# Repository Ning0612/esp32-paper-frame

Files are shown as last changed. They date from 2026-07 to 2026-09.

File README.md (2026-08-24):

# PaperFrame

[English](README.en.md) | [繁體中文](README.md)








PaperFrame 是以 ESP32-S3 驅動 7.3 吋 800×480 E6 全彩電子紙的離線優先
圖片輪播裝置。韌體使用 PlatformIO 管理的原生 ESP-IDF，不依賴 Arduino
framework；圖片處理、設定與管理 WebUI 在區域網路或裝置 AP 內即可運作。

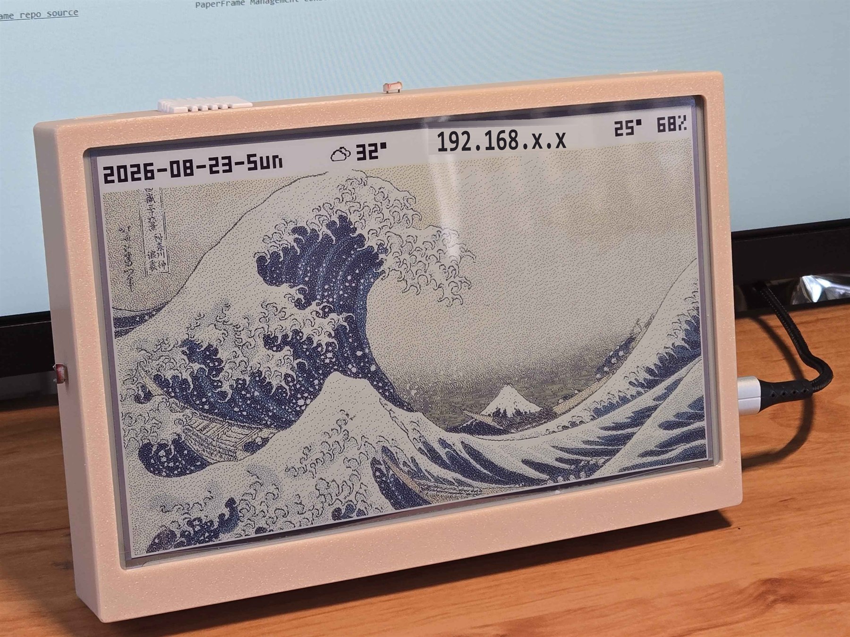
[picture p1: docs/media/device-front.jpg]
PaperFrame 實機：3D 列印相框中的 7.3 吋六色電子紙，狀態列顯示日期、天氣、IP 與室內溫溼度，下方是六色抖色後的《神奈川沖浪裏》


上圖是實機外觀，未經後製，只把狀態列上的區網位址遮成 `192.168.x.x`。狀態列
由左至右是日期與星期、目前天氣、裝置 IP 與 DHT22 的室內溫溼度；下方是輪播中
的圖片，這裡是公有領域的葛飾北齋《神奈川沖浪裏》經六色抖色後的實際顯示結果
（[出處](ASSET_CREDITS.md)）。外殼 CAD 一併收錄於
[`hardware/enclosure/`](hardware/enclosure/)，也附在每個 release 的 assets。

> **與其他 e-paper 專案的關係**
>
> PaperFrame 與 [epaper-home-display](https://github.com/Ning0612/epaper-home-display)
> （Raspberry Pi 多資訊智慧家庭面板）、[pico-paper-clock](https://github.com/Ning0612/pico-paper-clock)
> （Pico W／MicroPython 桌面時鐘）是**各自獨立維護的不同專案**，硬體平台、
> 韌體堆疊與用途都不同，彼此沒有取代關係。本專案的定位是 ESP32-S3 上的
> 離線優先全彩圖片輪播。
>
> 設計上借鑑了上述兩者與 [esp32-hydracup](https://github.com/Ning0612/esp32-hydracup)
> 的既有經驗（低記憶體串流、交易式檔案更新、FreeRTOS owner 邊界等），
> 採用的來源版本固定於 [參考來源與授權](docs/REFERENCES.md)。

## 管理介面

WebUI 全部資產（HTML／CSS／JS）都 gzip 後編進 app 韌體，不從任何 CDN 取得；
一次 OTA 會同時更新韌體與前端
（[ADR-0016](docs/adr/0016-embed-webui-assets-in-firmware.md)）。**唯一的例外是
天氣頁的地圖選點**：連得上網時會向 `tile.openstreetmap.org` 取圖磚（因此該頁
會把你選的位置附近座標揭露給該服務），連不上時同一個控制項自動改成純離線的
經緯度格線，其餘所有頁面完全不需要外部網路。以下截圖取自執行 v0.10.0 的實機。
管理介面上方導覽列現在也提供繁體中文／英文切換。

| 總覽 | 環境與在場 |
| --- | --- |
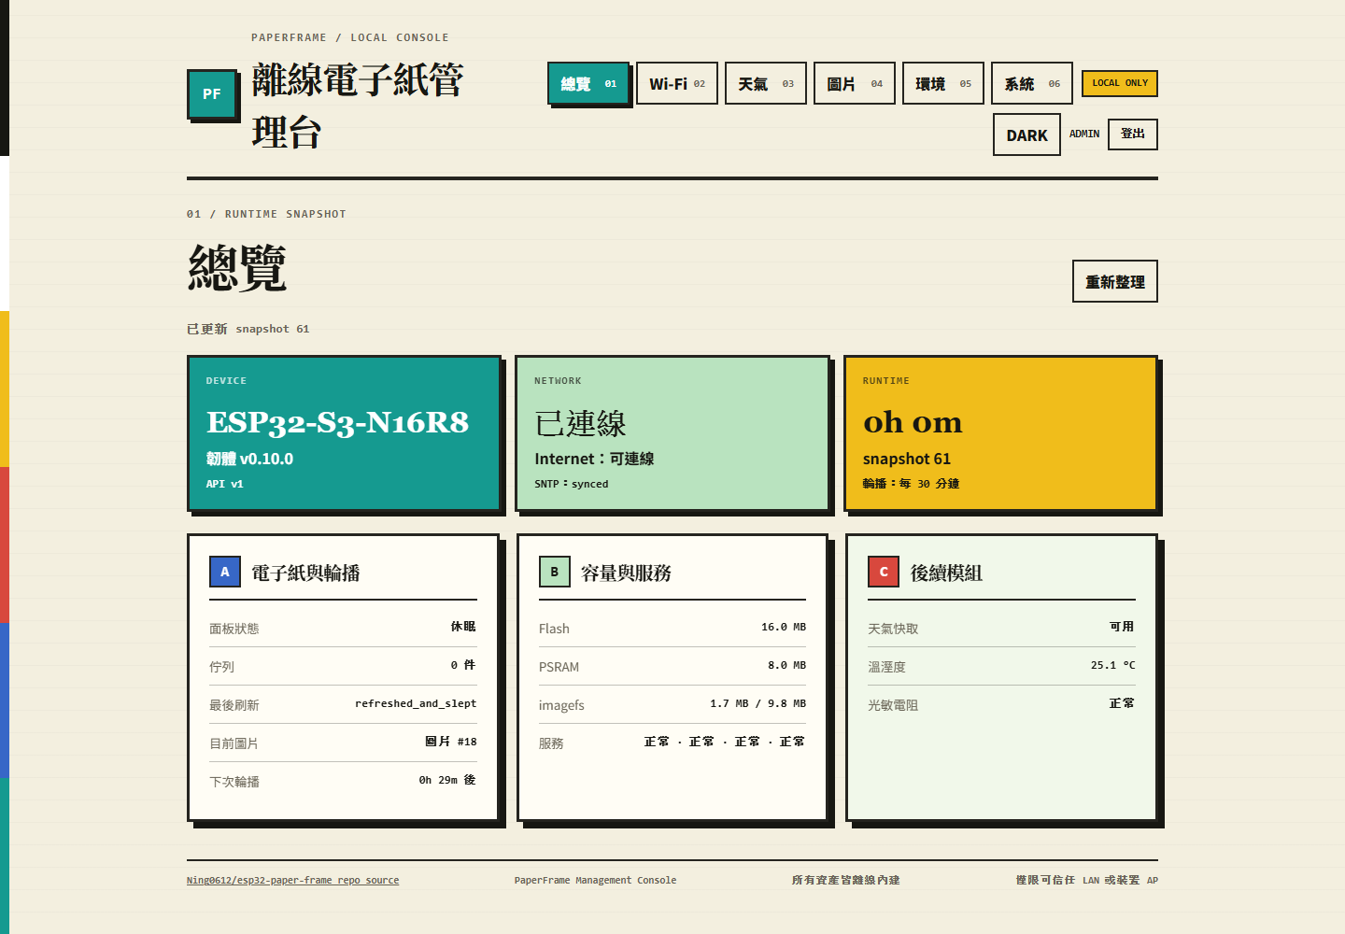
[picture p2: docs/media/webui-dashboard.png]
Dashboard
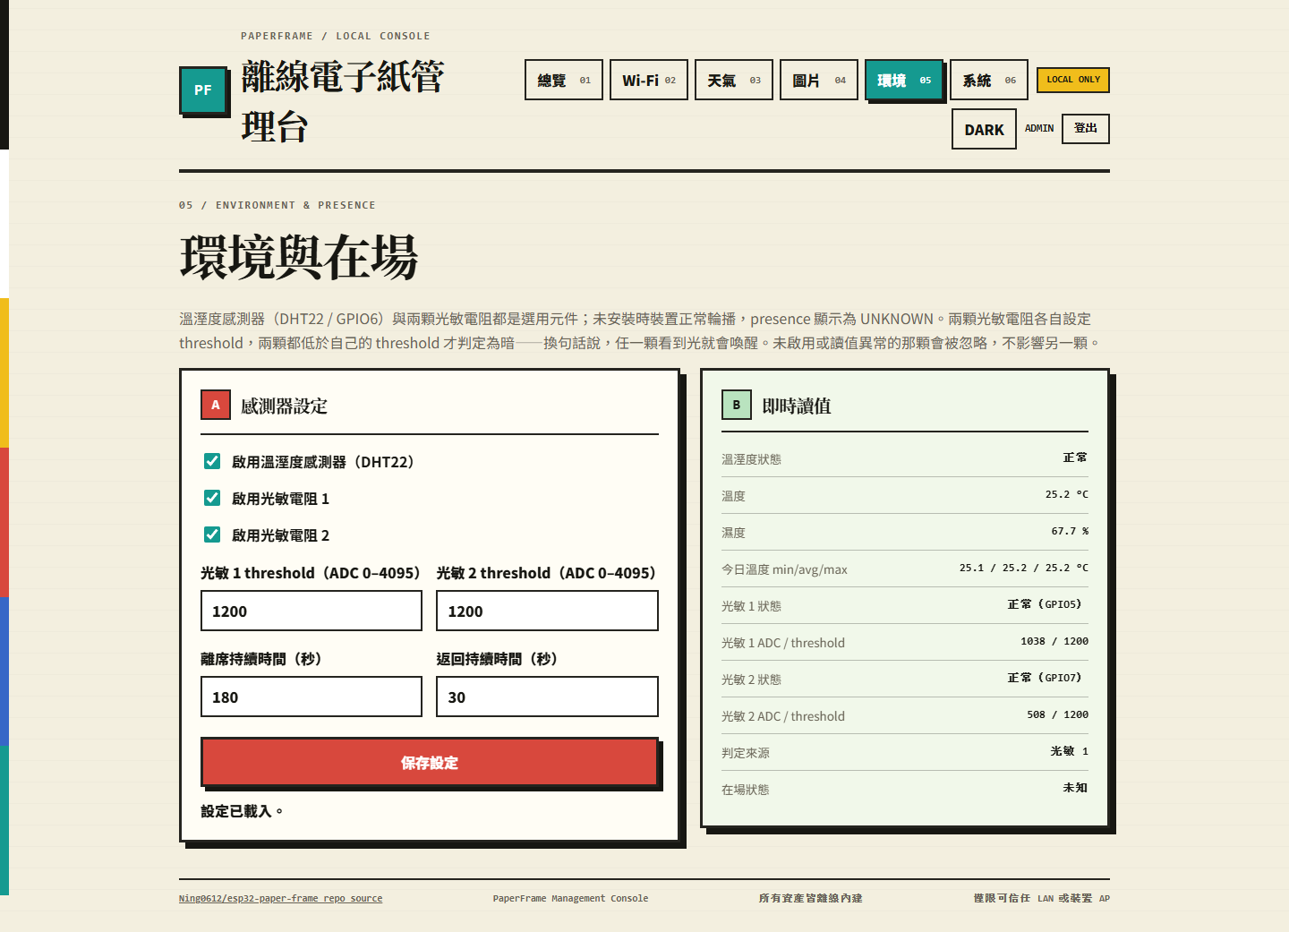
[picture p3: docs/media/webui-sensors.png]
環境與在場
|  |  |
| 面板狀態、輪播進度、容量與各服務健康度，全部來自單一 runtime snapshot。 | 兩顆光敏電阻各自設定 threshold 與即時讀值，並標示這次判定由哪一顆決定。 |

| 圖片處理 | 系統與韌體 |
| --- | --- |
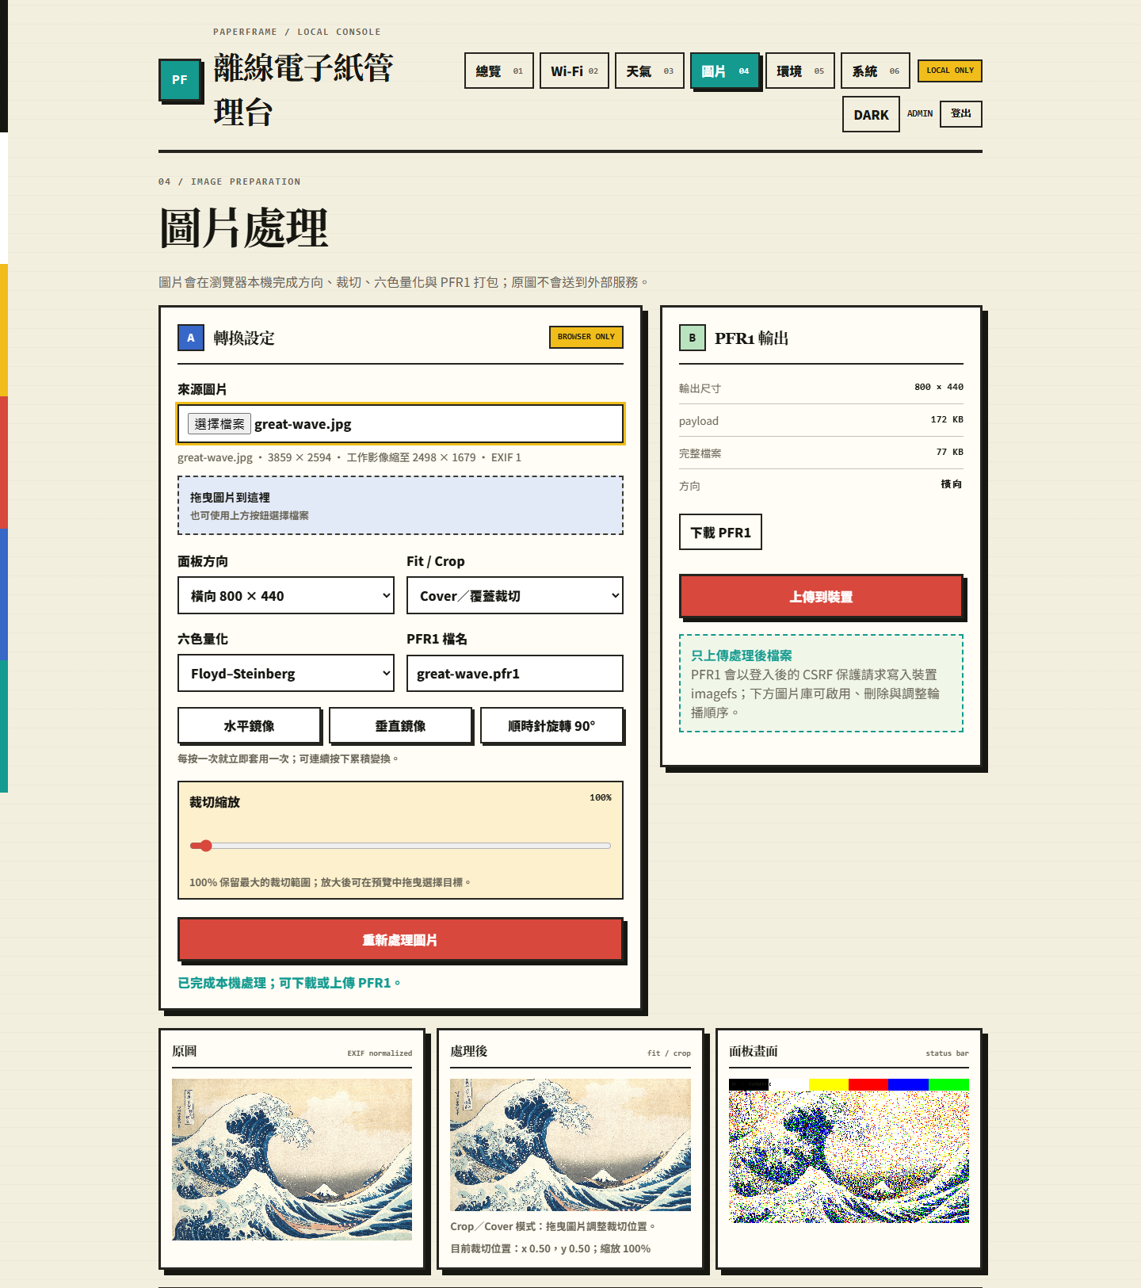
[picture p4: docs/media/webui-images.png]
圖片處理
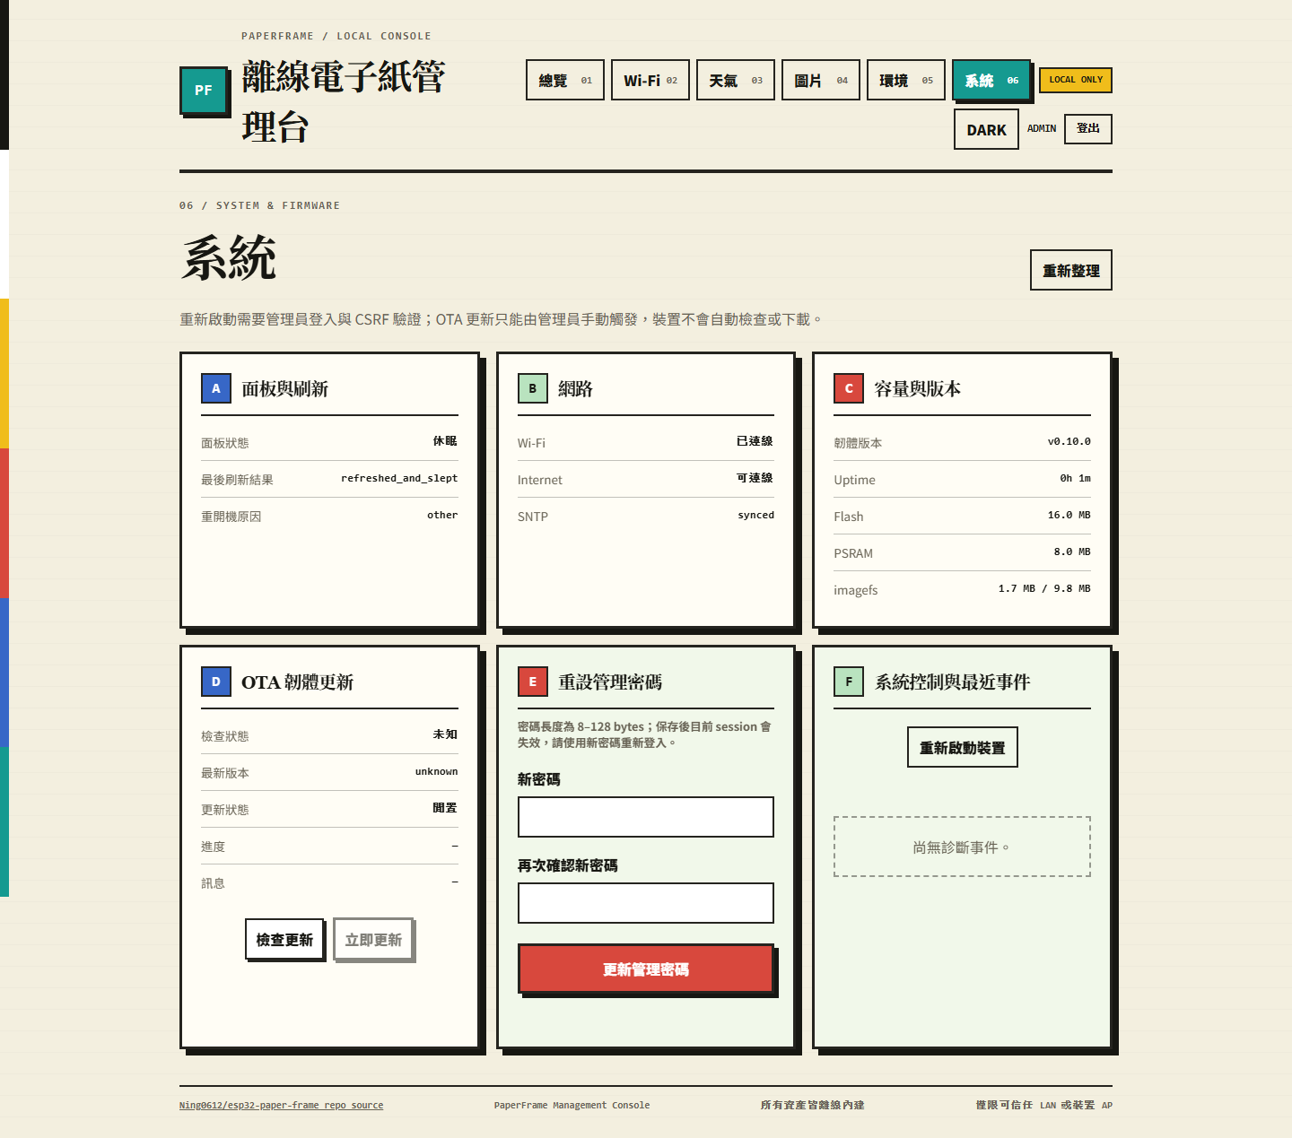
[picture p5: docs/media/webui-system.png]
系統
|  |  |
| 方向、裁切、六色量化與 PFR1 打包都在瀏覽器本機完成，原圖不會送到外部服務。範例圖為公有領域的葛飾北齋《神奈川沖浪裏》（[出處](ASSET_CREDITS.md)）。 | 面板與網路狀態、容量與版本、OTA 更新、重設管理密碼與診斷事件。 |

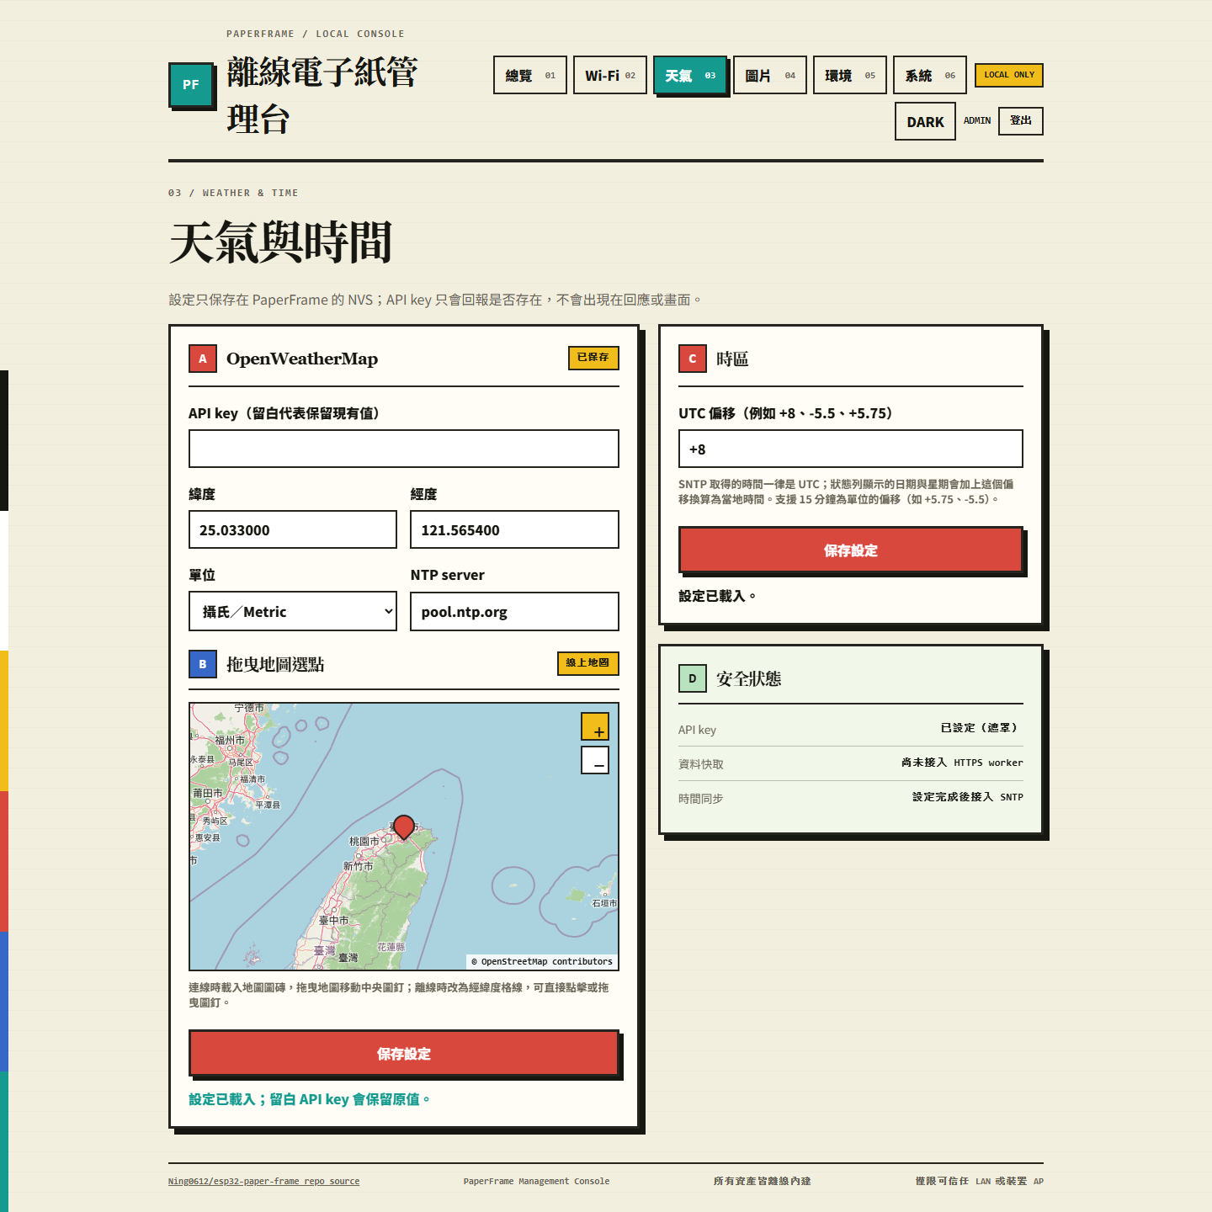
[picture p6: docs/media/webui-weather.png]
天氣與時間


天氣與時間頁：OpenWeatherMap 座標可直接在地圖上拖曳選點，離線時同一個
控制項改成經緯度格線；API key 只回報「是否已設定」，不會出現在任何回應或
畫面上。截圖中的座標是台北，不是實際部署位置。

## 目前狀態

目前狀態的唯一進度入口是 [專案狀態](docs/PROJECT_STATUS.md)，實機證據在
[硬體驗證紀錄](docs/hardware/VALIDATION.md)。摘要如下：

| 分類 | 目前結論 |
| --- | --- |
| MVP | **功能範圍已完成**並在實機使用中。**電源方案尚未設計**——目前直接接線供電，電池／低功耗運行未評估。 |
| 已完成 | Phase 1–8 的程式、host tests 與韌體 build 全部完成。 |
| 已實機驗證 | Phase 2–8 的**主要**路徑都有實機證據：面板刷新與 sleep 電流、AP／STA 配網與存取邊界、browser 出圖管線、五種斷電路徑、天氣四種失敗分類、OTA 端到端與 rollback fault injection，以及 Phase 7 的 DHT22、雙光敏通道與在場判定。這不代表每個 Phase 都沒有剩餘項目——見下一列。 |
| 待驗證 | 四個領域、八條路徑，都是低優先：`SensorSettings` v1→v2 的實機遷移與啟用但未接線通道的浮接讀值；presence 返回重畫、DHCP 續約後的位址重畫與 welcome 刷新失敗重試；AP grace 的 presence 例外與低 DMA heap guard；NVS 滿導致 `pf_config` 開啟失敗。 |
| 待決定 | production security profile（Secure Boot／Flash Encryption）與 MVP 以外的 P1 功能尚未納入開發。 |

2026-08-23 修掉兩個互相關聯的缺陷：刷新完成但面板 sleep 失敗時，結果讀起來
像「這次刷新沒成功」而導致重刷一張已經正確的畫面；以及每次開機 presence 由
`unknown` 收斂到 `present` 被當成「從離席返回」，白白多花一次 31 秒全刷。
修法見 [ADR-0019](docs/adr/0019-separate-frame-displayed-from-panel-slept.md)。
修正後的開機序列**已在實機確認只剩一次全刷**。

「實機證據已閉環」指的是那些行為已經在真實硬體上驗證過，**不等於 release
gate 已關閉**——[release checklist](docs/RELEASE_CHECKLIST.md) 的手動 on-device
檢查仍要每次依裝置狀況執行。Secure Boot 與 Flash Encryption 也尚未啟用，所以
這**不是**可直接放到不可信任網路的產品；設計前提是可信任 LAN 或裝置自身的 AP。

## 功能

括號內是**實機驗證狀態**。逐項證據以 [專案狀態](docs/PROJECT_STATUS.md) 與
[硬體驗證紀錄](docs/hardware/VALIDATION.md) 為準。

- **離線優先圖片輪播**：區網或裝置 AP 內即可完成全部操作，不依賴外部 CDN
  或後端服務（已驗證，含長時間輪播）。天氣功能本身需要 OpenWeatherMap，
  地圖選點需要 OSM 圖磚，兩者都是可停用的選配，停用後不影響輪播
- **PFR1 自有圖片格式**：瀏覽器端完成量化與打包，裝置只負責解碼與顯示，
  避免在 MCU 上做重量級影像處理（已驗證：browser 出圖、上傳與下載）
- **交易式 imagefs 儲存**：圖片分區與韌體分區分離，OTA 更新不會清除既有圖片
  （已驗證，含五種斷電路徑的故障注入）
- **管理 WebUI**：Dashboard、圖片管理、Wi-Fi、天氣、環境與 System 診斷頁，
  支援**繁體中文／英文語言切換**（已驗證：瀏覽器實機操作）
- **配網與認證**：AP portal 配網，blank-NVS 與 STA 重試耗盡時自動 fallback AP；
  PBKDF2 10,000 iterations、session 與 CSRF 保護（已驗證：存取邊界與認證邊界）
- **OTA 更新與 rollback**：以 GitHub Releases 為來源，A/B 分區與 rollback
  確認機制（已驗證：端到端更新與 rollback fault injection）
- **天氣資訊**：解析、快取與面板狀態列顯示（已驗證：真實 SNTP 與四種失敗分類）
- **可選環境感測**：DHT22 溫溼度與兩個獨立的光敏電阻通道。兩顆都低於各自
  threshold 才判定為暗、任一顆見光就喚醒；含移動平均濾波、離席／返回防抖與
  離席白屏（已驗證：讀值、拔除降級、雙通道校正、AND 語意與 180／30 秒防抖計時）

## 文件入口

請先讀 [文件入口與分類](docs/README.md)；若只想知道現在做到哪裡，讀
[專案狀態](docs/PROJECT_STATUS.md)。ADR、current contract、硬體證據與歷史
計畫的權威關係都集中在該入口說明，不需要從所有文件開始閱讀。

## 開源快速開始

開發環境需要 Windows 11、Python 3.13、PlatformIO Core 6.1.19 與原生 ESP-IDF。
在乾淨 checkout 中執行：

```powershell
uv venv --seed --python 3.13 .venv
uv pip install --python .\.venv\Scripts\python.exe -r requirements-dev.txt
.\.venv\Scripts\pio.exe test -e native
.\.venv\Scripts\pio.exe run
```

`native` 是不需要硬體的 host test；韌體 upload、面板、Wi-Fi、NVS、OTA 與
斷電復原則依 [燒錄操作](docs/hardware/FLASHING.md)、[硬體驗證紀錄](docs/hardware/VALIDATION.md)
與 [release checklist](docs/RELEASE_CHECKLIST.md) 執行。請勿把 host/build 結果
當成實機驗證。

**拿到全新板子時，`pio run -t upload` 不足以讓它開機**：日常上傳只寫 app slot，
不含 bootloader。首次燒錄與 bootloader 更新見
[新裝置首次燒錄](docs/hardware/FLASHING.md#新裝置首次燒錄含-bootloader)；
OTA 的回滾保護取決於 bootloader 版本，判斷方式見
[bootloader 是否具備回滾保護](docs/hardware/FLASHING.md#bootloader-是否具備回滾保護)。

## 硬體

完整元件清單、接線與腳位限制見 [硬體規格與接線](docs/hardware/HARDWARE.md)；
腳位分配的決策與理由固定在 [ADR-0003](docs/adr/0003-fix-phase2-display-integration.md)。
以下為常用摘要。

| 類別 | 元件 | 狀態 |
| --- | --- | --- |
| 主控 | ESP32-S3-N16R8（16 MB Flash、8 MB octal PSRAM） | 必要 |
| 顯示器 | Waveshare 7.3 吋 e-Paper HAT (E)，800×480 E6 六色 | 必要 |
| 溫溼度 | DHT22／AM2302 | 可選；已實機驗證 |
| 光感測 | 光敏電阻＋分壓 ×2，接 `ADC1_CH4` 與 `ADC1_CH6` | 可選；兩顆同時接線已實機驗證。**只接一顆時必須在 WebUI 停用另一顆**（[原因](docs/hardware/HARDWARE.md)） |
| 外殼 | 3D 列印，CAD 見 [`hardware/enclosure/`](hardware/enclosure/) | 可選 |
| 供電 | 直接接線（開發板 USB） | **尚未設計**；電池／低功耗運行未評估 |

顯示器接線（3.3 V logic、SPI2、mode 0、MSB-first、起始 clock 2 MHz）：

| HAT | DIN | CLK | CS | DC | RST | BUSY |
| --- | --- | --- | --- | --- | --- | --- |
| ESP32-S3 | GPIO11 | GPIO12 | GPIO10 | GPIO13 | GPIO14 | GPIO4 |

感測器腳位：光敏 ADC 通道 1 = GPIO5（`ADC1_CH4`）、DHT data = GPIO6、光敏 ADC
通道 2 = GPIO7（`ADC1_CH6`）；GPIO8／GPIO9 保留給未來 I²C。兩個光敏通道都必須
在 ADC1——ADC2 在 Wi-Fi 啟用時由 Wi-Fi driver 佔用。分壓接法、極性與校正流程見
[硬體與接線](docs/hardware/HARDWARE.md)，合併判定規則見
[ADR-0018](docs/adr/0018-dual-photoresistor-channels.md)。**改接線前務必先讀 ADR-0003 的腳位限制**——octal PSRAM 佔用
GPIO33–37、native USB 佔用 GPIO19–20，GPIO0／3／45／46 是 strapping pins，
GPIO4 已給 BUSY 不得再作 ADC。

### 外殼

[`hardware/enclosure/`](hardware/enclosure/) 收錄桌上型相框外殼，每個零件同時
提供 **STEP（AP214）** 與 **STL**：STEP 用來改尺寸或重新出圖，STL 直接送切片
軟體。零件清單、量到的外接方框尺寸與已知問題見
[該目錄的 README](hardware/enclosure/README.md)。同一份內容也會以
`paperframe-enclosure.zip` 附在每個 GitHub Release 的 assets。

六個零件的檔名前綴就是組裝堆疊順序，列印與組裝可以照號碼走。

## 架構概覽

韌體拆成 12 個 ESP-IDF component，`src/app_main.cpp` 只負責啟動與接線。
跨 component 的協調集中在 `pf_runtime` 的 `RuntimeCoordinator`：顯示、儲存、
網路與 OTA 各自有明確的 owner，彼此以訊息往來而不是共享可變狀態，避免網路或
儲存 I/O 阻塞面板刷新。

各 component 的設計理由與取捨固定在 [ADR](docs/adr/README.md)，本節只是導覽。

| Component | 職責 |
| --- | --- |
| `pf_runtime` | `RuntimeCoordinator`、runtime snapshot、diagnostics event、reboot reason、韌體版本 |
| `pf_display` | epd7in3e driver（SPI2）、DisplayTask、owner contract |
| `pf_carousel` | 輪播排程、image frame 與 welcome frame |
| `pf_image` | PFR1 格式解碼 |
| `pf_storage` | LittleFS backend、image store、catalog、transaction 與 recovery、storage worker |
| `pf_network` | AP／STA 狀態機、配網服務、掃描結果、SNTP 時間同步 |
| `pf_web` | HTTP server、Dashboard／health serializer、各設定表單、access policy |
| `pf_auth` | PBKDF2 密碼驗證、session 與 CSRF |
| `pf_config` | NVS 設定 schema、憑證與 secure memory |
| `pf_ota` | GitHub Releases 下載、A/B 分區與 rollback 確認 |
| `pf_weather` | 天氣解析、快取與 worker |
| `pf_sensors` | DHT22 與光敏 ADC driver、濾波與 presence 判定 |

測試分兩層：`test/` 是不需要硬體的 host test（`pio test -e native`），
`test_embedded/` 是需要實機的 on-target test。**host test 通過不等於實機驗證**，
兩者的分界與現況見 [硬體驗證紀錄](docs/hardware/VALIDATION.md)。

## 公開基線與已知限制

- 目標基線是 ESP32-S3-N16R8、16 MB Flash、8 MB octal PSRAM 與 7.3 吋
  800×480 E6 全彩電子紙；光敏與溫溼度感測器是可選周邊（見上方硬體段）。
- WebUI 與圖片管理以離線優先為原則：所有前端資產編在韌體裡，圖片處理在
  瀏覽器本機完成。唯一會連外的是天氣頁的地圖選點（OSM 圖磚）與天氣抓取
  本身，兩者都可停用，停用後整套功能仍可在無網際網路的區網內運作。
- 電子紙完整刷新預設 30 分鐘，可設 10 分鐘至 24 小時（1440 分鐘）；實測一次
  全刷約 31 秒，每次刷新後面板進入 sleep。31 秒是 E6 面板的物理特性，不是
  可調優的軟體延遲。
- 未啟用 Secure Boot 與 Flash Encryption，僅適用於可信任 LAN 或裝置自身的 AP。
- 仍有八條低優先的實機驗證路徑未閉環（見上方目前狀態）。
- 真實裝置測試資料、裝置識別資訊與執行期 imagefs 不屬於公開 repository 內容。

## 開發基線

- Windows 11 / PowerShell 7
- [uv](https://docs.astral.sh/uv/getting-started/installation/) 0.11.26
- Python 3.13 project venv
- PlatformIO Core 6.1.19
- PlatformIO Espressif 32 platform（版本由 Phase 1 build 固定）
- Native ESP-IDF

上列是實際使用並通過 build 的組合。**Linux 與 macOS 未測試**——工具鏈本身跨平台，
但本專案的指令範例、`uv` 路徑與燒錄流程都以 Windows 為準，其他平台需自行調整。
CI 在 `ubuntu-latest` 上跑 host test 與韌體 build，所以程式本身可在 Linux 編譯，
未測試的是本文件描述的 Windows 操作流程。

建立工具環境：

```powershell
uv venv --seed --python 3.13 .venv
uv pip install --python .\.venv\Scripts\python.exe -r requirements-dev.txt
.\.venv\Scripts\pio.exe --version
```

韌體的標準 build、native USB 單命令 upload 與 port 盤點命令：

```powershell
.\.venv\Scripts\pio.exe run
.\.venv\Scripts\pio.exe run -e paperframe-s3 -t upload
.\.venv\Scripts\pio.exe device list
```

標準 upload 會依 VID:PID `303A:1001` 自動選擇 ESP32-S3 native USB，以
`usb_reset` 進入 ROM，讀取 `otadata` 後更新目前啟動的 OTA app slot，完成後
自動重置。首次、RGB demo 或 app 損壞無法自動 reset 時，才需在 reset 同時拉低
GPIO0、GPIO46。完整安全步驟、app-only slot 限制與測試後恢復方式見
[ESP32-S3 燒錄操作](docs/hardware/FLASHING.md)。

這條路徑**不會更新 bootloader 或 partition table**——新板子的首次燒錄、以及
既有裝置要取得 OTA 回滾保護時的 bootloader 更新，都在同一份文件的
[新裝置首次燒錄](docs/hardware/FLASHING.md#新裝置首次燒錄含-bootloader)一節。

## 文件

- [文件入口與分類](docs/README.md)
- [專案狀態](docs/PROJECT_STATUS.md)
- [架構決策](docs/adr/README.md)
- [硬體規格與接線](docs/hardware/HARDWARE.md)
- [硬體驗證紀錄](docs/hardware/VALIDATION.md)
- [外殼 CAD](hardware/enclosure/README.md)
- [參考來源與授權](docs/REFERENCES.md)
- [歷史需求草案](docs/archive/Guild.md)

## License

本專案採用 [MIT License](LICENSE)。參考專案與未來第三方 dependency 的授權
仍需分別遵守；參考概念不代表可省略原始碼 attribution 或第三方 notice。
韌體內建的天氣圖示改繪自 erikflowers/weather-icons（SIL OFL-1.1），
attribution 見 [ASSET_CREDITS.md](ASSET_CREDITS.md) 與
[THIRD_PARTY_NOTICES.md](THIRD_PARTY_NOTICES.md)。

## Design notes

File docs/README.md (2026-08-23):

# 文件入口與分類

PaperFrame 的文件分成「目前狀態」、「現行契約」、「設計決策」、「實機證據」
與「歷史背景」。一般讀者不需要從所有文件開始閱讀。

## 主要文件

按以下順序即可掌握專案：

1. [根目錄 README](../README.md)：專案用途、開源快速開始與公開限制。
2. [PROJECT_STATUS.md](PROJECT_STATUS.md)：唯一的完成／待驗證／待決定摘要。
3. [ADR index](adr/README.md)：為什麼採用目前架構、格式與安全決策。
4. [RELEASE_CHECKLIST.md](RELEASE_CHECKLIST.md)：公開版的 release gate。
5. [CONTRIBUTING.md](../CONTRIBUTING.md) 與 [SECURITY.md](../SECURITY.md)：如何參與與回報問題。

## 只有在修改該領域時才讀

這些文件是現行 contract，不是進度清單：

- [AUTHENTICATION.md](AUTHENTICATION.md)、[PROVISIONING.md](PROVISIONING.md)
- [WEBUI.md](WEBUI.md)、[HEALTH_API.md](HEALTH_API.md)
- [STORAGE.md](STORAGE.md)、[WEATHER.md](WEATHER.md)
- [formats/PFR1.md](formats/PFR1.md)、[formats/PFC1.md](formats/PFC1.md)

## 硬體規格

- [hardware/HARDWARE.md](hardware/HARDWARE.md)：元件清單、接線與腳位限制，
  回答「要買什麼、怎麼接」。**它不是決策權威**——腳位分配的理由固定在
  [ADR-0003](adr/0003-fix-phase2-display-integration.md)、感測器行為在
  [ADR-0006](adr/0006-sensor-drivers-and-presence.md)（光敏電阻的雙通道
  部分已由 [ADR-0018](adr/0018-dual-photoresistor-channels.md) 取代），
  衝突時以 ADR 為準。
  根目錄 README 的「硬體」段是本檔摘要；**重要資訊刻意在兩處重複**，
  讓讀者不必先點進 docs 才知道要買什麼板子。

## 證據與操作

- [hardware/VALIDATION.md](hardware/VALIDATION.md)：append-only 實機證據與目前未閉環項目。
- [hardware/FLASHING.md](hardware/FLASHING.md)：燒錄與 imagefs 保護操作，
  包含**新裝置首次燒錄**（日常 upload 只寫 app slot，不含 bootloader，
  空白板無法只靠它開機）與**判斷 bootloader 是否具備 OTA 回滾保護**。

- [../hardware/enclosure/README.md](../hardware/enclosure/README.md)：3D 列印外殼的零件清單、量到的尺寸與已知問題；CAD 本體（STEP／STL）
  與韌體一起附在每個 GitHub Release 的 assets。

這兩份文件回答「實際測了什麼」與「如何操作」，不取代
[PROJECT_STATUS.md](PROJECT_STATUS.md) 的進度摘要。

## 歷史與參考

- [Guild.md](archive/Guild.md)：原始需求 provenance，不是現行規格。
- [IMPLEMENTATION_PLAN.md](archive/IMPLEMENTATION_PLAN.md)：階段、acceptance 與開發歷史，
  不取代 current contract 或本文件的狀態摘要。
- [REFERENCES.md](REFERENCES.md)、[ASSET_CREDITS.md](../ASSET_CREDITS.md) 與
  [THIRD_PARTY_NOTICES.md](../THIRD_PARTY_NOTICES.md)：來源與授權追溯。

## 目前刻意保留在主文件區

- `hardware/VALIDATION.md`：頂端有目前未閉環索引，後面的 append-only 紀錄仍是可追溯的實機證據；不把整份移入 archive。
- `hardware/FLASHING.md` 與 `RELEASE_CHECKLIST.md`：仍會直接用於燒錄、驗證與發布，屬於現行操作文件。
- ADR：目前 18 份都是已接受的公開設計決策；即使部分決策後來被新 ADR 取代，也要保留決策歷史，不搬到 archive。
- `REFERENCES.md`、`ASSET_CREDITS.md`、`THIRD_PARTY_NOTICES.md`：授權與 provenance 是開源交付的一部分，不是過時開發計畫。
- `AUTHENTICATION.md`、`PROVISIONING.md`、`WEBUI.md`、`HEALTH_API.md`、`STORAGE.md`、`WEATHER.md` 與 `formats/`：描述目前仍有效的外部行為與資料格式。

若日後仍需要縮短硬體紀錄的日常閱讀範圍，可再把較早的 append-only 歷史段落拆成
`docs/archive/`，但必須保留 `VALIDATION.md` 的目前未閉環索引與指向歷史證據的連結。

新增文件前，先確認內容不能放入上述既有分類；避免建立另一份**進度表**或重複的
**API／硬體驗證說明**。

**重複的界線**：常用且會影響「要不要動手」的資訊——例如買什麼板子、接哪幾支腳、
現在能不能宣稱 production-ready——**允許在根目錄 README 與 `docs/` 同時出現**，
讓讀者不必層層點進來才看得到。但必須符合兩個條件：

1. 明確標示哪一份是權威（決策以 ADR 為準、進度以 `PROJECT_STATUS.md` 為準、
   實機證據以 `VALIDATION.md` 為準），摘要處註明它是摘要；
2. 改動時兩處一起改——摘要與權威來源不一致，比沒有摘要更糟。

不適用於進度狀態與實機驗證結果：那兩類只在單一入口維護，其他地方一律用連結。

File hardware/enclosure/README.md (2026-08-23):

# PaperFrame 相框外殼 CAD

7.3 吋 800×480 E6 電子紙桌上型相框的外殼素材，SolidWorks 2019 建模，
每個零件同時提供 **STEP（AP214）** 與 **STL**：STEP 用來改尺寸或重新出圖，
STL 直接送切片軟體列印。組裝後的實機外觀見
[README 的實機照片](https://github.com/Ning0612/esp32-paper-frame/blob/main/docs/media/device-front.jpg)。

## 組裝順序

檔名前綴就是堆疊順序，由面板側往背面依序疊上去：

```
01 螢幕背板殼
   └─ 電子紙面板
02 相框外框
03 電子零件背板
   └─ 電子零件（ESP32-S3、感測器、配線）
04 腳架旋轉件
05 相框背板
06 腳架
```

## 零件

尺寸是從 STL 幾何量出來的外接方框（bounding box，單位 mm），不是標稱設計值。

| 檔名 | 零件 | 外接方框 (X×Y×Z) |
| --- | --- | --- |
| `01-screen-back-shell` | 螢幕背板殼 | 176 × 116 × 3 |
| `02-outer-frame` | 相框外框 | 180 × 120 × 26 |
| `03-electronics-back-panel` | 電子零件背板 | 176 × 116 × 4 |
| `04-stand-pivot` | 腳架旋轉件 | 16 × 11 × 16 |
| `05-frame-back-panel` | 相框背板 | 176 × 120 × 19 |
| `06-stand` | 腳架 | 30 × 88 × 4 |

原始檔名對照（重新命名前）：

| 目前檔名 | 原始檔名 |
| --- | --- |
| `01-screen-back-shell` | `epaper-screen-1` |
| `02-outer-frame` | `epaper-screen-2` |
| `03-electronics-back-panel` | `epaper-screen-4` |
| `04-stand-pivot` | `epaper-screen-5` |
| `05-frame-back-panel` | `epaper-screen-3` |
| `06-stand` | `epaper-screen-6` |

## 已知限制

- 列印材料、層高、填充率與支撐設定尚未記錄。
- 上表尺寸取自 STL 的三角網格，是實際會列印出來的幾何。**STEP 與 STL 是否
  完全等價未經逐面比對**——本專案沒有 CAD kernel 可以做這件事，只確認過兩者
  的外形尺寸一致。

## 授權

與本 repository 相同（MIT），見 [LICENSE](https://github.com/Ning0612/esp32-paper-frame/blob/main/LICENSE)。

本檔會與 CAD 一起打包成 GitHub Release 的 `paperframe-enclosure.zip`，
所以上面的連結刻意用絕對網址——解壓後的資料夾沒有 repository 的目錄結構。

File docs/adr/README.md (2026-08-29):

# Architecture Decision Records

會影響硬體接線、partition、持久資料格式、跨 task ownership、安全邊界或
對外 API 的決策，使用 ADR 固定。小型實作細節留在程式與測試，不為每個
函式建立 ADR。

## 與其他文件的權威關係

已接受且未被取代的 ADR 是跨模組、硬體、持久格式與安全決策的權威來源；
新 ADR 取代舊決策時，必須保留歷史檔案並明確標示 `Supersedes`。目前 API、
WebUI、儲存、天氣、認證與 binary format 的操作契約位於 `docs/` 主題文件；
`docs/archive/IMPLEMENTATION_PLAN.md` 只做追溯，`hardware/VALIDATION.md` 只做證據
紀錄，`docs/archive/Guild.md` 只保留原始需求 provenance。

## 開源公開範圍

ADR 是本專案的公開設計決策歷史，建議保留在開源 repository。公開 ADR 應
說明已接受、被取代或拒絕的決策、影響範圍與理由，讓貢獻者理解「為什麼」
而不只看到目前的實作。

ADR 不應包含密碼、API key、session token、Wi-Fi credential、真實裝置識別、
私人路徑或未脫敏的內部 log。原始討論、私人測試紀錄與尚未形成決策的草稿
應留在 repository 外；被取代的 ADR 可保留，但必須標明 superseded 與取代它的
文件。開源貢獻流程請見根目錄的 `CONTRIBUTING.md`。

## 命名

```text
NNNN-short-imperative-title.md
```

編號遞增且不重用。已接受 ADR 不原地改寫結論；若決策改變，以新 ADR
取代並在兩份文件互相連結。

## 必要段落

```markdown
# ADR-NNNN：標題

- Status: proposed | accepted | superseded
- Date: YYYY-MM-DD
- Supersedes: none | ADR-NNNN

## Context
## Decision
## Consequences
## Verification
```

## Index

- [ADR-0001：建立專案技術與授權基線](0001-project-foundations.md)
- [ADR-0002：固定 ESP32-S3-N16R8 開發 profile](0002-esp32-s3-n16r8-profile.md)
- [ADR-0003：固定 Phase 2 顯示器接線與 driver contract](0003-fix-phase2-display-integration.md)
- [ADR-0004：凍結 imagefs-preserving partition layout](0004-freeze-image-preserving-partitions.md)（layout 與其 SHA-256 仍有效；`webfs` 的用途已由 ADR-0016 改為 reserved）
- [ADR-0005：WeatherWorker HTTPS 契約與狀態列渲染基線](0005-weather-worker-and-status-bar.md)（「字型與圖示授權」的圖示部分已被 ADR-0013 取代；「Rate limit / 更新頻率」子決策與 location/language 欄位已被 ADR-0014 取代）
- [ADR-0006：感測器 driver 來源與在場/離席判定機制](0006-sensor-drivers-and-presence.md)（單一光敏電阻的判定與 `GET /api/v1/sensors` 的 `light` schema 已被 ADR-0018 取代）
- [ADR-0007：PBKDF2 迭代次數與同步登入決策（G6 收斂）](0007-auth-pbkdf2-iterations-and-sync-login.md)
- [ADR-0008：OTA 韌體來源、TLS 信任、Rollback 確認時機與 Release 慣例](0008-ota-github-releases-and-rollback.md)（Context 第 1 條「OTA 不做 webfs」已被 ADR-0016 取代）
- [ADR-0009：PFR1 Payload 壓縮與 PFC1 目錄容量上限](0009-pfr1-payload-compression-and-catalog-cap.md)（`kCatalogMaxEntries` 部分已被 ADR-0010 取代）
- [ADR-0010：撤銷 PFC1 目錄容量上限拉高，維持 48 筆](0010-revert-catalog-cap-raise-ram-constraint.md)
- [ADR-0011：PFR1 壓縮功能的 PSRAM／flash cache-disable 交錯安全性調查](0011-psram-flash-cache-disable-safety.md)
- [ADR-0012：RAM 重構後重新拉高 PFC1 目錄容量上限至 64 筆](0012-raise-catalog-cap-after-ram-reclaim.md)（取代 ADR-0010 的 `kCatalogMaxEntries` 部分）
- [ADR-0013：天氣圖示改用轉檔自第三方 OFL-1.1 素材的點陣圖](0013-weather-icon-bitmaps-from-third-party-ofl-source.md)（取代 ADR-0005「字型與圖示授權」的圖示部分）
- [ADR-0014：天氣更新改為面板刷新觸發，WebUI 改用地圖選點](0014-weather-panel-refresh-cadence-and-map-picker.md)（取代 ADR-0005「Rate limit / 更新頻率」子決策與 location/language 欄位）
- [ADR-0015：開機首張真實圖片等待 NTP／天氣就緒或逾時](0015-first-image-waits-for-ntp-and-weather.md)（Update 2026-08-23：空圖庫的 welcome frame 在取得區網 IP 後重畫一次）
- [ADR-0016：WebUI 資產 gzip 後編入 app image，webfs 分割區轉為 reserved](0016-embed-webui-assets-in-firmware.md)（取代 ADR-0008 Context 第 1 條）
- [ADR-0017：設定載入的降級邊界與中央記錄的寫入規則](0017-config-degradation-boundaries.md)
- [ADR-0018：光敏電阻擴充為兩個獨立通道，兩顆都變暗才判定為暗](0018-dual-photoresistor-channels.md)（取代 ADR-0006 的單一光敏判定與 `light` schema；增修 ADR-0003 的 G2 保留腳位表）
- [ADR-0019：把「畫面已上到面板」與「面板已進入 deep sleep」分開回報](0019-separate-frame-displayed-from-panel-slept.md)（取代 ADR-0003 Verification 的「成功 result 只能在 driver 回報 deep sleep 後發布」；driver 行為本身不變）
- [ADR-0020：光敏電阻 ADC 飽和只是診斷資訊，不再排除離席判定](0020-light-clip-is-diagnostic-not-presence-gate.md)（取代 ADR-0006／ADR-0018 的「saturated 不得觸發離席」條款，`saturated` 列舉值拆分為 `low_clipped`／`high_clipped`）

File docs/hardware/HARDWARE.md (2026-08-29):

# 硬體規格與接線

本文件回答「要買什麼、怎麼接」。**它不是設計決策的權威來源**——腳位分配、
SPI 參數與 driver 契約的決策與理由固定在
[ADR-0003](../adr/0003-fix-phase2-display-integration.md)，感測器行為固定在
[ADR-0006](../adr/0006-sensor-drivers-and-presence.md)。兩者衝突時以 ADR 為準。

實機驗證狀態見 [硬體驗證紀錄](VALIDATION.md)，燒錄步驟見
[燒錄操作](FLASHING.md)。

## 元件清單

| 類別 | 元件 | 規格 | 狀態 |
| --- | --- | --- | --- |
| 主控 | ESP32-S3 開發板 | **ESP32-S3-N16R8**：16 MB Flash、8 MB octal PSRAM | 必要。octal PSRAM 是目標基線，framebuffer 與圖片處理依賴它 |
| 顯示器 | Waveshare 7.3 吋 e-Paper HAT (E) | 800×480、E6 六色（黑／白／黃／紅／藍／綠） | 必要。產品與接線說明見 [官方 manual](https://www.waveshare.com/wiki/7.3inch_e-Paper_HAT_%28E%29_Manual) |
| 溫溼度感測器 | DHT22／AM2302 | 3.3 V 供電，單線資料 | **可選**。2026-08-23 已完成實機驗證（讀值與拔除降級） |
| 光感測器 | 光敏電阻（LDR）＋分壓電路 **×2** | 通道 1 輸出接 `ADC1_CH4`、通道 2 接 `ADC1_CH6` | **可選**，但只接一顆時必須在 WebUI 停用另一顆（見下方「只接一顆」）。兩顆同時接線已於 2026-08-23 完成實機驗證 |
| 外殼 | 3D 列印外殼 | — | 可選。STEP／STL 見 [`hardware/enclosure/`](../../hardware/enclosure/README.md)，並附在每個 GitHub Release 的 assets |
| 供電 | — | — | **尚未設計**。目前直接接線供電（開發板 USB），電池／UPS 與低功耗運行模式都未評估 |

> 標為「可選」的周邊未安裝時，韌體回傳 JSON `null` 而非 `0`，Dashboard 顯示
> 「未安裝／未啟用」——這是 [ADR-0006](../adr/0006-sensor-drivers-and-presence.md)
> 的明確決策，不要用 `0` 代替缺席。

## 接線

HAT 與 ESP32-S3 全部使用 **3.3 V logic**。

### 顯示器（SPI2）

| HAT 訊號 | ESP32-S3 | 用途 |
| --- | --- | --- |
| VCC | 3V3 | 電源 |
| GND | GND | 共地 |
| DIN | GPIO11 | SPI2 MOSI |
| CLK | GPIO12 | SPI2 SCK |
| CS | GPIO10 | chip select，低有效（由 SPI master hardware 控制） |
| DC | GPIO13 | data／command |
| RST | GPIO14 | panel reset，低有效 |
| BUSY | GPIO4 | panel status input，低電位為 busy |

SPI 參數：SPI2、mode 0、MSB-first、起始 clock 2 MHz。2 MHz 是 upstream 各平台
設定不一致時採取的保守值；**只有實機波形與刷新驗證通過後才能提高**（ADR-0003）。

### 感測器腳位

| 用途 | ESP32-S3 |
| --- | --- |
| 光敏電阻 ADC 通道 1 | GPIO5（`ADC1_CH4`） |
| DHT data | GPIO6 |
| 光敏電阻 ADC 通道 2 | GPIO7（`ADC1_CH6`）（ADR-0018） |
| I²C SDA | GPIO8（保留給未來 I²C 感測器） |
| I²C SCL | GPIO9（保留給未來 I²C 感測器） |

兩個光敏通道**都必須在 ADC1**：ESP32-S3 的 ADC2 在 Wi-Fi 啟用時由 Wi-Fi
driver 佔用，`adc_oneshot_read()` 會回 `ESP_ERR_TIMEOUT`。本裝置 Wi-Fi 常駐，
ADC2 等於不可用。ADC1 只涵蓋 GPIO1–GPIO10。若 GPIO7 因排針佈局不便，備援是
GPIO1（`ADC1_CH0`）或 GPIO2（`ADC1_CH1`）。改腳位要**同時**改兩處：
`sensor_task_esp_idf.cpp` 的 `kLightAdcChannels`（實際讀哪個 ADC 通道）與
`light_sensor.hpp` 的 `kLightChannelGpios`（API 與 WebUI 回報哪支腳）。
兩者是同一支腳的兩種說法，只改一邊會讓顯示與實際接線不符。

#### 只接一顆光敏電阻時

**必須在 WebUI 的環境頁把沒有接線的那個通道取消勾選。** 這不是最佳化，
是必要步驟：

- 停用是 `SensorTask` 取樣迴圈的第一個分支，該通道的 ADC **完全不會被讀**，
  浮接與否都無所謂；合併判定也會忽略它（`combine_light_channels()` 在還有
  其他 decision-capable 通道時跳過已停用／未偵測到／讀取錯誤的通道）。
- 啟用但沒接線時**沒有防線**：`raw ≤ 10` 或 `raw ≥ 4085` 只回報
  `low_clipped`／`high_clipped`，仍然照常餵入判定
  （[ADR-0020](../adr/0020-light-clip-is-diagnostic-not-presence-gate.md)——
  clip 只是診斷資訊，不再讓通道退出判定）。**未接線的 ADC 腳也不保證落在
  這個區間**——ESP32-S3 的 ADC 輸入沒有內部上下拉，分壓電路不在時該腳是
  高阻抗，實際讀到的是飄動的中間值，韌體無法與真實讀值區分，一樣會被當成
  `online` 參與判定。
- 失效模式是不對稱的。合併規則是 AND（兩顆都低於各自 threshold 才算暗），
  所以浮接值（不論落在中間值還是剛好貼到某一端）若解讀成高於 threshold，
  那顆會永遠看起來「有光」，**裝置將永遠不會進入離席白屏，而且不會有任何
  錯誤訊息**。解讀成低於 threshold 反而無害，因為真正接著的那顆說了算。

每通道各自的 enable 就是為了這個情境而存在（[ADR-0018](../adr/0018-dual-photoresistor-channels.md)）。

#### 光敏電阻分壓接法

兩顆各自一組分壓，**不共用固定電阻**——共用會讓兩路互相拉動，讀值失去獨立性：

```
   通道 1                        通道 2
     3V3                           3V3
      │                             │
    LDR-1                         LDR-2
      │                             │
      ├──────► GPIO5                ├──────► GPIO7
      │                             │
    R_fix-1                       R_fix-2
      │                             │
     GND                           GND
```

兩路完全分離：各自一顆 LDR、各自一顆 `R_fix`，只共用 3V3 與 GND。
**同一個分壓節點不可同時接到 GPIO5 與 GPIO7**——那樣兩個 ADC 讀到的是同一個
訊號，兩組 threshold 與 AND 判定就沒有意義了。

可選的抑制雜訊電容也是各自一顆：由各自的 ADC 節點對 GND 接 100nF，
貼近 ESP32 的腳位。

**上下順序不可反接**：韌體判定的極性是「亮→讀值高、暗→讀值低」——`online`
狀態下具體比較式是 `filtered_raw < threshold → 暗`，貼著兩端極限時
（`low_clipped`／`high_clipped`）改由狀態直接決定方向而不比較 threshold
（見「光敏電阻分壓接法」一節下方與 [ADR-0020](../adr/0020-light-clip-is-diagnostic-not-presence-gate.md)），
但極性本身仍然一致。LDR 在上、固定電阻在下正好符合這個極性；反接會使
判定語意顛倒。

`R_fix` 目前採用 **100 kΩ**（兩通道皆同值；2026-08-27 由 47 kΩ 換上——
兩通道各自獨立接線，不是共用電阻，只是剛好又選到同一個值）。

2026-08-23 曾以 10 kΩ 驗證，足以分辨開燈與關燈，但全暗環境會貼到 ADC
底部（實測 raw ≤23，其中一通道直接 `saturated`），presence 因此在深暗
環境有塌成 `unknown`、離席白屏被取消的風險。2026-08-24 換成 47 kΩ，
當時實測全暗 777–781、兩端都有餘裕。**但這組 47 kΩ 的餘裕在同一批 LDR
上並不穩定**：2026-08-27 實機診斷「presence 偶爾卡在持續刷新、不轉白畫面」
時發現，同一台裝置在 47 kΩ 下全暗實測 channel 1（GPIO5）已經長時間貼在
`saturated`（raw ≤10）、channel 2（GPIO7）也只剩 15–27，離低端飽和門檻幾乎
沒有餘裕——跟 2026-08-24 量到的 777–781 差了兩個數量級。兩次量測的差異
最可能來自 LDR 批次差異或環境「全暗」程度不同（例如百葉窗、遮光程度），
不代表 47 kΩ 這個數字本身寫錯；重點是**同一個 R_fix 在不同 LDR／環境下
不保證有相同餘裕，必須用實機當下量到的數字校正，不能照搬文件裡的歷史值**。

換成 100 kΩ 並重新校正 threshold（兩通道皆設 2000）後，2026-08-27 實測
（詳見 [VALIDATION.md](VALIDATION.md) 對應段落）：

| 條件 | GPIO5 raw | GPIO7 raw |
| --- | --- | --- |
| 室內光 | 4040 | 3827 |
| 手遮 | 3540 | 2736 |
| 全暗（關燈後靜置約 2 分鐘） | 91 | 105 |
| 直射光 | `saturated`（≥4085） | `saturated`（≥4085） |

全暗讀值離低端飽和門檻（≤10）有 80+ counts 餘裕，比 47 kΩ 那次量到的
狀態好得多，但代價是室內光已經逼近高端飽和門檻（4085）只剩不到 50
counts，且直射光下**兩顆都會飽和**（47 kΩ 時只有一顆會）。這是同一個
分壓電路無法迴避的取捨：`R_fix` 越大，全暗餘裕越多、但亮處餘裕越少，
反之亦然。目前刻意偏向保留全暗端的餘裕，理由見下方「為什麼優先保暗端」。

韌體把 raw ≤ 10 或 ≥ 4085 判為 `low_clipped`／`high_clipped`；
[ADR-0020](../adr/0020-light-clip-is-diagnostic-not-presence-gate.md) 之後
這兩個狀態仍會正常參與離席判定（clip 只是回報「貼到 ADC 極限」的診斷資訊），
但貼著極限時已經失去解析度——ADC 再往那個方向的光照變化都讀不出差異，讀值
本身也更容易受雜訊影響在極限附近抖動。所以你在意的整個光照範圍最好還是落在
raw 11–4084 之間；實際校正時若讀值頂到界線就換值：

- 正常室內光就頂到 4085 → `R_fix` 太大，換小一點
- 全暗時掉到 10 以下 → `R_fix` 太小，換大一點

另外，LDR 關燈後暗電阻是緩慢爬升的（「dark recovery」），關燈當下量到的
raw 不是穩態值，會在之後 1–2 分鐘內持續下降；校正「全暗」這一列時，
等讀值不再明顯變動再記錄，不要用剛關燈那幾秒的數字。

校正流程：WebUI「環境與在場」頁同時顯示兩顆的即時 raw 與各自的 threshold，
在正常室內／手遮／全暗／直射四種條件下讀值後再決定兩組 threshold。兩顆位置
不同就會看到不同的光，**不要共用同一個閾值**。

#### `R_fix` 選擇計算方法

分壓電路的輸出電壓（進而 ADC raw）由 `R_fix` 與 LDR 電阻 `R_LDR` 的比例
決定：

```
raw ≈ 4095 × R_fix / (R_fix + R_LDR)
```

LDR 在上、`R_fix` 在下（本文件「光敏電阻分壓接法」一節的接法），所以
`R_LDR` 越小（越亮）raw 越高，越大（越暗）raw 越低。選 `R_fix` 的目的
是讓你在意的整個光照範圍（部署環境實際會出現的「最暗」到「最亮」）都落在
raw 11–4084 之間，不要卡進兩端的飽和保護。

步驟：

1. **量測兩個邊界條件下的 `R_LDR`**：用三用電表直接量 LDR 兩端電阻，
   分別在部署環境最暗（例如關燈、拉上窗簾）與最亮（例如直射光）時量一次。
   沒有電表也可以先接一個已知的 `R_fix`（例如 10 kΩ）量出 raw，
   反推 `R_LDR = R_fix × (4095 − raw) / raw`。
2. **用幾何平均估算起始值**：`R_fix ≈ √(R_暗 × R_亮)`。幾何平均而非算術
   平均，是因為 raw 對 `R_LDR`是非線性（雙曲線）反應，幾何平均能讓兩端
   離各自的飽和門檻在對數尺度上大致對稱，而不是算術尺度上對稱。
3. **兩端餘裕原則上同等重要，暗端只是歷史上曾經代價更高**：在
   [ADR-0020](../adr/0020-light-clip-is-diagnostic-not-presence-gate.md)
   之前，全暗端貼著飽和門檻曾經會讓 presence 塌回 `unknown`、清空累積中的
   離席倒數（`update_presence()` 舊行為）；ADR-0020 之後 `low_clipped`／
   `high_clipped` 都正常參與判定，這個風險不對稱已經在判定層修掉。留在
   這裡的理由改為單純的解析度取捨：兩端都貼著極限時該方向的光照變化都讀
   不出差異，沒有哪一端天生更該犧牲，起始值算出來後照公式取幾何平均即可，
   不必再刻意往暗端偏。
4. **實機迭代校正，公式只是起點**：LDR 就算同型號也有批次差異，加上
   實際擺放位置（外殼遮光、感測器角度）會讓同一顆 LDR 表現得完全不同，
   公式算出來的值幾乎不會一次就對。流程是換上候選電阻 → 在 WebUI
   「環境與在場」頁的即時 raw 顯示下走過室內光／手遮／全暗／直射光
   四種條件 → 依上面「頂到 4085 就減小、掉到 10 以下就加大」調整 →
   重複，直到兩端都有餘裕（本文件的 47 kΩ → 100 kΩ 就是一次這樣的
   迭代，且 2026-08-27 那次還發現同一個 `R_fix` 在不同時間點的餘裕
   並不穩定，所以校正後仍要照下方「已知限制」持續觀察）。

##### 為什麼歷史上優先保暗端

兩端沒辦法同時留最大餘裕時，本專案曾經選擇犧牲亮端、保住暗端，原因（截至
2026-08-27，ADR-0020 之前）：

- **AND 語意本身就是為了讓誤判離席變難**（ADR-0018：「誤判離席（使用者
  在場卻白屏）比漏判離席（該睡沒睡）代價高得多」）。當時暗端貼著飽和
  門檻會讓 presence 塌回 `unknown`，等於用電路設計把 ADR 已經做的取捨又
  賠回去。
- 亮端飽和的實際影響很小：室內光與手遮這兩個「裝置多數時間會遇到」的
  條件都還在飽和門檻以內（見上表），只有「直射光」這種罕見邊界情境才會
  兩顆一起飽和，而且那種情境本來就已經確定是「亮」。

[ADR-0020](../adr/0020-light-clip-is-diagnostic-not-presence-gate.md)
（2026-08-29）之後這個偏好**不再是必要條件**：`low_clipped` 不會再讓
presence 塌回 `unknown`，兩顆同時貼著暗端一樣正確判斷為「暗」。現行
100 kΩ 保留下來是因為它同時也提供不錯的亮端餘裕（見上表），不是因為暗端
還有特殊風險——之後若要重新調整 `R_fix`，兩端可以用相同權重考慮，不必再
刻意偏暗。

判定規則：**每一顆已啟用且 decision-capable（`online`／`low_clipped`／
`high_clipped`）的通道都判為暗才算暗**——等價於「任一顆看到光就喚醒」
（ADR-0018）。`online` 通道用 raw 與自己的 threshold 比較；`low_clipped`
一律判為暗、`high_clipped` 一律判為亮，不經過 threshold 比較（threshold
是 0–4095 的可調欄位，直接拿去跟貼著極限的 raw 比較不保證方向正確，見
ADR-0020）。只有未啟用、未偵測到或讀取錯誤的通道會被忽略，不影響另一顆
（ADR-0020）。

### 為什麼是這些腳位

ESP32-S3-N16R8 上有一批 GPIO 不可自由使用，腳位是在扣除它們之後選定的：

| GPIO | 佔用原因 |
| --- | --- |
| GPIO33–37 | octal PSRAM |
| GPIO19–20 | native USB |
| GPIO0、GPIO3、GPIO45、GPIO46 | strapping pins |
| GPIO4 | 已分配給面板 BUSY，**不得再作為 light-sensor ADC** |
| GPIO10–14 | 面板 SPI2（CS／DIN／CLK／DC／RST） |
| ADC2 全部通道 | Wi-Fi 啟用時由 Wi-Fi driver 佔用，讀取回 `ESP_ERR_TIMEOUT` |

GPIO0、3、19、20、26–37、43–46 不分配給上述周邊。改接線前先讀 ADR-0003 的
限制，否則可能與 PSRAM 或開機模式衝突。

## 與程式碼的對應

腳位常數定義在
[`components/pf_display/include/pf_display/epd7in3e.hpp`](../../components/pf_display/include/pf_display/epd7in3e.hpp)
（`kPanelMosiGpio` 等），感測器腳位在
[`components/pf_sensors/sensor_task_esp_idf.cpp`](../../components/pf_sensors/sensor_task_esp_idf.cpp)
（`kDhtPin`、`kLightAdcChannels`）。兩個光敏通道的合併規則在
[`components/pf_sensors/include/pf_sensors/light_sensor.hpp`](../../components/pf_sensors/include/pf_sensors/light_sensor.hpp)
的 `combine_light_channels()`，有 host test 覆蓋。

面板腳位另有 host test 斷言（`test/test_epd7in3e_driver/`），改動腳位常數會
讓 `pio test -e native` 失敗——這是刻意的，避免腳位在無人察覺下被改掉。

## 已知限制

- **感測器已於 2026-08-23 完成實機驗證**：DHT22 bit-bang 時序與雙通道光敏
  ADC 校正無法用 host test 覆蓋，已改以實機證據閉環（ADR-0006、ADR-0018）。
  目前狀態仍以 [VALIDATION.md](VALIDATION.md) 為準。
- 光敏分壓的 `R_fix` 已於 2026-08-27 由 47 kΩ 換成 **100 kΩ**：47 kΩ 在
  2026-08-24 校正當時全暗實測 777–781、餘裕充足，但同一台裝置在
  2026-08-27 診斷「presence 偶爾卡在持續刷新、不轉白畫面」時，同樣 47 kΩ
  下全暗實測已經跌到 channel 1 常態 `saturated`、channel 2 只剩 15–27——
  兩顆同時偶爾飽和會讓 `update_presence()` 塌回 `unknown`，180 秒離席
  倒數整個歸零，這正是持續刷新不轉白畫面的成因。100 kΩ 實測全暗回升到
  91–105、兩端仍在飽和門檻內，見上方「光敏電阻分壓接法」一節的實測表與
  「`R_fix` 選擇計算方法」小節。**同一個 `R_fix` 數值在不同時間點測到的
  餘裕並不保證穩定**（原因未確認，推測與 LDR 批次或環境全暗程度有關），
  之後若又出現離席轉換異常，先用 WebUI 即時 raw 確認是否又貼上飽和門檻，
  而不是直接假設是判定邏輯的問題。**這次事件的根因已於 2026-08-29 在判定層
  修掉**（[ADR-0020](../adr/0020-light-clip-is-diagnostic-not-presence-gate.md)）：
  `low_clipped`／`high_clipped` 不再讓 presence 塌回 `unknown`，兩顆同時貼著
  暗端會正確判斷為「暗」而非清空離席倒數。上面這段歷史記錄與 `R_fix` 數值
  本身仍然有效——貼著極限依舊代表解析度變差，仍值得校正避免——但「貼著暗端
  會讓裝置卡在持續刷新」這個特定症狀不會再重演。
- **供電方案尚未設計**：目前直接接線。面板每次刷新後會 sleep，但主控
  未做 deep sleep，因此目前的功耗特性不適合電池運行。外殼已有可列印的
  CAD，但尚未定義列印材料與參數。

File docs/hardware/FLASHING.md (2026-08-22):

# ESP32-S3 燒錄操作

本文件記錄 YD-ESP32-S3／ESP32-S3-N16R8 雙 USB-C 開發板在 Windows 11
上的已驗證燒錄方式。COM 編號會在重新插拔或切換 ROM／app 後改變；實際 port
必須每次重新辨識，不得永久寫入設定。

## 日常開發：單一命令

目前 PaperFrame app 正常執行且 native USB 沒有被 monitor 佔用時，只需：

```powershell
.\.venv\Scripts\pio.exe run -e paperframe-s3 -t upload
```

不需指定 COM、不需按 BOOT/RST，也不需將 GPIO0/GPIO46 接地。專案設定會：

1. 依 board manifest 的 Espressif native USB hardware ID 自動選擇 ESP32-S3 native USB，
   不會選到板載 CH343 或其他 USB serial device；
2. 以 esptool `usb_reset` 讓正在執行的 app 進入 ROM download mode；
3. 讀取 `otadata`，依 ESP-IDF bootloader 的 `ota_seq` 規則選出目前啟動的
   `ota_N`，只擦寫該 app image；不再假設固定 offset `0x10000`；
4. 保留 bootloader、partition table、OTA metadata、NVS、reserved 的
   `webfs` 與 `imagefs`，完成 hash 驗證後 hard reset。

成功輸出應包含 `Auto-detected: COM...`、`USB mode: USB-Serial/JTAG`、
`Hash of data verified.` 與 `Hard resetting via RTS pin...`。若目前是空白板、
RGB demo、native USB 被停用，或 app 已損壞到無法接受 `usb_reset`，才改用
下方「首次或復原時進入 ROM」流程。

這個 app-only 開發流程會更新目前啟動中的 slot，讓重置後直接執行剛編譯的
韌體；正式 OTA 更新仍須由 OTA contract 寫入非執行中的 slot，不能把這個
開發 uploader 當成正式 OTA 實作。

`data/web/*`（前端）在 build 時 gzip 後編入 app image
（[ADR-0016](../adr/0016-embed-webui-assets-in-firmware.md)），所以上面這一個
命令就是完整部署：改前端不需要任何額外的燒錄步驟，每次 build 前都會自動
重新產生嵌入資產。

**絕對不要用 `pio run -t uploadfs`（任何 env）**：這個 partition table
有兩個 `spiffs` subtype 分割區（`webfs`、`imagefs`），PlatformIO 內建
`uploadfs` 的分割區選取邏輯（`fetch_fs_size()`，逐筆覆寫、取 CSV 裡最後
一個符合的分割區）會選到排序在後面的 `imagefs`（`0x630000`），但內容
來源固定是 `data/web/*`——等於把 WebUI 檔案寫進使用者的圖片儲存區。
2026-08-01 已實測確認並清空受污染的 `imagefs`，詳見
`docs/hardware/VALIDATION.md` 對應日期記錄。WebUI 改為編入韌體之後，
這個指令**更沒有任何正當用途**：跑它只會毀掉 `imagefs`。

## 新裝置首次燒錄（含 bootloader）

**日常命令不會寫 bootloader。** `tools/platformio_native_usb_upload.py` 刻意
把 PlatformIO 原本附加在 flash-size 之後的 bootloader、partition table 與初始
OTA metadata 全部移除，只留下 app image 的 esptool flags——這正是 active-slot
上傳的前提。因此：

- 全新或已抹除的板子**只跑 `pio run -t upload` 會燒不起來**：flash 裡沒有
  bootloader，晶片無從啟動。
- 既有裝置**無論更新幾次韌體、做過幾次 OTA，bootloader 都不會改變**。它只來自
  這一節的首次燒錄。

新板子（或 bootloader 需要更新時）用下列流程。先建置，再一次寫入三個區段：

```powershell
.\.venv\Scripts\pio.exe run -e paperframe-s3
if ($LASTEXITCODE -ne 0) {
  throw 'Firmware build failed; do not continue to write-flash.'
}

.\.venv\Scripts\python.exe -m esptool --chip esp32s3 --port <COM> `
  --before usb-reset --after hard-reset write-flash `
  0x0 .pio\build\paperframe-s3\bootloader.bin `
  0x8000 .pio\build\paperframe-s3\partitions.bin `
  0x10000 .pio\build\paperframe-s3\firmware.bin
```

三個區段都應回報 `Hash of data verified.`。這個範圍**刻意不含**
`nvs`（`0x9000`）與 `imagefs`（`0x630000`）：既有裝置照這個流程更新 bootloader
不會遺失 Wi-Fi 憑證、管理密碼、天氣設定或使用者圖片。

全新板子還需要兩件事：

1. **重設 OTA metadata**，讓 bootloader 從 `ota_0` 啟動（既有裝置若 otadata
   指向一個已被覆寫的 slot 也需要）：
   ```powershell
   .\.venv\Scripts\python.exe -m esptool --chip esp32s3 --port <COM> `
     --before usb-reset --after hard-reset erase-region 0xd000 0x2000
   ```
2. **factory imagefs image**（只有新機或明確要清空圖片時才做，見本文件的
   imagefs 章節）。

之後的日常更新就回到開頭那一個 PlatformIO 命令。

## bootloader 是否具備回滾保護

`CONFIG_BOOTLOADER_APP_ROLLBACK_ENABLE` 在 2026-08-01 才加入
`sdkconfig.defaults`。**回滾邏輯位於 bootloader，而 OTA 與日常 upload 都不會更新
bootloader**，所以在那之前燒錄過 bootloader 的裝置沒有回滾保護：OTA 裝上一個會在
`esp_ota_mark_app_valid_cancel_rollback()` 之前崩潰的韌體時，它會無限 crash-loop
而不是退回舊版，只能靠 esptool 救援。2026-08-20 已在實機上重現這個情形，並確認
更新 bootloader 後回滾恢復正常（見
[VALIDATION.md](VALIDATION.md) 同日的 rollback fault injection 段落）。

要判斷手上的裝置是否受保護，把 flash 開頭讀回來與本機建置的 bootloader 比對：

```powershell
.\.venv\Scripts\pio.exe run -e paperframe-s3
.\.venv\Scripts\python.exe -m esptool --chip esp32s3 --port <COM> `
  --before usb-reset --after no-reset read-flash 0x0 0x8000 device_bootloader.bin

.\.venv\Scripts\python.exe -c @'
import hashlib, pathlib
local = pathlib.Path(r'.pio/build/paperframe-s3/bootloader.bin').read_bytes()
device = pathlib.Path('device_bootloader.bin').read_bytes()[:len(local)]
print('match:', device == local)
print('local :', hashlib.sha256(local).hexdigest()[:32])
print('device:', hashlib.sha256(device).hexdigest()[:32])
'@
```

讀回的是整個 `0x8000` 區塊，因此只比對前 `len(bootloader.bin)` bytes。
`match: False` 代表 bootloader 與目前程式碼不同步——若該裝置需要回滾保護，就依
上一節重寫 `0x0`。注意這個比對只回答「是否與目前建置相同」，不單獨回答「是否
啟用回滾」；兩者不同步時最省事的處理就是直接更新。

## USB 介面

| 介面 | Windows hardware ID | 用途 |
| --- | --- | --- |
| ESP32-S3 native USB Serial/JTAG | Espressif native USB hardware ID | 已驗證可進 ROM、執行 `esptool` 與監看 app console |
| 板載 USB-to-UART adapter | adapter hardware ID（已省略） | 本次在 ROM download mode 沒有收到資料，不作為標準燒錄路徑 |

每次操作前先重新辨識：

```powershell
.\.venv\Scripts\pio.exe device list
$nativePort = '<NATIVE_USB_PORT>' # 以當次 hardware ID 的實際 COM 取代
$flashRunId = Get-Date -Format 'yyyyMMdd-HHmmss'
```

以下命令應在同一個 PowerShell session 依序執行。任何命令丟出錯誤時立即
停止，不得跳過 guard 繼續燒錄。

## 首次或復原時進入 ROM

若目前 app 無法由 USB 自動重置進 ROM：

1. 使用可傳資料的 USB 線連接 ESP32-S3 native USB port。
2. 將 `GPIO0` 固定接到 `GND`。
3. 將 `GPIO46` 固定接到 `GND`。
4. 短按 `RST`；燒錄完成前保留兩條接地線。
5. 使用 native USB COM 驗證 ROM，而不是 CH343 COM。

正確 ROM log 包含：

```text
boot:0x0 (DOWNLOAD(USB/UART0))
waiting for download
```

進入 ROM 後，以唯讀命令確認連線：

```powershell
$otaData = Join-Path $env:TEMP "paperframe-otadata-$flashRunId.bin"
if (Test-Path -LiteralPath $otaData) {
  throw "Refusing existing OTA metadata file: $otaData"
}

.\.venv\Scripts\python.exe -m esptool `
  --chip esp32s3 `
  --port $nativePort `
  --before no-reset `
  --after no-reset `
  read-flash 0xd000 0x2000 $otaData

if ($LASTEXITCODE -ne 0) {
  throw 'Reading OTA metadata failed; do not continue to write-flash.'
}
if ((Get-Item -LiteralPath $otaData -ErrorAction Stop).Length -ne 0x2000) {
  throw 'OTA metadata length is not 0x2000; do not continue.'
}
```

若 native USB 回報 `Write timeout`，先確認沒有 monitor 占用同一 COM，並從
ROM log 確認晶片確實是 download mode。不要改用 `erase-flash`、eFuse 或
反覆嘗試 CH343。

## 已啟用 native USB 的 app

PaperFrame test firmware 保留 USB Serial/JTAG；app 正常執行時，以下命令已
驗證可免接 GPIO，自動重置進 ROM：

```powershell
$autoOtaData = Join-Path $env:TEMP "paperframe-otadata-auto-$flashRunId.bin"
if (Test-Path -LiteralPath $autoOtaData) {
  throw "Refusing existing OTA metadata file: $autoOtaData"
}

.\.venv\Scripts\python.exe -m esptool `
  --chip esp32s3 `
  --port $nativePort `
  --before usb-reset `
  --after no-reset `
  read-flash 0xd000 0x2000 $autoOtaData

if ($LASTEXITCODE -ne 0) {
  throw 'USB auto-reset or OTA metadata read failed.'
}
if ((Get-Item -LiteralPath $autoOtaData -ErrorAction Stop).Length -ne 0x2000) {
  throw 'OTA metadata length is not 0x2000; do not continue.'
}
```

若失敗，回到前一節同時拉低 `GPIO0`、`GPIO46` 的流程。

## App-only 開發燒錄

日常操作使用本文件開頭的 PlatformIO 單一命令。下列低階流程保留給首次
bring-up、備份／還原與 uploader 診斷。

先建立正式韌體：

```powershell
.\.venv\Scripts\pio.exe run -e paperframe-s3
if ($LASTEXITCODE -ne 0) {
  throw 'Firmware build failed; do not continue to write-flash.'
}
```

目前開發 partition table 的 `ota_0` 位於 `0x10000`、大小 `0x280000`，
`ota_1` 位於 `0x290000`。日常命令會自動讀取 OTA metadata；以下低階範例
仍以 `ota_0` 為例，只有在讀取結果確認 `ota_0` 是 active app 時才可照做。
若 active slot 是 `ota_1`，必須把範例中的 `ota_0`／`0x10000` 換成
`ota_1`／`0x290000`：

```powershell
$backup = Join-Path $env:TEMP "paperframe-ota0-backup-$flashRunId.bin"
if (Test-Path -LiteralPath $backup) {
  throw "Refusing existing backup file: $backup"
}

.\.venv\Scripts\python.exe -m esptool `
  --chip esp32s3 `
  --port $nativePort `
  --before no-reset `
  --after no-reset `
  read-flash 0x10000 0x280000 $backup

if ($LASTEXITCODE -ne 0) {
  throw 'Backing up ota_0 failed; do not continue to write-flash.'
}
$backupFile = Get-Item -LiteralPath $backup -ErrorAction Stop
if ($backupFile.Length -ne 0x280000) {
  throw 'ota_0 backup length is not 0x280000; do not continue.'
}
$backupSha256 = (Get-FileHash -Algorithm SHA256 -LiteralPath $backup).Hash
Write-Host "Backup: $backup"
Write-Host "SHA-256: $backupSha256"

$firmware = Get-Item -LiteralPath `
  '.pio\build\paperframe-s3\firmware.bin' -ErrorAction Stop

.\.venv\Scripts\python.exe -m esptool `
  --chip esp32s3 `
  --port $nativePort `
  --baud 460800 `
  --before no-reset `
  --after no-reset `
  write-flash `
  --flash-mode dio `
  --flash-freq 80m `
  --flash-size 16MB `
  0x10000 $firmware.FullName

if ($LASTEXITCODE -ne 0) {
  throw 'Writing the app failed; keep the backup and stop.'
}
```

`esptool` 必須回報 `Hash of data verified.`。以 manual straps 進 ROM
時，app-only 操作完成後要拔除 GPIO0/GPIO46 接地線並短按 `RST`；若使用
`--before usb-reset`，則依命令的 `--after` 行為 reset。

若 OTA metadata 無法判定 active slot，停止並重新讀取／診斷；不得把
`0x10000` 當作永久固定的 OTA 更新位置。正式 OTA 更新應走 OTA contract，
不得直接覆寫 running slot。

一般 app-only 燒錄不得改寫：

- `0xd000` 的 OTA metadata；
- `0x510000` 的 `webfs`（reserved，見 ADR-0016）；
- `0x630000` 的 `imagefs`；
- NVS、partition table 或 eFuse。

## WebUI 更新

WebUI 沒有獨立的燒錄流程：`data/web/` 的內容在 build 時 gzip 後編入 app
image，因此一般 app upload 或一次 OTA 就會同時更新韌體與前端，見
[ADR-0016](../adr/0016-embed-webui-assets-in-firmware.md)。

`0x510000` 的 `webfs` 分割區仍保留在 partition table 中（ADR-0004 凍結的
layout 未變），但已不掛載、不寫入。既有裝置上的殘留內容**刻意不清除**：
bootloader 回滾到舊版韌體時，舊版仍需要那份 WebUI 才能運作。

## Embedded e-Paper pattern test

建立六色直條測試韌體：

```powershell
.\.venv\Scripts\pio.exe test `
  --project-conf platformio-embedded.ini `
  -e paperframe-s3-embedded-test `
  -f test_epd7in3e_driver `
  --without-uploading `
  --without-testing

if ($LASTEXITCODE -ne 0) {
  throw 'Embedded pattern-test build failed; do not continue.'
}
```

依前節備份 `ota_0`，再把以下檔案寫到 `0x10000`：

```powershell
$currentBackupFile = Get-Item -LiteralPath $backup -ErrorAction Stop
if ($currentBackupFile.Length -ne 0x280000) {
  throw 'ota_0 backup length changed; do not write the test app.'
}
if ((Get-FileHash -Algorithm SHA256 -LiteralPath $backup).Hash -ne
    $backupSha256) {
  throw 'ota_0 backup hash changed; do not write the test app.'
}
$testFirmware = Get-Item -LiteralPath `
  '.pio\build\paperframe-s3-embedded-test\firmware.bin' -ErrorAction Stop

.\.venv\Scripts\python.exe -m esptool `
  --chip esp32s3 `
  --port $nativePort `
  --baud 460800 `
  --before no-reset `
  --after no-reset `
  write-flash `
  --flash-mode dio `
  --flash-freq 80m `
  --flash-size 16MB `
  0x10000 $testFirmware.FullName

if ($LASTEXITCODE -ne 0) {
  throw 'Writing the pattern-test app failed; keep the backup and stop.'
}
```

寫入完成後：

1. 拔除 `GPIO0`、`GPIO46` 的接地線。
2. 短按 `RST`。
3. 確認面板依序顯示垂直黑、黃、紅、藍、綠、白色帶。
4. 測試後重新進 ROM；若用 straps 進入，確認 ROM sync 後先拔除兩條接地
   線，晶片會留在 ROM，restore 完成時的 hard reset 才能啟動 app。
5. 把備份寫回 `0x10000`：

```powershell
$restoreBackupFile = Get-Item -LiteralPath $backup -ErrorAction Stop
if ($restoreBackupFile.Length -ne 0x280000) {
  throw 'ota_0 backup length changed; refusing restore.'
}
if ((Get-FileHash -Algorithm SHA256 -LiteralPath $backup).Hash -ne
    $backupSha256) {
  throw 'ota_0 backup hash changed; refusing restore.'
}

.\.venv\Scripts\python.exe -m esptool `
  --chip esp32s3 `
  --port $nativePort `
  --baud 460800 `
  --before no-reset `
  --after hard-reset `
  write-flash `
  --flash-mode dio `
  --flash-freq 80m `
  --flash-size 16MB `
  0x10000 $backup

if ($LASTEXITCODE -ne 0) {
  throw 'Restoring ota_0 failed; keep the backup and stop.'
}
```

恢復命令也必須回報 `Hash of data verified.`。確認一般 app 已重新枚舉後，
才可刪除 backup；電子紙會保留最後畫面，
恢復一般 app 不會立即清除已顯示的六色色帶。

## 實測補充（2026-08-23，第一次走完整新板流程）

- **新板不一定聽 esptool 的自動重置**。出廠韌體若用 USB-OTG（TinyUSB CDC，
  hardware ID `303A:4001`）而非內建 USB Serial/JTAG（`303A:1001`），
  `--before usb-reset`、`default-reset`、`no-reset` 三種都會失敗並回報
  `No serial data received`。這不是線材或 port 選錯，直接改用下方「首次或
  復原時進入 ROM」的 BOOT+RST 手動流程即可。進 ROM 後 port 會重新枚舉成
  `303A:1001`，**COM 編號會變**，要重新辨識。
- **燒完記得把 GPIO0 的接地線拔掉**。留著的話後續 hard reset 仍會落回
  `boot:0x21 (DOWNLOAD(USB/UART0))`，開機 log 只有 `waiting for download`，
  看起來像燒錄失敗——實際上四個區段可能早就 `Hash of data verified.` 了。
  正常啟動應為 `boot:0x29 (SPI_FAST_FLASH_BOOT)`。
- 已在 ROM 裡時，後續 esptool 命令用 `--before no-reset` 即可，不需要再
  觸發一次 usb-reset。
- 新板**必須**燒 factory imagefs image：`filesystem_manager.cpp` 的
  littlefs 設定是 `format_if_mount_failed = false`，空白 flash 不會被自動
  格式化，不燒的話 `imagefs` 會掛載失敗。

完整的一次實測紀錄（含晶片驗證、開機 log 與各區段 hash 結果）見
[VALIDATION.md](VALIDATION.md) 的 2026-08-23 段落。

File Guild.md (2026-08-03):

# ESP32-S3 電子紙圖片輪播專案需求草案 v0.1

## 一、專案名稱建議

| 顯示名稱 | Repository 名稱 | 定位 |
| --- | --- | --- |
| **PaperFrame** | `esp32-paper-frame` | 最直觀，適合延續 `esp32-hydracup` 命名方式 |
| SpectraFrame | `esp32-spectra-frame`  | 呼應 E Ink Spectra 6 面板 |
| PaperCarousel | `esp32-paper-carousel` | 強調圖片輪播 |
| InkFrame S3 | `esp32-inkframe-s3` | 強調 ESP32-S3 與電子紙 |
| PaperGallery | `esp32-paper-gallery`  | 強調圖片庫管理 |
| Home Paper Frame | `epaper-home-frame` | 與 `epaper-home-display` 系列感較強  |
**建議採用：**
* 產品名稱：**PaperFrame**
* Repository：**`esp32-paper-frame`**
* 裝置識別字串：`paperframe-s3`
* 預設 mDNS：`paperframe.local`
* AP SSID：`PaperFrame-Setup-XXXX`

名稱簡單、用途明確，也不會把專案綁死在特定尺寸或特定面板世代。

---

# 二、三個參考專案的定位與可移植內容

## 2.1 `epaper-home-display`

這是功能最完整的顯示端參考，包含：

* OpenWeatherMap 即時天氣與預報。
* 電子紙 Dashboard renderer。
* AP Mode 引導畫面。
* 圖片上傳、旋轉、翻轉、裁切、Contain、Stretch、抖動預覽。
* 圖片庫與順序／隨機輪播。
* WebUI 登入、session、CSRF、深淺色主題。
* 系統狀態、事件日誌與環境資料分析。
* 將硬體、業務邏輯、服務、狀態與 WebUI 分層。

圖片處理已定義一致的轉換順序：

1. 水平鏡像。
2. 垂直鏡像。
3. 順時針旋轉。
4. 裁切或 Fit。
5. 縮放。
6. 電子紙色盤量化與 Floyd–Steinberg dithering。
**移植方式：**

不直接移植 FastAPI、Pillow、SQLite 等 Raspberry Pi 元件，而是移植：

* 頁面資訊架構。
* WebUI 視覺設計。
* 圖片操作語意。
* 顯示排程與狀態模型。
* 圖片輪播規則。
* 感測器防抖邏輯。

---

## 2.2 `pico-paper-clock`

這個專案主要提供資源受限裝置的實作參考：

* 圖片串流上傳，不把整張圖片載入 RAM。
* PPC1 圖片格式與固定大小 row buffer。
* 圖片 `.part`、`.bak` 交易式寫入及開機復原。
* 圖片庫、事件圖片與一次性面板預覽。
* 多 Wi-Fi profile。
* 設定檔 schema version 與遷移。
* 光敏電阻的離席／返回防抖。
* 離席後清屏並讓面板進入睡眠。
* 溫溼度感測器讀取失敗時保留最後有效資料，而不是寫入假資料。

圖片 API 採用先寫入暫存檔、驗證大小與解碼結果，再原子替換正式檔案；中途斷電可於下次開機復原。

光敏電阻則使用可調整的離席與返回時間，只有條件持續成立才改變穩定狀態。

**移植方式：**
* 圖片串流與交易式寫入。
* 圖片檔案 header、CRC、版本管理。
* 感測器缺席與錯誤處理。
* 狀態驅動的清屏與睡眠。
* 儲存空間受限時的圖片管理策略。

---

## 2.3 `esp32-hydracup`

這是新專案最適合採用的韌體架構基底：

* PlatformIO＋native ESP-IDF。
* FreeRTOS task 分工。
* NVS 儲存設定。
* LittleFS 儲存 WebUI 與使用者資料。
* AP Mode Config Portal。
* Wi-Fi 掃描 API。
* Normal Mode DashboardServer。
* 單一 server-side session、CSRF 與密碼雜湊。
* HTTP handler 不直接操作即時硬體，而是透過 snapshot 與 command queue 溝通。
* 硬體或周邊初始化失敗時採降級運作，不中止整個裝置。

HydraCup 的 AP Mode 已具備掃描附近 Wi-Fi、手動輸入隱藏 SSID、填寫密碼、儲存並重新啟動的完整流程。

**結論：**

新專案應以 **HydraCup 的 ESP-IDF 架構為主體**，加入：

* `epaper-home-display` 的 renderer、圖片輪播與 WebUI 功能。
* `pico-paper-clock` 的圖片交易、感測器缺席處理與低記憶體設計。

---

# 三、硬體限制與核心設計決策

指定的 7.3 吋 e-Paper HAT (E) 為 800×480、SPI、E6 Full Color 面板，官方標示完整刷新約需 25 秒。官方也建議刷新間隔至少 180 秒，刷新後應讓面板進入 sleep 或切斷電源。

因此本專案採取以下原則：

1. **不設計分鐘級時鐘更新。**
2. 每次圖片輪播都是完整刷新。
3. 預設輪播間隔 30 分鐘。
4. 最短允許間隔設定為 10 分鐘，最長為 24 小時。
5. 天氣資料可以每 10 分鐘更新快取，但面板只在下一次圖片刷新時呈現。
6. 每次刷新後立即呼叫面板 sleep。
7. 顯示工作開始時間應提前約 25～30 秒，使完成時間接近排定的整點邊界。

官方 `epd7in3e` driver 以 4-bit 表示一個像素，兩個像素打包成一個 byte；完整 800×480 framebuffer 為 192,000 bytes。現行 driver 的有效色槽為黑、白、黃、紅、藍、綠，Orange slot 目前被註解並映射為黑色。

因此圖片格式必須包含 `palette_version`，MVP 先採官方 driver 實際支援的六個有效色彩，避免 WebUI 預覽與實機顯示不一致。

ESP32-S3 的圖片 framebuffer、縮圖解碼工作區與 WebUI 暫存資料應放入 PSRAM；DMA descriptor、task stack 與 flash 寫入期間必要的工作資料仍放在內部 RAM。ESP-IDF 文件指出 flash cache 關閉時 PSRAM 也不可存取，因此 imagefs 寫入、OTA 與顯示 framebuffer 操作必須透過 storage/display mutex 錯開執行。

開發板版本可能影響可用 GPIO。官方資料指出使用 Octal flash／PSRAM 的模組會占用 GPIO35、GPIO36、GPIO37，不應將這三個腳位配置給電子紙或感測器。

---

# 四、完整功能需求

## 4.1 開機與運作模式

裝置狀態至少包含：

```text
BOOT
 ├─ SELF_TEST
 ├─ CONNECTING_WIFI
 │    ├─ NORMAL
 │    └─ PROVISIONING_AP
 ├─ OFFLINE_RETRY
 ├─ DISPLAY_UPDATING
 ├─ SENSOR_SLEEP
 └─ OTA_UPDATING
```

開機流程：

1. 初始化 NVS。
2. 掛載 `webfs` 與 `imagefs`。
3. 復原未完成的圖片或設定交易。
4. 檢查 Flash、PSRAM 與電子紙 driver。
5. 初始化可選感測器。
6. 載入圖片 catalog。
7. 嘗試連接最後成功的 Wi-Fi。
8. 成功則同步 SNTP、啟動 Normal Mode WebUI。
9. 失敗或未設定 Wi-Fi 則進入 AP Mode。
10. 個別感測器或面板初始化失敗不得造成 boot loop。

Wi-Fi 與 Internet 狀態必須分開：

* Wi-Fi 未連線：進入 AP Mode。
* Wi-Fi 已連線但 OpenWeatherMap 無法存取：保持 Normal Mode並使用最後有效天氣快取。
* DNS、API Key 或 OpenWeatherMap 錯誤不能觸發 AP Mode。

---

## 4.2 AP Mode 與 Wi-Fi 設定

### AP 顯示畫面

電子紙停止圖片輪播，顯示：

* 專案名稱與 AP Mode 標題。
* AP SSID。
* AP Password。
* 固定 IP：`192.168.4.1`。
* 操作步驟。
* Wi-Fi 連線 QR Code。
* WebUI URL 或入口 QR Code。
* 裝置識別碼後四碼。

AP 畫面只在內容改變時更新，不可每 30 秒刷新。

### AP WebUI

AP Mode 頁面包含：

* 掃描 Wi-Fi 按鈕。
* 掃描中狀態。
* SSID 下拉選單。
* RSSI／訊號強度。
* 安全性類型。
* 手動輸入 SSID，支援隱藏網路。
* Wi-Fi Password。
* 顯示／隱藏密碼。
* 儲存並重新啟動。
* 連線失敗原因與再次設定入口。

掃描結果應：

* 依 RSSI 排序。
* 合併重複 SSID。
* 保留目前已選取 SSID。
* 對空 SSID 與無法識別的項目做過濾。
* 不把密碼寫入 URL、log 或 HTTP response。

設定成功後：

1. 交易式寫入 Wi-Fi 憑證。
2. 回傳成功訊息。
3. 延遲約 1 秒重新啟動。
4. 重新嘗試 STA。
5. 失敗則再次進入 AP Mode。

首次尚未建立管理密碼時可直接設定 Wi-Fi；已完成初始設定後的 Recovery AP 必須先登入管理帳號。

---

## 4.3 Normal Mode 圖片顯示

### 橫向模式

* 邏輯解析度：800×480。
* 狀態列：800×40。
* 圖片區：800×440。
* 圖片區 packed payload：176,000 bytes。

### 直向模式

* 邏輯解析度：480×800。
* 狀態列：480×40。
* 圖片區：480×760。
* 圖片區 packed payload：182,400 bytes。
* 完成邏輯畫面後再旋轉成面板原生 800×480 資料。

### 狀態列

預設顯示：

* 日期及星期。
* OpenWeatherMap 天氣圖示。
* 室外即時溫度。
* 天氣資料過期或離線標記。
* 選用：室內溫度與溼度。
* 選用：上次更新時間。

「即時天氣」定義為最近成功取得並快取的資料，不代表面板每分鐘刷新。

### 輪播規則

* 預設間隔：30 分鐘。
* 最短間隔：10 分鐘；最長間隔：24 小時。
* 模式：順序、隨機。
* 新圖片加入後不得在尚未顯示一次前被自動跳過。
* 手動切換圖片後，該圖片至少顯示一個完整週期。
* 圖片遺失或損毀時自動從有效 playlist 排除。
* 圖片庫為空時顯示內建歡迎／裝置狀態頁。

顯示操作必須由單一 `DisplayTask` 管理；WebUI handler 只能提交 command，不可直接操作 SPI 或面板。

---

## 4.4 OpenWeatherMap 與時間

設定欄位：

* API Key。
* 緯度。
* 經度。
* 顯示地點名稱。
* 單位：攝氏／華氏。
* 語言。
* 天氣更新間隔。
* 時區，預設 `Asia/Taipei`。
* NTP server。

WebUI 必須提供：

* API Key 已設定狀態，不回傳原始值。
* 測試 API 按鈕。
* 測試結果、錯誤原因與取得時間。
* 目前天氣預覽。
* 最後成功更新時間。
* 快取是否過期。

錯誤處理：

* 指數退避重試。
* API Key 無效與一般網路失敗分開顯示。
* 失敗時保留最後有效資料。
* 沒有任何快取時顯示 `--°C` 與離線圖示。
* SNTP 未同步前不得產生錯誤日期；可暫時顯示「時間同步中」。

---

## 4.5 瀏覽器端圖片編輯器

圖片處理應優先完全放在使用者瀏覽器執行，ESP32 不負責處理大型原始照片。

技術方式：

* HTML Canvas。
* Web Worker 執行 dithering，避免主 UI 凍結。
* 所有 JavaScript、CSS、字型及圖示存於 `webfs`。
* 不依賴 CDN，AP Mode 離線時也能使用。

支援功能：

* 拖曳或選擇圖片。
* JPEG、PNG、WebP。
* 自動套用 EXIF orientation。
* 透明區域合成白色背景。
* 順時針旋轉 90°。
* 逆時針旋轉 90°。
* 水平鏡像。
* 垂直鏡像。
* 縮放。
* 拖曳位置。
* 復原。
* 重設。

Fit 模式：

| 模式 | 行為 |
| --- | --- |
| 填滿 Cover | 保持比例，裁掉超出區域  |
| 完整顯示 Contain | 保持比例，以白色補足空間 |
| 拉伸 Stretch | 忽略比例，直接填滿 |
| 手動裁切 Crop | 使用固定目標比例裁切框  |

Dithering 模式：

* Floyd–Steinberg，預設。
* Atkinson。

Crop 與 Cover 的處理後預覽可用滑鼠／觸控拖曳圖片調整裁切位置，並以裁切縮放
滑桿放大選擇目標；預設位置為置中、縮放為 100%。來源圖片最多 6,400 萬像素，
檔案大小仍限制為 32 MB。

預覽必須同時顯示：

* 原圖。
* 處理後圖片。
* 實際狀態列。
* 目前方向與輸出解析度。
* 預估儲存大小。

產生結果後由瀏覽器打包為面板資料，再上傳至裝置。不得上傳未限制大小的原始 RGB framebuffer。

---

## 4.6 圖片資料格式

建議建立專案專用格式，例如 `PFR1`：

```text
magic             4 bytes   "PFR1"
format_version    1 byte
palette_version   1 byte
orientation       1 byte
flags             1 byte
width             2 bytes
height            2 bytes
payload_length    4 bytes
crc32             4 bytes
payload           N bytes
```

必要驗證：

* Magic。
* 版本。
* Width／Height。
* Orientation。
* Palette version。
* Payload length。
* CRC32。
* 剩餘儲存空間。
* 檔名合法性。

圖片寫入流程：

```text
upload.part
  → 驗證 header
  → 串流計算 CRC
  → 驗證 payload
  → 原檔改名為 .bak
  → .part 改名為正式檔
  → 更新 catalog
  → 刪除 .bak
```

開機時必須復原殘留的 `.part` 與 `.bak`。

---

## 4.7 圖片庫

圖片庫頁面包含：

* 縮圖。
* 圖片名稱。
* 建立日期。
* Orientation。
* 圖片大小。
* 儲存空間占用。
* 是否在輪播清單。
* 是否為目前圖片。
* 圖片損毀狀態。

可執行操作：

* 設為目前圖片。
* 立即於下次 display command 顯示。
* 啟用／停用輪播。
* 重新命名。
* 刪除。
* 拖曳調整順序。
* 全選／批次刪除。
* 下載已處理檔案。
* 顯示 storage 使用量。

刪除目前圖片時：

1. 先從 catalog 移除。
2. 選擇下一張有效圖片。
3. 更新 runtime snapshot。
4. 最後刪除實體檔案。

如此即使刪檔失敗，也不會留下指向不存在圖片的 runtime state。

---

## 4.8 溫溼度感測器

溫溼度感測器先完成軟體介面，但預設為未啟用或未安裝。

建議介面：

```cpp
class EnvironmentSensor {
public:
    virtual SensorStatus probe() = 0;
    virtual bool read(EnvironmentReading& output) = 0;
};
```

初期 driver：

* `NullEnvironmentSensor`
* `DHT22EnvironmentSensor`

後續可以增加：

* SHT30／SHT31。
* BME280。
* 其他 I²C 感測器。

狀態模型：

| 狀態 | 說明 |
| --- | --- |
| `disabled` | WebUI 尚未啟用 |
| `probing` | 正在尋找或等待有效讀值 |
| `online` | 已取得有效資料 |
| `stale` | 有舊資料，但近期讀取失敗 |
| `not_detected` | 已啟用但尚未偵測到 |
| `error` | driver 或 GPIO 錯誤 |

未找到感測器時：

* 裝置正常開機。
* 圖片正常輪播。
* WebUI 顯示「未安裝／未偵測到」。
* API 回傳 `null`，不得回傳 `0`。
* 狀態列隱藏室內資料或顯示 `--`。
* 不建立假的環境歷史紀錄。
* 每隔一段時間低頻重新 probe。
* 保留最後一次有效值，但標記為 stale。

參考專案的 DHT22 實作會限制讀取頻率、驗證數值範圍，失敗時保留最後成功資料並延長重試間隔。

---

## 4.9 光敏電阻與在場機制

光敏電阻同樣採可選 driver：

```cpp
class LightSensor {
public:
    virtual SensorStatus probe() = 0;
    virtual bool readRaw(uint16_t& output) = 0;
};
```

狀態：

* `disabled`
* `online`
* `not_detected`
* `saturated`
* `error`

光敏電阻未安裝或未啟用時：

* `presence = UNKNOWN`。
* 不清除面板。
* 不暫停圖片輪播。
* 不把 ADC 浮動值視為離席。

啟用且正常時：

1. 定期讀取 ADC。
2. 套用 moving average 或 median filter。
3. 與可調整 threshold 比較。
4. 狀態持續達指定時間後才切換。

預設值建議：

* 離席持續時間：180 秒。
* 返回持續時間：30 秒。
* WebUI 可調整 threshold、離席時間與返回時間。

離席後：

* 只執行一次全白刷新。
* 面板進入 sleep。
* 暫停圖片輪播與天氣畫面刷新。
* 感測器、Wi-Fi 與 WebUI 繼續運作。

返回後：

* 立即喚醒並重新初始化面板。
* 使用目前應顯示的圖片與最新狀態資料完整重繪。
* 輪播計時重新開始。
* 不使用離席前殘留的刷新 deadline。

這與兩個電子紙參考專案的狀態驅動模式一致：必須根據目前穩定狀態收斂到清屏／睡眠，而不能只處理狀態切換瞬間。

WebUI 應提供即時 ADC 數值、threshold 標記及目前判定狀態，方便安裝後校正。

---

# 五、WebUI 資訊架構

## 5.1 頁面

### Dashboard

顯示：

* 裝置運作狀態。
* 目前圖片。
* 下次輪播時間。
* Wi-Fi、Internet、SNTP。
* 天氣快取狀態。
* 電子紙狀態。
* 溫溼度感測器狀態。
* 光敏電阻與在場狀態。
* Flash、PSRAM、imagefs 使用量。
* 韌體版本與 uptime。

### 圖片

分成兩個分頁：

* 圖片編輯與上傳。
* 圖片庫與輪播管理。

### 環境

即使尚未裝感測器也保留此頁面：

* 感測器安裝狀態。
* GPIO 與 driver 類型。
* 目前溫溼度。
* 今日 min／max／avg。
* 光線 ADC 與 threshold。
* 在場狀態。
* 後續可加入日／週／月趨勢圖。

### 設定

分類：

* 顯示器。
* 圖片輪播。
* 天氣。
* 時間與時區。
* Wi-Fi。
* 溫溼度感測器。
* 光敏電阻。
* 帳號與密碼。
* 系統與更新。

### 系統

* 系統事件。
* 最近刷新結果。
* BUSY timeout 次數。
* Wi-Fi 重連次數。
* Weather API 錯誤。
* 感測器錯誤。
* 下載診斷資料。
* 重新啟動。
* 進入 Recovery AP。
* OTA 更新。

---

## 5.2 統一視覺設計

延續三個專案既有風格：

* 米白網格背景。
* Teal、Coral、Mint 主色。
* 方角元件。
* 卡片硬陰影。
* Georgia／`Noto Serif TC` 標題。
* Consolas／monospace 數字與控制項。
* LIGHT／DARK 切換。
* 共用 localStorage key：`iot-ui-theme`。
* 1040px 主內容寬度。
* 行動裝置 responsive layout。

新專案應將這套樣式抽成：

```text
data/
├── style.css
├── ui.js
├── favicon.svg
├── login.html
├── index.html
├── images.html
├── environment.html
└── settings.html
```

不得在每個 HTML 內複製完整 CSS。

---

# 六、認證與安全需求

沿用 HydraCup 與兩個電子紙專案的模式：

* 固定帳號 `admin`。
* 首次使用建立至少 8 字元密碼。
* PBKDF2-HMAC-SHA256 或同等強度密碼雜湊。
* 單一 server-side session。
* 新登入取代舊 session。
* 閒置 30 分鐘失效。
* 最長 24 小時失效。
* `HttpOnly`。
* `SameSite=Strict`。
* 所有 POST、PUT、DELETE 需要 CSRF token。
* Secret 欄位只回傳 `*_set: true/false`。
* 不提供 CORS。
* `/api/v1/device` 與 health endpoint 可不登入。
* Recovery AP 已設定密碼時必須先登入。

WebUI 預設為區域網路 HTTP，因此頁面需註明只能在可信任 LAN 或裝置 AP 使用。

---

# 七、建議 REST API

| Method | Path | 用途 |
| --- | --- | --- |
| GET | `/api/v1/device` | 裝置識別、API version、容量 |
| GET | `/api/v1/status` | 完整 runtime snapshot |
| GET | `/api/v1/auth/status` | 登入狀態與 CSRF |
| POST | `/api/v1/auth/login` | 建立密碼或登入 |
| POST | `/api/v1/auth/logout` | 登出 |
| GET | `/api/v1/wifi/scan` | 掃描 Wi-Fi |
| POST | `/api/v1/wifi/config` | 儲存 Wi-Fi 並重啟 |
| GET | `/api/v1/config` | 讀取遮蔽後的設定 |
| POST | `/api/v1/config` | 更新設定 |
| POST | `/api/v1/weather/test` | 測試 OpenWeatherMap |
| GET | `/api/v1/images` | 圖片 catalog |
| PUT | `/api/v1/images/{name}` | 串流上傳已處理圖片 |
| DELETE | `/api/v1/images/{name}` | 刪除圖片 |
| POST | `/api/v1/images/{name}/activate` | 設為目前圖片 |
| POST | `/api/v1/images/advance` | 手動下一張 |
| POST | `/api/v1/images/order` | 更新輪播順序 |
| GET | `/api/v1/sensors` | 感測器與讀值 |
| GET | `/api/v1/events` | 系統事件 |
| POST | `/api/v1/system/reboot` | 重新啟動 |
| POST | `/api/v1/system/recovery-ap` | 進入 Recovery AP |
| POST | `/api/v1/system/ota` | 本機 OTA |

統一回應格式：

```json
{
  "ok": true,
  "data": {}
}
```

錯誤格式：

```json
{
  "ok": false,
  "error": "storage_full",
  "message": "圖片儲存空間不足"
}
```

---

# 八、儲存與 Partition 規劃

16 MB Flash 建議至少分為：

* NVS。
* OTA metadata。
* App Slot A。
* App Slot B。
* `webfs`。
* `imagefs`。
* 選用 coredump。

`webfs` 與 `imagefs` 必須分離：

* 更新 WebUI 不得刪除使用者圖片。
* OTA 不得覆寫圖片。
* 圖片格式更新需由 migration 處理。
* `uploadfs` 只更新 `webfs`。

實際 partition 大小應在第一次完整編譯後，依韌體大小決定；但必須從第一版就保留雙 OTA slot，避免日後修改 partition table 導致使用者圖片被清除。

設定使用 NVS，並包含：

* `schema_version`
* Wi-Fi
* WebUI auth
* display
* carousel
* weather
* timezone
* environment sensor
* light sensor
* last successful image
* boot／OTA state

圖片 catalog 存於 `imagefs`，採交易式 JSON 或小型 binary index。

---

# 九、FreeRTOS 架構

```text
app_main
 ├─ ConfigManager
 ├─ FileSystemManager
 ├─ RuntimeCoordinator
 ├─ DisplayTask
 ├─ SensorTask
 ├─ NetworkServiceTask
 ├─ WeatherWorker
 ├─ StorageWorker
 └─ esp_http_server
```

### DisplayTask

* 電子紙唯一 owner。
* 負責 SPI、BUSY、reset、sleep。
* 負責組合狀態列與圖片資料。
* BUSY 必須有 timeout。
* 刷新過程不得阻塞 HTTP server。

### SensorTask

* 溫溼度 probe／read。
* 光線 ADC 取樣與濾波。
* 在場防抖。
* 發送 `presence_return`／`presence_away` command。

### NetworkServiceTask

* Wi-Fi STA／AP。
* SNTP。
* mDNS。
* 重連與連線健康狀態。

### WeatherWorker

* OpenWeatherMap HTTPS。
* 快取與退避。
* 不直接操作面板。

### StorageWorker

* 圖片串流寫入。
* CRC。
* Catalog 更新。
* OTA／NVS／LittleFS 操作序列化。

### RuntimeCoordinator

* 唯一 runtime snapshot。
* Command queue。
* Result queue。
* HTTP server 只讀 snapshot 或送 command。

---

# 十、建議加入但可排在第二階段的功能

## P1

* 多 Wi-Fi profile。
* WebUI OTA。
* 設定與圖片 catalog 匯出／匯入。
* 每張圖片自訂顯示時間。
* 每週顯示排程與安靜時段。
* 圖片批次上傳。
* 圖片標籤與篩選。
* 溫溼度歷史圖表。
* 光線與在場歷史。
* Discord 裝置上線／錯誤通知。
* 自動清理最舊圖片。
* GPIO pin map WebUI 顯示。
* 面板測試色塊與接線診斷頁。

## 暫不納入

下列功能雖存在於參考專案，但與本專案核心用途關聯較低：

* Claude／Codex 使用量。
* HydraCup MQTT。
* Bambu Lab MQTT。
* 蜂鳴器與整點提示。
* 音效播放。
* 完整書桌前年度熱力圖。
* AI 語音提醒。

---

# 十一、MVP 驗收條件

| 情境 | 驗收結果 |
| --- | --- |
| NVS 無 Wi-Fi | 自動進入 AP，面板顯示 SSID、密碼及 IP |
| AP 掃描 Wi-Fi | 清單正確顯示並可帶入 SSID |
| 儲存 Wi-Fi | 回應成功後重啟並連上 STA |
| Wi-Fi 密碼錯誤 | 連線逾時後重新進入 AP |
| OpenWeatherMap 離線 | 圖片仍輪播，顯示最後快取與 stale 狀態 |
| 溫溼度感測器未安裝 | WebUI 顯示未偵測，API 為 `null`，裝置正常運作 |
| 光敏電阻未安裝 | `presence=UNKNOWN`，不得清屏或暫停輪播 |
| 光線持續低於／高於條件 | 達防抖時間後才切換在場狀態 |
| 判定離席 | 全白刷新一次並 sleep |
| 判定返回 | 立即重繪目前圖片 |
| 橫向圖片 | 精確輸出 800×440 圖片區 |
| 直向圖片 | 精確輸出 480×760 圖片區並正確旋轉 |
| 圖片上傳中斷電 | 下次開機不出現半張圖片，能復原 catalog |
| CRC 錯誤 | 拒絕圖片且不覆寫既有檔案 |
| imagefs 空間不足 | 明確回傳 507 類型錯誤 |
| 面板 BUSY timeout | WebUI 保持可用並記錄錯誤 |
| 新圖片手動啟用 | 至少完整顯示一個輪播週期 |
| 未登入修改設定 | 回傳 401 |
| 缺少 CSRF 修改設定 | 拒絕請求 |
| 刷新完成 | 面板進入 sleep |
| 裝置重新啟動 | 圖片、順序、設定與目前圖片完整保留 |

---

# 十二、建議的第一版開發範圍

第一版應完成：

1. ESP-IDF／PlatformIO 專案骨架。
2. NVS、`webfs`、`imagefs` 與雙 OTA partition。
3. `epd7in3e` ESP-IDF driver。
4. AP／STA 狀態機。
5. 登入、session 與 CSRF。
6. 統一 WebUI theme。
7. 圖片瀏覽器端編輯、六色 dithering 與 PFR1 打包。
8. 圖片交易式上傳與 catalog。
9. 橫向／直向 renderer。
10. 30 分鐘輪播排程。
11. OpenWeatherMap 與 SNTP。
12. 溫溼度及光敏電阻的 Null driver、狀態與 WebUI。
13. 光敏電阻防抖、離席清屏、返回重繪。
14. 系統狀態與基本診斷 API。

這個範圍完成後，即使兩個感測器都尚未安裝，裝置仍是一個完整可用的電子紙圖片輪播系統；感測器接上後只需啟用對應 driver 與 GPIO 設定，不需重構 WebUI、API 或主流程。

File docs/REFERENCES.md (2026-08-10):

# 參考來源與授權

本文件固定 `docs/archive/Guild.md` 所述三個參考專案的來源版本。Phase 0 只採用設計概念
與已驗證的工作模式；尚未複製任何參考專案原始碼。未來若移植程式或資產，
該 commit 必須保留來源、license notice，並再次檢查來源版本。

## 採用基線

| 專案 | 固定版本 | License | 本專案採用內容 |
| --- | --- | --- | --- |
| [epaper-home-display](https://github.com/Ning0612/epaper-home-display) | `db561872b2389c0ed11d1ae55e4a01b7ec3a6753` | MIT | WebUI 資訊架構、圖片操作語意、renderer／輪播／狀態模型 |
| [pico-paper-clock](https://github.com/Ning0612/pico-paper-clock) | `6b042bbe5bdf0cd7e396f2e70797c201e36a45b3` | MIT | 低記憶體串流、交易式檔案更新、設定遷移、感測器缺席與防抖 |
| [esp32-hydracup](https://github.com/Ning0612/esp32-hydracup) | `2103b4376218e30e9bfae9320b2b48ba1e55ccf8` | MIT | PlatformIO＋原生 ESP-IDF、FreeRTOS owner 邊界、NVS/LittleFS、AP 與 Web server |

固定版本取自 2026-07-29 本機 checkout 的 `HEAD`，remote 均為表中 GitHub
repository。這些 commit 是需求來源的追溯基線，不是 Git submodule 或自動
同步來源。

## 專案授權決策

PaperFrame 採 MIT License，與三個同作者參考專案一致。MIT 相容不代表可以
刪除第三方 copyright 或 notice：

- 複製或大幅改作來源程式時，在檔案或 `NOTICE` 中保留來源與 license。
- 字型、圖示、圖片、JavaScript library、電子紙 driver 分別核對其授權。
- Waveshare／Espressif 官方範例若在 Phase 2 引入，先固定來源版本與授權。
- 只有設計概念而未複製表達形式時，仍在 ADR 或 commit 中記錄 provenance。

## 工具與 SDK 文件

- [PlatformIO Core](https://docs.platformio.org/en/latest/core/index.html)
- [PlatformIO Espressif 32](https://github.com/platformio/platform-espressif32)
- [ESP-IDF Programming Guide](https://docs.espressif.com/projects/esp-idf/en/latest/)

Phase 1 會在 `platformio.ini` 固定實際通過 build 與實機 smoke 的 platform
版本；文件中的 `latest` 連結只供查閱，不作為可重現版本規格。

## Phase 2 Waveshare driver baseline

- 產品／接線：
  [7.3inch e-Paper HAT (E) manual](https://www.waveshare.com/wiki/7.3inch_e-Paper_HAT_%28E%29_Manual)
- Upstream：[waveshare/e-Paper](https://github.com/waveshare/e-Paper)
- 固定 commit：`06e834491bf62023a1b86a481b4530978883d2c4`
- 固定來源與 SHA-256：
  - `RaspberryPi_JetsonNano/c/lib/e-Paper/EPD_7in3e.c`：
    `010E08A7053219076E707EBE2210BEF7C38ABB11EB8F975418F451EA8D9D895C`
  - `RaspberryPi_JetsonNano/c/lib/e-Paper/EPD_7in3e.h`：
    `D454685677EAC06CEEA24F9E64BE05782491E41491050C7A7B78186AEF73BD66`
  - `RaspberryPi_JetsonNano/python/lib/waveshare_epd/epd7in3e.py`：
    `7E12ECECFF0A75C84EEB32B2A324B3CECA49D08E1A108175A467C8417BD64572`

三個來源檔均帶有 Waveshare MIT permission notice。實際 pin map、六色 native
code、BUSY timeout 與 lifecycle 決策固定於
[ADR-0003](adr/0003-fix-phase2-display-integration.md)。

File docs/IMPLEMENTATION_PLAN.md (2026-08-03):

# PaperFrame MVP 實作計畫

狀態：Phase 5、Phase 6、Phase 7 程式實作完成；Phase 3／4 的部分實機收尾、
Phase 5 實機圖片輪播驗證、Phase 6 全部實機驗證（SNTP、HTTPS、狀態列視覺
結果）與 Phase 7 全部實機驗證（DHT22 讀值、光敏 threshold 校正、
AWAY/PRESENT 轉換）仍待完成，暫不部署大功能版本

需求基線：`Guild.md` v0.1

目標平台：ESP32-S3、16 MB Flash、PSRAM、7.3 吋 800×480 E6 e-Paper

## 1. 目標、範圍與交付策略

本計畫把草案「十二、建議的第一版開發範圍」整理成可依序 build、test、
review 與 commit 的垂直階段。MVP 完成時，即使溫溼度與光敏感測器都未安裝，
裝置仍可完成 AP 配網、受保護的本機管理、圖片處理與交易式上傳、六色輪播、
天氣快取、面板 sleep，以及基本診斷。

MVP 不包含草案第十節的 P1 功能，例如多 Wi-Fi profile、批次上傳、週排程、
歷史圖表、Discord 通知與自動清圖；也不包含 MQTT、蜂鳴器、音效或 AI 功能。

交付原則：

- 先建立能持續編譯與測試的最小骨架，再加入硬體功能。
- 優先把資料格式、狀態機、排程、防抖與交易復原寫成可在 host 測試的純邏輯。
- 每段以一個可回退、可驗證的 Conventional Commit 完成；功能與直接相關測試
  放在同一 commit。
- 硬體相依功能必須同時保留 fake/null implementation，讓無周邊環境可測。
- 每一階段通過其 exit criteria 後才進入下一階段；不得用後續階段補齊前段
  遺漏的安全、錯誤處理或測試。

## 2. 開工前決策 Gate

以下項目在對應階段開始前必須以實機資料、官方文件或 ADR 固定，不能直接以
草案中的「建議」當作已驗證事實：

| Gate | 最晚完成 | 需要固定的決策 |
| --- | --- | --- |
| G1 開發板 | Phase 1 | 精確模組／board ID、Flash/PSRAM 模式與容量、USB/UART 上傳方式 |
| G2 Pin map | Phase 2 | e-Paper SPI/BUSY/RST/DC/CS、ADC、DHT/I²C GPIO；避開 GPIO35–37 |
| G3 Driver | Phase 2 | `epd7in3e` 來源、版本、授權、六色 mapping、BUSY polarity 與 timeout |
| G4 PFR1 | Phase 4 | byte order、header 固定長度、enum/flags、CRC 涵蓋範圍與版本遷移規則 |
| G5 Partition | Phase 1 開發版；第一個可保存圖片的 Phase 5 build 前凍結發行 layout | 雙 OTA、NVS、webfs、imagefs、coredump 的 offset/size；後續變更的資料保護與 migration |
| G6 Security | Phase 3（PBKDF2 參數已由 `docs/adr/0007-auth-pbkdf2-iterations-and-sync-login.md` 固定，2026-08-01） | PBKDF2 參數、session token entropy/storage、首次設定與 Recovery AP 流程；密碼至少 8 字元、idle 30 分鐘、absolute 24 小時是需求固定值 |
| G7 Weather | Phase 6（已由 `docs/adr/0005-weather-worker-and-status-bar.md` 固定，2026-07-31） | OpenWeatherMap endpoint/version、TLS trust、cache schema 與 rate limit |

若缺少實體硬體，可先完成 host-tested interface 與 fake driver，但該階段不得
標成 hardware complete。

## 3. 共通技術基線

### 3.1 Runtime 邊界

```text
HTTP handlers ─┐
WeatherWorker ─┼─> command queue -> RuntimeCoordinator -> owner task
SensorTask ────┘                        │
                                       └─> immutable/read-only snapshot

DisplayTask: panel/SPI 唯一 owner
StorageWorker: imagefs/catalog/OTA 寫入序列化
NetworkServiceTask: STA/AP/SNTP/mDNS 狀態 owner
```

HTTP request 不得等待 25 秒面板刷新。長操作回傳 accepted/result ID，狀態由
snapshot 或 result endpoint 取得。Display、storage 與 OTA 共享的臨界區需明確
定義 lock order，避免 flash cache 關閉期間存取 PSRAM。

### 3.2 測試層次

- Host unit：PFR1、CRC、檔名驗證、catalog recovery、輪播、防抖、時間計算、
  設定遷移、session/CSRF 純邏輯。
- Component/integration：NVS、LittleFS、HTTP route、queue、weather parser。
- On-device smoke：boot、PSRAM、partition、AP/STA、mDNS、panel、ADC、OTA。
- Fault injection：CRC 錯誤、空間不足、`.part`／`.bak` 殘留、BUSY timeout、
  Wi-Fi 密碼錯誤、DNS/API/TLS 失敗、sensor absent。
- Browser：圖片轉換順序、四種 fit、兩種 dithering、PFR1 golden vectors、
  responsive layout、離線資產與登入/CSRF 流程。

### 3.3 每段標準檢查

1. 需求與差異可追溯。
2. 最小相關測試先通過。
3. `pio run` 通過；若該階段尚無可 build 的 PlatformIO 骨架，需明列原因。
4. staged diff 只含本段內容，沒有 secrets 或 generated output。
5. 獨立 review 無 Critical／High finding。
6. 硬體未驗證項目記入該階段紀錄，不以模擬結果冒充實機結果。

## 4. 分階段計畫

### Phase 0 — Repository baseline

需求來源：草案第一、二、十二節。

交付物：

- 保留原始需求草案並建立專案級 `AGENTS.md`。
- 建立本實作計畫、README、license 決策與 PlatformIO/ESP-IDF 專用
  `.gitignore`。
- 記錄參考專案的精確 URL、採用版本與 license；只移植經授權的概念或程式。
- 建立 ADR 目錄與硬體驗證紀錄格式。

驗收：

- Git branch 為 `main`，每份初始化文件各有清楚 commit。
- 工作樹乾淨，未設定未經授權的 remote。
- 文件清楚區分需求、已決策項目與待驗證假設。

建議 commits：

1. `docs: add initial PaperFrame requirements draft`
2. `docs: define repository working agreements`
3. `docs: add phased MVP implementation plan`
4. `docs: add project overview and reference provenance`
5. `chore: add PlatformIO repository ignores`

### Phase 1 — Buildable ESP-IDF skeleton and persistence foundations

需求來源：草案 4.1、八、九、十二之 1–2。

交付物：

- `platformio.ini`、原生 ESP-IDF `app_main`、component 目錄與 logging 基線。
- G1 board 設定、PSRAM 檢查與可降級 self-test snapshot。
- 初版雙 OTA partition table，分離 `webfs`／`imagefs`。
- NVS schema version、ConfigManager、FileSystemManager 與啟動復原入口。
- RuntimeCoordinator 的 command/result queue 與 snapshot 最小 contract。
- 最小 `esp_http_server` 與公開 health handler/route contract，供後續長操作
  responsiveness 測試；Phase 1 只初始化 httpd 所需的 TCP/IP／esp-netif
  runtime，不建立 `esp_netif_t` interface、不啟動 AP/STA，也不得暴露設定
  或管理操作。

驗收：

- clean checkout 可完成 `pio run`。
- 裝置可 boot，不因缺少面板或感測器而 boot loop。
- partition offset/size 不重疊，實機可掛載兩個 filesystem。
- NVS 空白、schema 相同、可遷移版本與不支援版本都有測試。
- health serializer/handler 在 runtime queue 閒置或忙碌時都不等待 queue、
  filesystem 或硬體，且只輸出非敏感資料。實際經網路存取延至 Phase 3。

建議 commits：

1. `build: scaffold native ESP-IDF firmware`
2. `feat(storage): add versioned NVS configuration`
3. `feat(storage): mount isolated web and image filesystems`
4. `feat(runtime): add command queues and status snapshots`
5. `feat(web): expose a minimal device health endpoint`

### Phase 2 — Display driver, renderer and refresh ownership

需求來源：草案三、4.3、9 DisplayTask、十一的 renderer/BUSY/sleep 驗收、
十二之 3、9–10。

交付物：

- 經 G2/G3 固定的 `epd7in3e` component 與 pin configuration。
- 六色 palette v1、packed 4-bit pixel primitive 與 golden vector tests。
- 橫向 800×440、直向 480×760 renderer，以及邏輯畫面到面板資料的旋轉。
- DisplayTask command/result contract、BUSY timeout、refresh 後 sleep。
- 30 分鐘預設／10 分鐘至 24 小時範圍的輪播核心；空圖庫 welcome/status frame。

驗收：

- packed framebuffer 大小與草案一致：全畫面 192,000 bytes、橫向圖片區
  176,000 bytes、直向圖片區 182,400 bytes。
- pattern/golden test 驗證六色、邊界 pixel、直向旋轉與狀態列位置。
- fake panel 驗證只有 DisplayTask 觸發 SPI lifecycle。
- fake/concurrency test 驗證 BUSY timeout 不阻塞 Phase 1 health handler；
  實機經網路存取在 Phase 3 驗證。刷新完成後 panel sleep。

建議 commits：

1. `feat(display): add six-color packed framebuffer primitives`
2. `feat(display): integrate the epd7in3e panel driver`
3. `feat(display): render landscape and portrait frames`
4. `feat(display): serialize refresh commands in DisplayTask`
5. `feat(carousel): schedule full-refresh image rotation`

### Phase 3 — Provisioning, authentication and WebUI shell

需求來源：草案 4.1–4.2、五、六、七的 auth/wifi endpoints、十一的
AP/STA/401/CSRF 驗收、十二之 4–6。

交付物：

- NetworkServiceTask：STA/AP、timeout、重試、SNTP 與 mDNS 狀態。
- AP 顯示 command 與離線 provisioning WebUI；scan 結果去重、排序及過濾。
- AP 畫面 payload 包含 SSID、password、`192.168.4.1`、操作步驟、
  Wi-Fi/WebUI QR code 與裝置尾碼；內容未變時不得重複刷新。
- provisioning AP ready 後，若圖片庫沒有可顯示圖片則持續保留 AP 畫面；
  有圖片時保留 5 分鐘 grace window，再恢復 carousel。AP presenter、
  carousel 與 presence blank submission 必須序列化，避免 welcome/image
  frame 覆蓋 AP 畫面或與 Wi-Fi 啟動競態。
- 至少 8 字元密碼、強雜湊、單一 server-side session、30 分鐘 idle、
  24 小時 absolute expiry 與 CSRF。
- 共用 `style.css`／`ui.js`／favicon、login 與 responsive navigation shell。
- `/api/v1/device`、health、auth、wifi config 與 masked config endpoints；
  route policy 明確區分永久公開、首次 bootstrap 與登入後管理面。
- Dashboard 初版以 runtime snapshot 顯示裝置、網路、SNTP、容量、版本、
  uptime 與可取得的 carousel/display 狀態；後續 phase 增量加入圖片、
  weather 與 sensor 欄位。

驗收：

- 空白 NVS 進入 AP；有效憑證進 STA；錯誤密碼 timeout 後回 AP。
- AP 畫面有 golden payload test；相同內容不刷新。credential 以交易方式
  保存，成功 response 後約 1 秒 reboot，連線失敗可再次進 AP。
- AP 畫面在空圖片庫時維持顯示；有可顯示圖片時，自 AP ready 起 5 分鐘後
  才切換圖片，且不可被 welcome frame、presence blank 或 concurrent
  display submit 提前覆蓋。
- DNS、weather 或 Internet 錯誤只改變 Internet 狀態，不進 AP。
- credential 不出現在 URL、log、response、snapshot 或診斷包。
- `<8` 字元密碼被拒絕；fake-clock 測試涵蓋 30 分鐘 idle 與 24 小時
  absolute expiry；新登入撤銷舊 session。
- 永久公開面只含安全的 device/health、auth status 與 login／首次建密碼。
  尚無管理密碼且位於首次 provisioning AP 時，wifi scan/config 可作為
  bootstrap 例外；完成建密碼後（含 Recovery AP）相同 route 需 session，
  wifi config 亦需 CSRF。
- 其餘未登入的 GET 與 mutation 都回 401；需保護的 POST、PUT、DELETE
  缺少／錯誤 CSRF 時被拒絕。公開 endpoint 只回安全資料。
- AP 無 Internet 時所有 WebUI asset 仍可載入。
- 經 AP 與 STA 實機驗證 health endpoint 在 display command 忙碌或 timeout
  時仍可回應。

建議 commits：

1. `feat(network): add AP and STA connection state machine`
2. `feat(web): add offline provisioning portal`
3. `feat(auth): protect management sessions and mutations`
4. `feat(web): add shared responsive management shell`

### Phase 4 — Browser image pipeline and PFR1 contract

需求來源：草案 4.5–4.6、五的圖片頁、十二之 7。

交付物：

- G4 的 `docs/formats/PFR1.md` 與跨 C++/JavaScript golden vectors。
- 瀏覽器載圖、EXIF orientation、透明白底、鏡像、旋轉、fit/crop、縮放。
- Floyd–Steinberg、Atkinson 六色量化 Web Worker；Crop/Cover 預覽支援拖曳定位與 100%–300% 裁切縮放。
- 原圖／處理後／面板畫面預覽與輸出尺寸、方向、大小提示；六色量化仍在背景完成並用於 PFR1 打包。
- 圖片頁可保存 Random／隨機輪播設定；來源圖片上限為 6,400 萬像素（檔案仍限 32 MB）。
- JavaScript PFR1 packer 與韌體端 streaming parser/validator。

固定轉換順序：

1. 水平鏡像。
2. 垂直鏡像。
3. 順時針旋轉。
4. 裁切或 fit。
5. 縮放。
6. 六色量化與 dithering。

驗收：

- 同一 golden input 在 browser 與 firmware 得到相同 header、payload、CRC。
- landscape/portrait、透明圖、EXIF、四種 fit、兩種 dithering、裁切 anchor/縮放與 Random 設定有測試。
- 拒絕錯誤 magic/version/orientation/palette/dimensions/length/CRC/filename。
- 瀏覽器只上傳受限制的 packed PFR1，不上傳任意大小 RGB framebuffer。

建議 commits：

1. `docs(format): define the PFR1 binary contract`
2. `feat(image): validate streamed PFR1 payloads`
3. `feat(web): transform and crop source images`
4. `feat(web): quantize previews with a dithering worker`
5. `feat(web): pack PFR1 images from the browser`

### Phase 5 — Transactional image storage, catalog and library

需求來源：草案 4.6–4.7、七的 image endpoints、八的 imagefs/catalog、
十一的斷電/CRC/507/目前圖片驗收、十二之 8。

交付物：

- 在第一個可保存使用者圖片的 build 前凍結 G5 發行 partition layout，
  記錄 checksum 與後續 migration 規則。
- StorageWorker streaming upload 與容量預檢。
- `.part`／`.bak` transaction、開機 recovery 與 catalog atomic update。
- Catalog schema：名稱、時間、方向、大小、enabled/current/corrupt 狀態與順序。
- 圖片 list/upload/delete/activate/advance/order API。
- 受保護的 `GET /api/v1/images/{name}/download`，以固定 PFR1 MIME、
  安全的 `Content-Disposition` 與檔名回傳已處理圖片。
- 圖片庫 UI、storage usage、排序、批次刪除與 processed file download；目前完成
  catalog 顯示、processed file download、PFR1 upload、delete／activate／排序 UI、
  async API 與 carousel runtime 讀圖／橫直向 framebuffer 組合已完成。

驗收：

- fault injection 涵蓋每個 rename/catalog 邊界；重開後只保留舊或新完整版本。
- 發行 partition table 與 G5 記錄一致，升級測試證明不會重格式化或位移
  `imagefs`。
- CRC 錯誤不覆寫既有圖片；空間不足回一致的 HTTP 507 error contract。
- 所有 image route（含 download）都需登入；download 不得由未受保護的
  imagefs 靜態路徑繞過 session。
- 刪除 current image 時先更新 catalog/runtime，再刪檔並選下一張有效圖片。
- 損毀／遺失圖自 playlist 排除，新圖及手動啟用圖至少完整顯示一個週期。

建議 commits：

1. `build: freeze the image-preserving partition layout`
2. `feat(storage): persist images transactionally`
3. `feat(storage): recover interrupted image transactions`
4. `feat(images): maintain a durable image catalog`
5. `feat(api): manage images and carousel order`
6. `feat(web): add the image library workflow`

### Phase 6 — Weather, time and status rendering

需求來源：草案 4.3–4.4、七的 weather endpoint、九 WeatherWorker、
十一的 weather offline 驗收、十二之 11。

交付物：

- WeatherWorker HTTPS client、G7 response parser、cache schema 與退避。
- API key masked config、test endpoint、最後成功時間與 stale 狀態。
- SNTP 未同步、同步中、有效時間與時區處理。
- 日期、星期、weather icon/temperature/stale 標記的狀態列 renderer。
- 顯示 deadline 提前約實測 refresh duration，完成時間貼近排程邊界。
- Dashboard 增量顯示 weather cache、Internet 與 SNTP 狀態。

驗收：

- API key invalid、DNS/TLS/timeout、HTTP error、parse error 有不同診斷狀態。
- 失敗保留最後有效 cache；完全無 cache 顯示 `--°` 與離線狀態。
- weather cache 更新不直接刷新面板，只在下一個 display command 使用。
- 未同步時間不產生 1970 或其他假日期。

建議 commits：

1. `feat(weather): cache OpenWeatherMap observations`
2. `feat(time): track SNTP and timezone state`
3. `feat(display): render weather and time status`
4. `feat(web): configure and test weather access`

### Phase 7 — Optional sensors and presence behavior

需求來源：草案 4.8–4.9、五的環境頁、七 sensors endpoint、九 SensorTask、
十一的 sensor/presence 驗收、十二之 12–13。

交付物：

- EnvironmentSensor interface 與 null driver（`LightSensor` 抽象介面／
  `NullLightSensor` 已於 2026-08 移除：production 從未透過它讀值，
  `SensorTask::sample_light()` 直接呼叫 `adc_oneshot_read()`，是零實作的
  死抽象層；`LightSensorStatus`／`MovingAverageFilter` 不受影響，仍在用）。
- DHT22 driver 的讀取頻率、range validation、stale cache 與 backoff。
- ADC sampling/filter、threshold、saturated/error 判斷與可調防抖。
- `UNKNOWN`／`PRESENT`／`AWAY` state machine。
- 離席只白屏一次並 sleep；返回立即重繪且重設輪播 deadline。
- 環境 API/UI：driver、GPIO、reading、stale、ADC、threshold、presence。
- Dashboard 增量顯示環境、light sensor 與 presence 狀態。

驗收：

- 未安裝／未啟用時裝置正常輪播；API 缺值為 `null`，presence 為 `UNKNOWN`。
- 浮動、saturated 或 error ADC 不得觸發離席。
- 只有條件連續滿足 180 秒／30 秒才切換 AWAY／PRESENT。
- task 重啟或漏失 transition 後，輸出仍依穩定狀態收斂到正確 panel 狀態。

建議 commits：

1. `feat(sensors): add optional environment sensor contracts`
2. `feat(sensors): sample and classify ambient light`
3. `feat(presence): debounce away and return states`
4. `feat(display): clear and restore frames for presence`
5. `feat(web): expose sensor and presence status`

### Phase 8 — Diagnostics, OTA hardening and MVP acceptance

需求來源：草案五的系統頁、七 system endpoints、八、十、十一、
十二之 14。

交付物：

- 結構化 ring-buffer events 與 masked diagnostics export。
- `/api/v1/status`、events、reboot、Recovery AP；OTA 僅能使用 Phase 5
  前已凍結的 G5 partition layout，不在本階段重新分割既有裝置。
- 系統頁：BUSY timeout、Wi-Fi reconnect、weather/sensor error、容量、版本、
  uptime、最近 refresh result。
- 完成 Dashboard 的目前圖片、下次輪播、network/SNTP、weather、display、
  sensors、Flash/PSRAM/imagefs、版本與 uptime 欄位。
- watchdog、queue saturation、lock timeout 與 reboot reason 可觀測性。
- 完整 MVP test matrix、實機 soak/power-loss 測試與 release checklist。

**範圍調整（2026-08-01，實機測試後）**：原規劃的「Recovery AP」管理員
手動觸發端點（`POST /api/v1/system/recovery-ap`，讓已連線 STA 的裝置
手動切回 provisioning AP）已**完整移除**，不在 Phase 8 交付範圍內。
原因：實機測試時，在 STA 已連線狀態下觸發這個路徑會讓 ESP-IDF 的
AP+STA combo 模式啟動流程崩潰（DMA-capable heap 實測僅剩數 KB，遠低於
安全水位，詳見 `docs/hardware/VALIDATION.md` 2026-08-01 段落）；即使
加上 heap 安全檢查把崩潰改成優雅失敗，這個功能在目前硬體的實際記憶體
餘裕下仍然無法真正成功執行。與使用者確認後，這個手動端點並不對應
真正的使用情境——WiFi 連不上時，Phase 3 既有的自動 fallback AP
已經涵蓋「重新配置 Wi-Fi」這個需求，不需要額外的手動路徑。`/api/v1/
status`、events、reboot 三項交付物維持不變。

驗收：

- 診斷資料不含 secrets、session token、Wi-Fi password 或完整 API key。
- OTA A/B 可回滾，且不改寫 `imagefs`；WebUI 更新只改寫 `webfs`。
- 面板 timeout、weather failure、sensor failure 不影響 HTTP 管理介面。
- Dashboard 每個欄位來自同一 runtime snapshot，缺少可選資料時顯示明確
  unknown/stale 狀態，不偽造數值。
- 草案第十一節每個情境都有自動測試或可重現實機測試證據。
- 重新啟動保留設定、圖片、順序與目前圖片。

建議 commits：

1. `feat(diagnostics): expose bounded runtime events`
2. `feat(system): add protected recovery controls`
3. `feat(ota): update firmware without touching images`
4. `test: cover the PaperFrame MVP acceptance matrix`
5. `docs: add hardware validation and release checklist`

## 5. MVP 驗收追蹤

| 草案第十一節情境 | 主要 Phase | 最低證據 |
| --- | --- | --- |
| NVS 無 Wi-Fi／AP 掃描／儲存／密碼錯誤 | 3 | on-device integration |
| OpenWeatherMap 離線 | 6 | host fake + on-device network fault |
| 溫溼度未安裝 | 7 | host null driver + on-device boot |
| 光敏未安裝 | 7 | host state machine + floating ADC check |
| 離席／返回防抖 | 7 | deterministic fake-clock tests |
| 離席白屏 sleep／返回重繪 | 7 | fake panel + on-device display |
| 橫向／直向圖片 | 2、4 | golden vectors + panel patterns |
| 上傳斷電復原／CRC／空間不足 | 5 | filesystem fault injection |
| BUSY timeout | 2、8 | fake timeout + on-device forced BUSY |
| 新圖片手動啟用 | 5 | carousel fake-clock test |
| 未登入／缺少 CSRF | 3 | HTTP integration tests |
| 刷新後 sleep | 2 | driver trace + power/current observation |
| reboot persistence | 1、5、8 | repeated on-device reboot test |
| 診斷資料不含 secrets／session token／Wi-Fi 密碼／完整 API key | 8 | 程式檢視（所有 `record_diagnostic_event` 呼叫端皆固定字面值，無插值）+ host test |
| OTA A/B 可回滾且不改寫 `imagefs` | 8 | host test（`compare_semver`／`extract_tag_name`）+ on-device 真實下載、刻意燒毀版本驗證 bootloader rollback |
| 面板 timeout／weather／sensor 失敗不阻塞 HTTP 管理介面 | 1、2、6、7、8 | 結構性保證（async worker task + non-blocking `lock_flash_display`）+ on-device |
| Dashboard 每個欄位來自同一 runtime snapshot | 8 | host test（`serialize_status` 欄位含 null-safety 回歸） |

## 6. 里程碑與停止條件

- M0：Phase 0；需求、工作規則與交付路徑可追溯。
- M1：Phase 1–2；韌體可 build、boot 並安全控制面板。
- M2：Phase 3；可離線配網與安全管理。
- M3：Phase 4–5；圖片可在 browser 轉換並可靠保存、輪播。
- M4：Phase 6–7；weather 與可選感測器完成降級路徑。
- MVP：Phase 8；完整驗收矩陣有證據且無阻擋 finding。

遇到以下情況停止擴張 scope，回到需求／ADR：

- 精確 board、pin map、driver license 或 PFR1 contract 未定。
- partition 變更可能清除既有 imagefs。
- 需要 HTTP handler 直接操作硬體才能完成設計。
- 測試要求依賴真實秘密、外部 CDN 或不可重現的手動狀態。
- 同一失敗在相近條件重現兩次而沒有新證據。

## 7. 目前 checkpoint

- [x] 原始 `Guild.md` 納入版本控制。
- [x] 初始化 `main` branch。
- [x] 建立專案級 `AGENTS.md`。
- [x] 建立分階段 MVP 計畫與 commit 邊界。
- [x] 保留 `Guild.md` 作為原始匯入快照；其跳脫 Markdown 不在初始化時
  原地改寫，若需可讀版將另建衍生需求文件。
- [x] 補齊 Phase 0 的 README、reference provenance、license 決策與 `.gitignore`。
- [x] 完成 G1 board 決策與 Phase 1 build、host／embedded tests、實機
  boot／mount 驗證。
- [x] 完成 G2 pin map 與 G3 display driver 決策後開始 Phase 2。
- [x] `epd7in3e` driver 通過 host/build 與實機六色 pattern 驗證；refresh
  時間、panel sleep 電流與 forced-BUSY 隔離治具仍列為硬體待驗證項。
- [x] 完成 Phase 2 renderer、DisplayTask owner contract、30 分鐘／10 分鐘至 24 小時
  輪播核心與空圖庫 welcome frame；catalog-backed 圖片載入、離線輪播與
  橫直向 PFR1 framebuffer 組合已在 Phase 5 接入。
- [ ] Phase 3：AP／STA 純狀態機、provisioning portal、credential transaction、
  auth/CSRF 與 WebUI shell 已完成程式、host test、build、STA 啟動 smoke，
  以及正常 STA 登入後 Dashboard、Wi-Fi scan 與桌面版寬度驗證；最新
  artifact 的 blank-NVS／Recovery AP 瀏覽器流程、SNTP/mDNS 仍待實機收尾，
  故尚未標記 M2 完成。
- [ ] Phase 4：PFR1 contract、韌體 validator、browser image pipeline、
  quantizer、packer 與 host tests 已完成；可正常選檔的 browser 實機圖片
  產出／下載仍待補驗，未把 `image_02_05.png` 納入版本控制。
- [x] Phase 5：partition layout、catalog、transaction upload、boot recovery
  與 `StorageWorker::start()` 的 imagefs 啟動接線已完成並通過 host／firmware
  build；受保護的 image list/upload API、serializer、PFR1 download route、圖片庫
  catalog/download/upload/delete/activate/order UI、async API 與 carousel runtime
  讀圖／面板提交已完成。離線輪播不依賴 Wi-Fi；硬體長時間輪播與斷電後實機驗證
  仍保留在後續 acceptance。
  `image_02_05.png` 僅作本地測試，不得 commit。
- [ ] Phase 6：G7 已由 `docs/adr/0005-weather-worker-and-status-bar.md` 固定。
  程式已完成：`pf_weather` parser/cache 與設定持久化／masked config API
  （`af4a2c5`、`56d5644`、`14d787f`）；NetworkServiceTask 最小 SNTP 啟動與
  `RuntimeSnapshot.time_sync`；`pf_weather_worker`（2026-08 已併入
  `pf_weather`，見下方 Phase 7 之後的過度設計整併記錄）（`esp_http_client` +
  `esp_crt_bundle_attach` 實際 HTTPS 抓取、interval-aware 排程、
  `report_internet_state` 回報）；`RuntimeSnapshot`／`RuntimeCoordinator`
  天氣欄位；Dashboard `weather` JSON 三態（available/stale/unavailable）；
  `pf_display` 自製 bitmap font／9 種天氣圖示／狀態列 renderer；已接線進
  carousel 圖片幀與 welcome frame。`pio run` 與 `pio test -e native`
  （192/192）全綠，`test_runtime_coordinator`／`test_display_task`
  embedded test 通過 build-only 驗證。**尚未做任何實機驗證**：SNTP 實機
  同步、WeatherWorker 四種 HTTPS 診斷狀態（含 TLS 憑證驗證）、
  Internet 可達性訊號、狀態列在真實面板上的視覺結果，全部列在
  `docs/hardware/VALIDATION.md` 2026-07-31 待驗證清單。
- [ ] Phase 7：DHT22 driver 來源、讀取頻率/範圍/backoff、光敏濾波方式、
  presence debounce 機制、`CarouselScheduler` 缺口方案與 sensors API
  schema 已由 `docs/adr/0006-sensor-drivers-and-presence.md` 固定。
  程式已完成：`pf_sensors` 純邏輯 component（`EnvironmentCache`／
  `DailyStats`／`MovingAverageFilter`／`PresenceTracker`）；
  `pf_config::SensorSettings` 持久化；`RuntimeSnapshot`／
  `RuntimeCoordinator` 感測器欄位；移植自 `UncleRus/esp-idf-lib`
  （commit `162af418d4702791fd3bf3e5d1577aea9ec5539c`，BSD-3-Clause）的
  `pf_dht22` driver；`pf_sensor_task`（DHT22 週期讀取＋ADC 光敏取樣＋
  presence debounce，接線進 `app_main.cpp`）——`pf_dht22`／`pf_sensor_task`
  皆已於 2026-08 併入 `pf_sensors`，見下方過度設計整併記錄；`CarouselScheduler::
  force_immediate` 與 `render_blank_frame`，離席時暫停輪播、返回時立即
  重繪；Dashboard `sensors` JSON 三態；`GET /api/v1/sensors`、
  `/api/v1/sensors/config` API 與 WebUI 環境頁。`pio run` 與
  `pio test -e native`（225/225）全綠，`node --check data/web/ui.js`
  通過。**尚未做任何實機驗證**：DHT22 實際讀值、光敏 ADC 實測與
  threshold 校正、AWAY/PRESENT 實機轉換、離席全白刷新＋sleep 電流、
  返回重繪與 deadline 重設、WebUI 環境頁瀏覽器行為，全部列在
  `docs/hardware/VALIDATION.md` 2026-07-31 Phase 7 待驗證清單。
- [x] 2026-08 過度設計整併（下一輪，網路/安全性之後）：`pf_dht22`＋
  `pf_sensor_task` 併入 `pf_sensors`，`pf_weather_worker` 併入 `pf_weather`，
  namespace 統一；刪除死抽象層 `pf_sensors::LightSensor`／
  `NullLightSensor`（production 從未透過它讀值，直接呼叫
  `adc_oneshot_read()`）。純重構，不改變執行期行為。元件數 14→11。
  `pf_carousel`／`pf_image` 折疊評估後判定會製造循環依賴，本輪維持現狀
  （見 `docs/hardware/VALIDATION.md` 對應記錄）。`pio run` 與
  `pio test -e native`（226/226）全綠，codex-cowork 審查通過。
- [ ] Phase 8：OTA 韌體來源（裝置直連 GitHub Releases）、TLS 信任重用、
  版本比對唯一來源、rollback 確認時機（開機自動）與 release 檔名慣例已由
  `docs/adr/0008-ota-github-releases-and-rollback.md` 固定。
  程式已完成：`pf_runtime` 新增 `diagnostics_event.hpp`（32 筆 ring
  buffer）、`reboot_reason.hpp`（`esp_reset_reason_t` 分類）、
  `firmware_version.hpp`（SemVer 風格版本比對，含 overflow 防呆與
  pre-release precedence，非完整 SemVer 2.0.0 parser——已於程式註解記錄
  簡化範圍）；`RuntimeCoordinator` 新增 queue/lock 計數器（與對應診斷事件
  在同一 critical section 內原子關聯）、OTA check/update 狀態欄位、
  carousel 目前圖片／下次刷新欄位、`schedule_reboot()`（timer 於
  `initialize()` 單執行緒建立，杜絕跨 task 首次建立競態；
  `ESP_ERR_INVALID_STATE`＝已被排程視為成功而非失敗）；新 component
  `pf_ota`（GitHub tag_name 解析、`esp_https_ota` stepwise 下載、
  admin-triggered、`busy_` atomic 防重疊請求，`task_handle_ == nullptr`
  防呆避免 worker 未啟動時請求永久卡死）；`pf_web` 新增
  `GET /api/v1/events`、`POST /api/v1/system/reboot`、
  `GET/POST /api/v1/system/ota/*` 路由與對應 access policy；Dashboard
  `current_image`/`next_refresh_ms` 由 hardcode null 改為真實值；WebUI
  新增「系統」頁（面板/網路/容量/版本/OTA/重開機/最近事件，兩個 CSRF
  保護的操作按鈕：重新啟動、立即更新）。經 7 輪 codex-cowork 審查
  （Milestone 1-3 診斷/OTA 變更 3 輪、Milestone 4 Dashboard/System 頁
  1 輪、實機崩潰修正 3 輪）修正阻斷性問題後收斂。`pio run -e
  paperframe-s3` 成功（RAM 71.1%／232,944 bytes——`pf_ota` 的
  24576-byte task stack 是主要增量，尚未經實機 high-water-mark 量測）、
  `pio test -e native`（265/265）全綠、`node --check data/web/ui.js`
  與 `test/web/test_system_ui_contract.mjs` 通過、
  `test_embedded/test_runtime_coordinator` 以 `--without-uploading
  --without-testing` 完成 build-only 驗證。

  **實機測試發現並修復真實崩潰**（2026-08-01，詳見
  `docs/hardware/VALIDATION.md` 對應段落）：原本規劃的「Recovery AP」
  手動端點在 STA 已連線時觸發 AP+STA combo 模式，讓 Espressif 閉源
  WiFi blob 在 beacon buffer 配置失敗時崩潰重開機。已加上
  `heap_caps_get_largest_free_block(MALLOC_CAP_DMA)` 安全檢查（保護
  `start_access_point()` 的全部呼叫端，不只這個手動端點），並在複測時
  確認不再崩潰、優雅進入 failed 狀態；但同時測出實際 largest free DMA
  block 只有 1728 bytes（遠低於安全水位），確認這個手動端點在目前硬體
  記憶體餘裕下無法真正成功執行，且與使用者確認後，它並不對應真正的
  使用情境（WiFi 不通時 Phase 3 既有的自動 fallback AP 已經涵蓋這個
  需求）——**已完整移除** `POST /api/v1/system/recovery-ap`
  route/handler、`pf_web::recovery_ap_allowed`、
  `pf_network::request_recovery_ap()`、WebUI 對應按鈕與測試斷言；heap
  安全檢查本身保留（仍保護 blank-NVS 首次開機與 STA 重試耗盡 fallback
  這兩個既有路徑）。過程中順帶修正一個獨立真實 bug：`OtaWorker::
  request_check_for_update()`／`request_update_now()` 若在 worker
  未成功啟動時被呼叫，會誤報成功並讓 `busy_` 永久卡死。

  **尚未做任何實機驗證**：真實 GitHub 下載與 rollback、真實 panic 後
  reboot_reason、OTA worker 實機 stack high-water-mark、weather+OTA
  併發 heap 量測、System 頁瀏覽器實際行為、`start_access_point()`
  heap guard 對 blank-NVS／STA-retry-fallback 這兩個既有路徑的實際影響
  （尚未觸發過這兩條路徑做複測），全部列在 `docs/hardware/
  VALIDATION.md` 2026-08-01 Phase 8 待驗證清單。附帶發現一個與本階段
  無關的既有回歸：`test/web/test_image_download_contract.mjs` 曾在本分支
  所依據的 `fix/auth-simplify-network-merge` 基底 commit（`b79c29b`）
  斷言失敗；該分支的 upload keep-alive 重構把
  `close_session = !result.ok() || ...` 改寫成
  `close_session = !drain_image_upload_body(...)`，測試字面比對沒有同步
  更新。此 contract 已在 GitHub CI/release automation 變更中同步修正。

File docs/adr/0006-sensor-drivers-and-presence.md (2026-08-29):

# ADR-0006：感測器 driver 來源與在場/離席判定機制

- Status: accepted（部分被取代）
- Date: 2026-07-31
- Supersedes: none
- Superseded in part by: [ADR-0018](0018-dual-photoresistor-channels.md)
  ——光敏電阻擴充為兩個獨立通道後，本 ADR 的
  「溫濕度與光敏電阻在本階段维持各自獨立判定，不合併」條款與
  `GET /api/v1/sensors` 的 `light` schema 已失效；以及
  [ADR-0020](0020-light-clip-is-diagnostic-not-presence-gate.md)——
  `saturated`（ADC 頂到量測極限）不再視為「不得觸發離席」的一員，改為
  診斷資訊並正常參與判定，`LightSensorStatus::saturated` 拆分為
  `low_clipped`／`high_clipped`。濾波方式（moving average）、
  duration-based debounce、未偵測到／讀取錯誤／通道停用不得觸發離席、
  presence 經 snapshot setter 傳遞等其餘決策**均維持有效**。

## Context

Phase 7（`docs/archive/IMPLEMENTATION_PLAN.md`）要加入 DHT22 溫溼度感測器與光敏
電阻在場/離席偵測。`docs/archive/Guild.md` 4.8/4.9 節只給出定性描述與少數「建議值」
（離席 180 秒／返回 30 秒，WebUI 可調），沒有精確的讀取頻率、範圍驗證
數字、濾波演算法選擇、debounce 實作機制或 `GET /api/v1/sensors` 的
JSON schema；這些都必須在實作前固定，不能直接當作已驗證事實。

掃描確認：全 repo 目前沒有任何 sensor/presence 相關程式碼；GPIO pin map
已由 [ADR-0003](0003-fix-phase2-display-integration.md) 固定（光敏 ADC＝
GPIO5／`ADC1_CH4`，DHT data＝GPIO6，I²C SDA/SCL＝GPIO8/9 留給未來
I²C 感測器，GPIO4 已被 BUSY 佔用）；`CarouselScheduler` 目前沒有任何
「立即到期」或「重設 deadline」的方法，而原始需求草案明確要求返回時
「輪播計時重新開始…不使用離席前殘留的刷新 deadline」，這是必須新增的
API 缺口。

## Decision

### DHT22 driver 來源與授權

移植 `UncleRus/esp-idf-lib`（<https://github.com/UncleRus/esp-idf-lib>）
的 `components/dht` 與 `components/esp_idf_lib_helpers`，commit
`162af418d4702791fd3bf3e5d1577aea9ec5539c`（2026-02-18，查證於
2026-07-31）。授權為 BSD-3-Clause（Copyright (c) 2016 Jonathan
Hartsuiker、Copyright (c) 2018 Ruslan V. Uss），原生支援
`DHT_TYPE_AM2301`（即 DHT22/AM2302），公開 API 為同步阻塞式
`esp_err_t dht_read_float_data(dht_sensor_type_t sensor_type,
gpio_num_t pin, float* humidity, float* temperature)`。

移植進 `components/pf_dht22/third_party/`，保留原始授權標頭，並附上
`LICENSE-dht.txt`／`LICENSE-esp_idf_lib_helpers.txt`（比照 `epd7in3e`
面板 driver 移植 Waveshare 上游程式碼＋ADR 記錄來源的既有做法）。單線
bit-bang 時序邏輯本身**不修改**——這段程式碼已被社群專案長期驗證過，
本專案沒有硬體可重新驗證微秒級時序正確性，重寫風險遠高於移植風險。

實際移植時發現並修正一處建置可攜性問題（非時序邏輯）：`dht.c` 上游寫
`#include <ets_sys.h>`，但本專案使用的 ESP-IDF 6.0.0 沒有這個裸檔名的
相容 shim，`ets_delay_us()` 只在 target-scoped 的 `<rom/ets_sys.h>`
（`esp_rom` component）宣告；已改為 `#include <rom/ets_sys.h>` 並在
移植檔案內加註記，不影響任何時序數值或協定邏輯。CMakeLists 依實測
REQUIRES `esp_driver_gpio esp_rom freertos pf_sensors`（`PRIV_REQUIRES
log`）：上游的 esp8266 分支已移除，`driver` 改用本專案既有慣例的
`esp_driver_gpio`；`ets_sys.h` 需要額外 REQUIRES `esp_rom`，這點是移植
時透過實際編譯錯誤查證得到，不是原始上游文件記載的依賴。

### DHT22 讀取頻率、範圍驗證與 backoff

- 有效範圍：溫度 -40°C ~ 80°C、濕度 0% ~ 100%（DHT22/AM2302 datasheet
  規格，非原始需求草案指定，本 ADR 自行決定）。
- 正常輪詢間隔與失敗後的指數退避／上限，沿用 `pf_weather::Cache` 的
  `record_success/record_failure/retry_due/stale` 設計形狀——這套模式
  已在 Phase 6 實作並通過 codex-cowork 審查，直接複用降低設計風險，不
  重新發明。`pf_sensors::EnvironmentCache` 的 interval/backoff 常數可與
  `pf_weather` 的數值不同（DHT22 datasheet 下限為每 2 秒一次，遠比天氣
  API 頻繁，正常輪詢間隔取遠高於此下限的值，避免感測器過熱誤差與匯流排
  雜訊累積）。

### 光敏電阻濾波方式

採用 moving average（原始需求草案 4.9 允許 moving average 或 median 擇一）。
選擇理由：固定大小 ring buffer 記憶體與計算成本都低於 median（不需
排序），且本產品的環境光是「緩慢漸變」場景（自然採光隨時間漸變，非
瞬間尖峰雜訊為主），moving average 已足夠平滑；median filter 對脈衝雜訊
的優勢在此場景效益有限。

### Presence debounce 機制

時間追蹤式（duration-based），不是離散事件驅動狀態機（不比照
`NetworkStateMachine`）：`PresenceTracker` 記錄目前穩定 `state` 與目前
候選 `candidate`／候選起始時間 `candidate_since_ms`；每次取樣得到的
瞬時判定若與 `candidate` 不同就重設候選與起始時間；候選持續維持超過
對應 duration（離席用 `away_duration_s`，返回用 `return_duration_s`，
預設 180／30 秒，`SensorSettings` 可調）才把 `state` 切為候選值。

`LightSensorStatus` 為 `disabled`／`not_detected`／`error`／`saturated`
時**一律不推進候選判定**，直接視為 `PresenceState::unknown`——對應
原始需求草案 4.9「不把 ADC 浮動值視為離席」與十一節「浮動、saturated 或
error ADC 不得觸發離席」。只有 `LightSensorStatus::online` 時才進行
threshold 比較與 debounce。（2026-08-29 更新：`saturated` 這一項已被
[ADR-0020](0020-light-clip-is-diagnostic-not-presence-gate.md) 取代——
拆分為 `low_clipped`／`high_clipped`，兩者現在都正常參與 debounce，只有
`disabled`／`not_detected`／`error` 才維持本段原意「一律不推進候選判定」。
但兩者**不透過 threshold 比較**決定方向——方向由 status 直接決定
（`low_clipped` 一律 away、`high_clipped` 一律 present），只有 `online`
才用 raw 與 threshold 比較；threshold 是 0–4095 的可調欄位，沒有保證落在
飽和門檻內，直接比較會有方向反轉風險，詳見 ADR-0020。）

不額外加入 threshold 之外的 hysteresis band：原始需求草案唯一指定的抗頻閃
機制就是 duration debounce 本身，額外加窄化/加寬 threshold 屬於超出
需求的臆測設計，不列入本階段範圍。

### CarouselScheduler API 缺口

新增一個公開方法（精確簽名於實作時依測試驅動定案），語意為「讓下一次
`poll()` 立即判定到期」，用於 presence 從 away／unknown 轉為 present 時
呼叫，滿足原始需求草案「返回後…輪播計時重新開始…不使用離席前殘留的刷新
deadline」。新增時必須保留 `in_flight_`／`manual_pending_` 既有不變量
（不可讓一次強制到期繞過 in-flight 保護，否則會與既有的 request/complete/
abandon 生命週期衝突），並補上對應 host test。

### Presence 狀態傳遞路徑

不擴充 `RuntimeCoordinator` 的 `CommandKind`——Phase 6 已確認這個 queue
是 display-refresh-only 的形狀（`try_submit_command` 內部有
`command.kind == CommandKind::refresh_display` 的特例分支），硬塞第二種
command 需要對應特例處理，徒增複雜度。改用 Phase 6 為 weather／internet
reachability 建立的相同模式：`SensorTask` 直接呼叫
`RuntimeCoordinator::update_environment(...)`／
`update_light_and_presence(...)` 等 setter 寫入 snapshot，`app_main.cpp`
的 carousel poll loop 每輪比較前一輪觀察到的 presence 與目前 snapshot
的 presence，偵測轉換並反應——這與現有 carousel/display 決策迴圈的輪詢
架構一致，不需要新的跨 task 訊息通道。

### `GET /api/v1/sensors` JSON schema

原始需求草案只有「感測器與讀值」一行說明，schema 需自訂：

```json
{"ok":true,"data":{
  "environment":{"status":"online","gpio":6,"driver":"dht22",
    "temperature_c":24.4,"humidity_percent":62.5,"stale":false,
    "today":{"temperature_min_c":18.2,"temperature_max_c":26.1,
      "temperature_avg_c":22.4,"humidity_min_percent":40.0,
      "humidity_max_percent":70.0,"humidity_avg_percent":55.0}},
  "light":{"status":"online","gpio":5,"raw":1234,"threshold":2000,
    "saturated":false},
  "presence":"present"}}
```

未安裝／未啟用時對應欄位為 JSON `null`，不得回傳 `0`（呼應原始需求草案
「API 回傳 `null`，不得回傳 `0`」的明確要求）。

## Consequences

- `pf_dht22` 是本專案第一個包含第三方原始碼移植（而非重寫）的
  component；其 `LICENSE` 檔與程式碼內授權標頭必須隨版控保留，未來
  升級上游版本需重新記錄 commit hash。
- `pf_sensors` 純邏輯與 `pf_dht22`／未來的 `pf_sensor_task` 分離，維持
  「host-testable 純邏輯 vs ESP-IDF 相依 side effect」的既有分層慣例
  （與 `pf_weather` / `pf_weather_worker` 的分離方式一致）。
- `CarouselScheduler` 新增的強制到期方法是本階段對既有已測試模組的
  介面擴充，需要額外注意不破壞 Phase 2 既有的 in-flight／manual
  pending 行為，屬於本階段風險最高的既有程式碼改動點。
- 溫濕度與光敏電阻在本階段维持各自獨立判定，不合併；未來若要加入
  多感測器合併的 presence 判斷邏輯，需要新的 superseding ADR。

## Verification

- `pio run` 與 `pio test -e native` 全綠是本 ADR 所涵蓋所有變更的最低
  驗證門檻；DHT22 bit-bang 時序與光敏 ADC 實際校正無法 host test，須在
  `docs/hardware/VALIDATION.md` 記錄實機驗證結果。
- `components/pf_sensors/third_party/LICENSE-dht.txt`（2026-08 前路徑為
  `components/pf_dht22/third_party/LICENSE-dht.txt`；本行原始撰寫時誤寫
  為 `pf_dht22/LICENSE`，一併修正）內容須與
  `https://github.com/UncleRus/esp-idf-lib/blob/162af418d4702791fd3bf3e5d1577aea9ec5539c/components/dht/LICENSE`
  逐字一致，作為移植合規性的可重現查核點。

## Update (2026-08)

反過度設計整併：`pf_dht22` 與 `pf_sensor_task` 兩個 component 已併入
`pf_sensors`，namespace 統一為 `pf_sensors`（`Dht22EnvironmentSensor`／
`SensorTask` 類別本體與本 ADR 記錄的所有決策不變，純粹是元件邊界調整）。
移植授權檔隨目錄搬遷到 `components/pf_sensors/third_party/`，內容與逐字
查核要求不變。同一輪也刪除了未被 production 使用的死抽象層
`pf_sensors::LightSensor`／`NullLightSensor`（`SensorTask::sample_light()`
一直是直接呼叫 `adc_oneshot_read()`，從未透過這個介面）；
`LightSensorStatus`／`MovingAverageFilter` 不受影響。本文其餘內容提到的
`pf_dht22`／`pf_sensor_task` 是撰寫當下的元件名稱，保留作歷史紀錄。

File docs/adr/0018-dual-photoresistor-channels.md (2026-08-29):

# ADR-0018：光敏電阻擴充為兩個獨立通道，兩顆都暗才判定為暗

- Status: accepted
- Date: 2026-08-23
- Supersedes: [ADR-0006](0006-sensor-drivers-and-presence.md) 的
  「溫濕度與光敏電阻在本階段维持各自獨立判定，不合併」條款與
  `GET /api/v1/sensors` 的 `light` schema
- Amends: [ADR-0003](0003-fix-phase2-display-integration.md) 的 G2
  感測器保留腳位表（新增 GPIO7）
- Superseded in part by:
  [ADR-0020](0020-light-clip-is-diagnostic-not-presence-gate.md)——
  `saturated`（下方多處提及的 ADC 飽和不觸發離席）已改為診斷資訊並正常
  參與判定，`LightSensorStatus::saturated` 拆分為
  `low_clipped`／`high_clipped`。本文件其餘的雙通道接線、AND 合併規則、
  `SensorSettings` v2 與 API schema 的其他欄位**均維持有效**。

## Context

原設計只有一顆光敏電阻（GPIO5／`ADC1_CH4`）。單顆感測器的偵測結果完全取決於
它的擺放位置：被外殼陰影、支架或灰塵遮住時無法區分「環境真的變暗」與「這顆
被擋住了」，而裝置會據此白屏休眠。

使用者要求改為兩顆光敏電阻，各自設定閾值與顯示目前讀值。

**合併規則最初定為 OR**（任一顆低於自己的閾值就休眠），目的是提高「偵測到
遮蔽」的靈敏度。實機接線後當天即改為 **AND**（兩顆都暗才休眠），理由與實測
數據見本文件末的「修訂 2026-08-23：OR → AND」。以下 Decision 描述的是現行的
AND 規則。

ADR-0006 的 Consequences 明文要求「未來若要加入多感測器合併的 presence 判斷
邏輯，需要新的 superseding ADR」——本 ADR 即為該文件。

## Decision

### 第二通道腳位：GPIO7（`ADC1_CH6`）

**必須是 ADC1**：ESP32-S3 的 ADC2 在 Wi-Fi 啟用時由 Wi-Fi driver 佔用，
`adc_oneshot_read()` 會回 `ESP_ERR_TIMEOUT`。本裝置 Wi-Fi 常駐，ADC2 等於
不可用。ADC1 只涵蓋 GPIO1–GPIO10（CH0–CH9），扣掉已佔用與保留者：

| GPIO | ADC1 通道 | 狀態 |
| --- | --- | --- |
| 1 | CH0 | 空（備援） |
| 2 | CH1 | 空（備援） |
| 3 | CH2 | strapping，不可用 |
| 4 | CH3 | 面板 BUSY（ADR-0003 明文禁止改作光感） |
| 5 | CH4 | 光敏電阻通道 1（既有） |
| 6 | CH5 | DHT22 data |
| 7 | CH6 | **光敏電阻通道 2（本 ADR）** |
| 8 | CH7 | 保留 I²C SDA |
| 9 | CH8 | 保留 I²C SCL |
| 10 | CH9 | 面板 CS |

選 GPIO7 是為了讓感測器區塊維持在 GPIO5／6／7 連號，且不動任何既有保留腳位。
GPIO1／GPIO2 保留為備援：若板子排針佈局不便可改用它們，但必須**同時**更換
`sensor_task_esp_idf.cpp` 的 `kLightAdcChannels`（實際讀取的 ADC 通道）與
`light_sensor.hpp` 的 `kLightChannelGpios`（API 與 WebUI 回報的腳位）。兩者是
同一支腳的兩種說法，只改一邊會讓顯示與實際接線不符。除此之外不影響其餘設計。

### 分壓接法與極性

每顆光敏電阻各自一組分壓，**不共用固定電阻**（共用會讓兩路互相拉動，讀值
失去獨立性）：

```
   通道 1                        通道 2
     3V3                           3V3
      │                             │
    LDR-1                         LDR-2
      │                             │
      ├──────► GPIO5                ├──────► GPIO7
      │                             │
    R_fix-1                       R_fix-2
      │                             │
     GND                           GND
```

兩路完全分離：各自一顆 LDR、各自一顆 `R_fix`，只共用 3V3 與 GND。
**同一個分壓節點不可同時接到 GPIO5 與 GPIO7**——那樣兩個 ADC 讀到的是同一個
訊號，雙通道各自的 threshold 與合併判定就失去意義。

可選的抑制雜訊電容也是各自一顆：由各自的 ADC 節點對 GND 接 100nF，
貼近 ESP32 的腳位。

LDR 在上、固定電阻在下的順序是**強制**的：韌體的判定是
`filtered_raw < threshold → away`，因此必須「亮→讀值高、暗→讀值低」。
反接會使閾值語意顛倒。

`R_fix` 沒有在本 ADR 固定數值。韌體以 raw ≤ 10 或 ≥ 4085 判為
`low_clipped`／`high_clipped`（`SensorTask::kSaturationLowRaw`／
`kSaturationHighRaw`；2026-08-29 前為單一 `saturated` 值，且會**不觸發
離席**——已被 [ADR-0020](0020-light-clip-is-diagnostic-not-presence-gate.md)
取代，clip 現在正常參與判定），但貼著極限仍然代表解析度變差，所以整個
關心的光照範圍最好還是落在 raw 11–4084 之間；正確值取決於實際 LDR 型號
與擺放位置，只能實機校正。10 kΩ 為起始建議值，見
[HARDWARE.md](../hardware/HARDWARE.md)。

### 合併規則

`pf_sensors::combine_light_channels()` 把兩個通道 reduce 成 presence
debounce 消費的單一 `(status, raw, threshold)` triple：

- **沒有可用讀值的通道被忽略**，只要還有其他通道有讀值。未安裝或故障的
  第二顆不得讓正常運作的第一顆失效（AGENTS.md：感測器是可選的，必須降級而非
  讓功能整個失敗）。（2026-08-29 更新：原文寫「非 `online` 的通道被忽略」，
  已被 [ADR-0020](0020-light-clip-is-diagnostic-not-presence-gate.md)
  取代——判準是 `light_status_is_decision_capable()`，`low_clipped`／
  `high_clipped` 不算「被忽略」的那一類，只有 `disabled`／`not_detected`／
  `error` 才會被忽略。）
- **先分 present／away 兩側，任何通道落在 present 側就必定從 present 側
  選；margin（`raw - threshold`）只在同一側內部當 tie-break，挑「最有
  代表性」的那顆**（`low_clipped` 一律 away 側、`high_clipped` 一律
  present 側、`online` 用 `raw >= threshold` 分側）。因為 presence 是
  單一門檻比較，這個選擇同時決定了兩個方向：**每個通道都判為暗才算暗，
  任何一顆判為亮就算亮**。換句話說——兩顆都同意暗，面板才休眠；任一顆見光
  就喚醒。回報的是**主導判定的那顆**，也就是目前讓裝置保持清醒（或確認
  全暗）的感測器，那正是「為什麼還沒睡」最有用的答案。
  （2026-08-29 更新：原文寫「`online` 通道中取 signed margin 最大者」，
  單純比 margin 對 clipped 通道並不可靠——`high_clipped` 的 margin 可以是
  很大的負值（例如 threshold 設在 4095），若旁邊有個 margin 沒那麼負但
  實際是暗的 `online` 通道，單純比 margin 會選到暗的那顆，讓合併結果誤判
  成 away，即使有一顆通道明明是亮的。2026-08-29 codex-cowork 第 2 輪抓到
  這個問題，改為上面「先分側」的版本；第 3 輪確認分側規則本身正確、沒有
  遺漏。詳見 ADR-0020「presence 與合併判定」與
  `light_sensor.hpp` 的 `light_channel_reads_present()`。）
- **完全沒有 decision-capable（`online`／`low_clipped`／`high_clipped`）
  通道時**回報最需要處理的狀態，排序為
  `error` > `not_detected` > `disabled`，且不附帶任何讀值
  （`channel_index == kLightChannelCount`，`raw`／`threshold` 皆為 `null`）。
  presence 在這種情況下一律塌回 `unknown`——沿用 ADR-0006 的既有規則，
  浮動或錯誤的 ADC 不得觸發離席。（2026-08-29 更新：`saturated` 原本也在
  這個排序與塌回規則裡，已被
  [ADR-0020](0020-light-clip-is-diagnostic-not-presence-gate.md) 取代——
  拆分後的 `low_clipped`／`high_clipped` 改為 decision-capable，不再落入
  這個分支。）

`update_presence()` 的簽名與 debounce 行為**不變**：合併發生在它之前，
duration debounce（`away_duration_s`／`return_duration_s`）仍是唯一的抗頻閃
機制，兩個通道共用同一組時間參數與同一個 `PresenceTracker`。

### 設定持久化：`SensorSettings` v2

NVS blob 版本由 1 升為 2，欄位改為每通道獨立：

| v1 | v2 |
| --- | --- |
| `light_enabled` | `light1_enabled`、`light2_enabled` |
| `light_threshold` | `light1_threshold`、`light2_threshold` |

`away_duration_s`／`return_duration_s`／`environment_enabled` 不變。

**v1 記錄會被遷移而非丟棄**：`load_sensor_settings()` 以
`nvs_get_blob` 回報的長度區分版本（v1 = 24 bytes、v2 = 28 bytes，兩個 layout
都刻意無 padding 並有 `static_assert` 把關），v1 的單通道設定併入通道 1，
通道 2 以停用＋預設閾值開始——那是「第二顆還沒接」的誠實狀態。載入路徑維持
唯讀，v2 改寫發生在下次儲存時，避免一次失敗的 flash 寫入把原本可讀的設定
變成載入錯誤。`sensor_settings_v1_crc32()` 必須維持 v1 的欄位雜湊順序，
改動它會使所有既有 v1 記錄 CRC 失敗，正好毀掉遷移要保住的東西。

### API 與 WebUI

`GET /api/v1/sensors` 的 `light` 物件改為：

```json
"light":{"status":"online","raw":1234,"threshold":2000,"saturated":false,
  "deciding_channel":1,
  "channels":[
    {"channel":1,"gpio":5,"status":"online","raw":1234,"threshold":2000},
    {"channel":2,"gpio":7,"status":"not_detected","raw":null,"threshold":2500}]}
```

- 頂層 `status`／`raw`／`threshold` 是合併結果，`deciding_channel` 指出來源
  （1-based）。沒有任何 decision-capable（`online`／`low_clipped`／
  `high_clipped`，2026-08-29 由 ADR-0020 從單純的 `online` 放寬）通道時
  三者皆為 `null`——0 會看起來像真的設定值。原本頂層的 `"gpio":5` 移除，
  GPIO 改由每個 channel 自報。
- 每通道的 `threshold` **即使該通道停用或故障也照常回報**：那是使用者設定的
  值，也是校正過程中唯一的參照。只有 snapshot 整個讀不到時才是 `null`。

`GET /api/v1/sensors/config` 與 `POST` 表單欄位同步改名為 `light1_*`／
`light2_*`。**沒有保留舊名相容**：這是編在同一份韌體裡的 WebUI，前後端一起
升級；舊名現在會被 `parse_sensor_config_form()` 當成 `unknown_field` 退回，
比靜默接受一個沒有通道歸屬的欄位安全。表單欄位名是 ui.js 與 C++ parser 之間
的字串契約，兩邊都不會編譯期檢查對方，因此由
`test/web/test_sensor_form_contract.mjs` 雙向比對把關。

## Consequences

- **AND 語意會降低偵測遮蔽的靈敏度**：單顆被外殼陰影或灰塵擋住時不會休眠。
  這是刻意的取捨——誤判離席（使用者在場卻白屏）比漏判離席（該睡沒睡）代價高
  得多。若某一顆長期被燈直射或故障卡在亮值，會導致永遠不休眠；症狀明顯
  （一直不睡），且 WebUI 的 `deciding_channel` 會直接指出是哪一顆。
- **兩顆感測器各自需要校正**：擺放位置不同就看到不同的光，共用一組閾值沒有
  意義。WebUI 同時顯示兩顆的即時 raw 與各自 threshold 就是為了支援這個流程。
- `RuntimeSnapshot` 改存 `light_channels[2]` 與 `light_decision`，取代原本的
  三個平坦欄位。snapshot 仍是 trivially-copyable POD
  （`runtime_coordinator.hpp` 的 `static_assert` 未變）。
- `SensorSettings` v2 的 blob 長度成為版本判別依據，因此兩個 layout 的大小
  **不得相同**，也不得引入 padding。這由 header 的 `static_assert` 與
  `test_sensor_settings` 的尺寸測試同時把關。
- `kSensorConfigBodyCapacity` 由 160 提高到 224：新表單在所有數值欄位都填滿
  7 位數時為 162 bytes，原上限會回 413。
- 實機驗證已於 2026-08-23 完成主要項目（ADC 校正、AWAY／PRESENT 轉換、
  合併判定、離席白屏與返回重繪）；剩餘項目與已接受的風險以
  [VALIDATION.md](../hardware/VALIDATION.md) 為準。

## Verification

- Host tests（`pio test -e native`）：
  - `test_light_sensor_filter` — `combine_light_channels()` 的通道選擇
    （較亮者勝、單一亮通道即維持亮、全部暗才算暗、各自比對自己的閾值）、
    單通道故障時另一通道存活、無 online 通道時的狀態排序與空讀值。
  - `test_sensor_settings` — v2 round-trip 與 CRC、每通道 boolean 驗證、
    v1 遷移、v1／v2 不得互相解碼、兩個 blob 尺寸不得相同。
  - `test_sensor_config_form` — 兩組獨立 enable、第二個 threshold 為必填、
    舊欄位名視為 `unknown_field`、逾長數值拒收。
  - `test_dashboard_serializer` — 兩通道 JSON、`deciding_channel`、單一亮
    通道主導判定、缺席通道被忽略、snapshot 未 publish 時 threshold 為 `null`。
- Web contract（`node test/web/test_sensor_form_contract.mjs`）：ui.js 送出的
  欄位名與 C++ parser 接受的欄位名雙向一致；兩組 threshold input 的
  `min`／`max`／`required` 與韌體的 ADC 範圍一致；每通道讀值元素存在且由
  ui.js 更新。已用 mutation 驗證此測試會變紅。
- Embedded build（`test_runtime_coordinator`）：兩通道寫入 snapshot 後
  `light_decision` 指向合併規則選出的通道。
- **實機驗證（2026-08-23）**：兩通道與 DHT22 接線後完成 ADC 校正、
  AWAY／PRESENT 轉換、離席白屏與返回重繪。完整數據見
  [VALIDATION.md](../hardware/VALIDATION.md) 同日段落。接線與校正步驟見
  [HARDWARE.md](../hardware/HARDWARE.md)。

## 修訂 2026-08-23：OR → AND（同日，實機接線後）

### 為什麼改

本 ADR 原本定為 OR（任一顆低於自己的閾值就休眠）。感測器實際接上後，同一天
的實機量測推翻了這個選擇：

```
GPIO5 2442（亮）   GPIO7 1022   共用門檻 1400   → presence=away
```

燈是亮的、GPIO5 讀到 2442，但 GPIO7 擺在較暗的位置（同環境下只有 GPIO5 的
約 42%），單獨低於門檻就把整台拖進離席。OR 邏輯本身沒做錯——GPIO7 確實低於
它自己的閾值——問題在於**兩顆感測器看到的光本來就不同**，而 OR 讓任何一顆的
局部條件都能代表整個房間。

使用者據此改變需求，以「**兩顆都暗才睡、任一顆亮就醒**」重新表述。

### 決定

`combine_light_channels()` 由取**最小** margin 改為取**最大** margin。因為
presence 是單一門檻比較，這兩個方向必然互補——不可能同時要「任一顆暗就睡」
又「任一顆亮就醒」，那在一亮一暗時會自相矛盾。

理由：

- **語意正確**：要偵測的是「房間暗了」，那是全域狀態。兩顆擺在不同位置本來
  就會看到不同的光，「兩顆都說暗」才等於房間暗了。
- **錯誤代價不對稱**：誤判離席（使用者在場卻白屏）遠比漏判離席（該睡沒睡）
  惱人。AND 減少的正是比較貴的那一種。
- **不犧牲真實偵測力**：實測關燈時兩顆都掉到 30 以下，AND 照樣觸發。

### 影響範圍

實作上只是比較方向反轉，其餘規則完全不變：非 `online` 通道仍被忽略（單顆
故障不影響功能）、狀態排序不變、`deciding_channel` 仍然回報主導的那顆——只是
語意由「最暗的那顆」變成「**最亮的那顆**，也就是讓裝置保持清醒的原因」，
對診斷反而更有用。

host tests 的斷言方向同步反轉，並新增「單一亮通道維持亮」與「全部暗才算暗」
兩個案例；使用者可見文案（WebUI 環境頁、README、HARDWARE.md）一併更新。

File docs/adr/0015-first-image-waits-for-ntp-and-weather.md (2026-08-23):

# ADR-0015：開機首張真實圖片等待 NTP／天氣就緒或逾時

- Status: accepted
- Date: 2026-08-03
- Supersedes: none

## Context

`docs/adr/0014-weather-panel-refresh-cadence-and-map-picker.md` 把天氣更新
改成 carousel 面板刷新被接受後才觸發，不再有獨立定時器。這個模型下，
開機後第一張面板刷新（不論是 welcome frame 還是第一張真實圖片）一定會
在狀態列缺少時間／天氣資料的狀態下先畫一次，之後才由 WeatherWorker 的
第一次嘗試補上——對 welcome frame（圖庫是空的）而言這是可接受的，但對
第一張「真實圖片」而言，使用者觀察到：如果 NTP／天氣其實只需要再等
幾秒鐘就會就緒，讓第一張圖片直接帶著 unknown/未同步的狀態列刷新一次，
之後很快又要再刷新一次補正確資料，體驗不佳。使用者決定：welcome
畫面維持現狀立即顯示；只有第一張「真實圖片」值得多等一下。

## Decision

- `src/app_main.cpp` 新增 `first_image_ready_or_timed_out(now_ms,
  boot_ms)`：在 `kFirstImageReadyTimeoutMs`（60 秒，`boot_ms` 是主迴圈
  開始前記錄的時間點，也就是核心 subsystem 初始化完成之後——這個 60 秒
  上限只涵蓋「等待本身」，不含前面 NVS／filesystem／Display／Network／
  Weather／OTA 等初始化耗時）內，要求 `RuntimeSnapshot.time_sync ==
  synced` 且天氣已經有一次結果（`weather.has_observation` 成功，或
  `weather.last_failure != none` 的失敗，兩者都算——包含 API key 未設定
  時 ADR-0014 新增的「空 key 直接判定 api_key_invalid、不發送 HTTPS
  請求」那條路徑）才算就緒；60 秒後不論是否就緒都直接放行。
- 這個判斷只套用在 carousel 主迴圈既有 decision 分派鏈裡的
  `DecisionKind::display_image` 分支，且只在
  `first_real_image_pending`（一個新增的、只在開機後第一次真實圖片顯示
  前為 true 的旗標）成立時生效；一旦真的送出成功一次，旗標永久轉
  `false`，之後的每次輪播都不再等待。`DecisionKind::display_welcome`
  完全不受影響，一律照舊立即渲染。
- `DecisionReason::manual`（使用者在 WebUI 手動指定要顯示的圖片）明確
  排除在這個等待邏輯之外：這個 gate 是為了「無人值守的自動開機」設計，
  使用者主動操作時應該立即反映，不應該被這個等待邏輯拖慢。
- 未就緒時的處理方式沿用既有的暫時性失敗模式：呼叫
  `carousel.abandon(decision, now_ms + kCarouselRetryMs)`（1 秒後重試），
  不直接動 `CarouselScheduler` 內部狀態，讓下一輪主迴圈重新 poll、重新
  檢查就緒條件。

## Consequences

- 開機後「等待本身」最多多花 60 秒才顯示第一張真實圖片；裝置永久無法
  連上網路（Wi-Fi 連不上、SNTP 永遠不同步）的最壞情況下，這 60 秒會被
  完整用滿一次（僅此一次，不是每張圖片都要等），之後照常運作。這是
  刻意的取捨，不是缺陷。
- 這個邏輯目前只存在 `src/app_main.cpp`（ESP-IDF 整合層），沒有拆出
  host-testable 的純函式版本——`app_main.cpp` 本來就是薄整合層，這條
  dispatch chain 上其餘既有的 accept/abandon/retry 邏輯同樣沒有獨立
  host test，此處維持與既有程式碼一致的慣例，而非引入新的落差。
- 未來若要改變就緒判定條件、逾時秒數，或讓手動啟用之外的其他情境也
  豁免等待，需要新的 superseding ADR。

## Verification

- `pio run`（`paperframe-s3`）與 `pio test -e native`（282 個既有 host
  test，這個功能本身沒有新增可 host-test 的純邏輯）全綠。
- codex-cowork 審查（luna xhigh）：0 Critical，1 High（`boot_ms` 的計時
  起點語意已在程式碼註解澄清，非缺陷）、3 Medium（手動啟用豁免已修正；
  永久離線的一次性 60 秒延遲與缺乏測試覆蓋為已知、可接受的取捨）。
- 尚未驗證項目（記錄於 `docs/hardware/VALIDATION.md`）：實機開機時序
  下這個 60 秒視窗與 welcome/手動啟用互動的實際行為。

> **2026-08-23 後續**：本節描述的 `DisplayOutcome` 契約問題已由
> [ADR-0019](0019-separate-frame-displayed-from-panel-slept.md) 解決
> （`RuntimeResult` 新增 `frame_on_panel`，把「畫面已上到面板」與
> 「面板已 sleep」分開回報）。以下段落保留當時的分析與退避理由——
> 退避本身仍然有效，只是現在只保護真正沒上到面板的失敗。

## Update 2026-08-23：空圖庫的 welcome frame 在取得區網 IP 後重畫一次

### Context

本 ADR 原本的取捨是「welcome frame 帶著未就緒的狀態列先畫一次也可以接受，
反正之後很快會再刷新」。這個前提對「圖庫裡有圖」的裝置成立，但對**全新、
圖庫是空的**裝置不成立：

`CarouselScheduler::poll()` 在圖庫為空且 welcome 已成功顯示後，會回傳
`wait_decision(UINT64_MAX)` 永久停住——這本身是對的，沒有圖片時不該每 30
分鐘重刷同一張靜態畫面（一次全刷約 31 秒）。但 welcome frame 的狀態列上
印著裝置的區網 IP，而開機時 Wi-Fi 還沒拿到位址，於是那台裝置的面板會
永遠顯示沒有 IP 的 welcome frame。使用者因此拿不到位址，也就進不了 WebUI
上傳第一張圖——「之後很快會再刷新」的假設在這條路徑上永遠不會發生。

使用者於 2026-08-23 實機初始化新板時回報此問題。

### Decision

- `CarouselScheduler` 新增 `welcome_stale_` 旗標與
  `request_welcome_redraw(now_ms)`。poll 的永久等待條件改為
  `has_current_ && current_is_welcome_ && !welcome_stale_`；`complete()`
  在 welcome 成功顯示後清除該旗標，因此一次位址變更恰好換得一次刷新。
- `request_welcome_redraw()` 沿用 `force_immediate()` 的 in-flight 保護
  （`complete()`／`abandon()` 依賴它），並在**面板上是真實圖片**時拒絕——
  真實圖片每次輪播都會重畫自己的狀態列，不需要這條路徑。
- `src/app_main.cpp` 記錄目前面板上那張 welcome frame **實際印出的 IP**
  （取自剛渲染的 `StatusBarContent`，不另外再讀一次 snapshot，避免兩次
  讀取之間位址抵達而造成多餘重繪），每個 tick 與現況比對後決定是否請求
  重畫。
- **只有「位址存在且與畫面上的不同」才觸發**。位址消失（Wi-Fi 斷線）
  不觸發：面板留著一個已離開的位址不比留著空白更糟，而每次網路抖動都花
  掉一次 31 秒全刷則是實際成本。
- **welcome 刷新失敗改用短重試**（`kWelcomeRetryMs` = 30 秒，約一次全刷
  時間），不再沿用完整輪播間隔。理由：刷新失敗的 welcome 代表面板上是
  空白（開機時尚未畫過任何東西）或是一張**已知錯誤**的畫面（過期位址、
  或離席留下的白屏）；照原本的間隔要枯等 10 分鐘到 24 小時。
  **圖片刷新失敗維持原本的完整間隔**——面板上還留著前一張圖，內容完好，
  沒有東西要搶救，硬重試只會對一塊剛失敗的面板連續下刷新指令。
- `request_welcome_redraw()` 在「尚未顯示過任何東西」時**允許**（只有
  「面板上是真實圖片」才拒絕）。那正是第一張 welcome 刷新失敗後的狀態，
  也正是最需要再試一次的時候。
- **連續失敗指數退避，上限為正常輪播間隔**（30 秒 → 60 → 120 → …，成功即
  歸零）。理由見下方「已知遺留缺陷」：`refreshed_and_slept` 以外的 outcome
  **不代表畫面沒刷上去**，可能只是 deep sleep 那一步失敗；此時每次重試都是
  對一張已經正確的畫面再做一次全刷。固定 30 秒重試會變成每天約 1,400 次全刷，
  對有刷新壽命的面板是實際傷害。退避上限取正常間隔，等於持續故障時退回裝置
  本來就會用的節奏，同時保留「一次性失敗 30 秒內恢復」。
- **失敗退避不得被重畫請求往前拉**（`welcome_retry_backoff_`）。呼叫端每個
  tick（約 1 秒）都會重新評估條件，若不保護，永久失敗的面板會在每次失敗後
  一秒內就被重設為立即重試，退避形同虛設，變成接近 100% duty cycle 的刷新
  迴圈——對有寫入壽命的電子紙是實際傷害。**一般輪播間隔仍照常被往前拉**，
  那正是位址變更時要重畫的目的。旗標在 `complete()` 失敗且為 welcome 時設定，
  成功時清除，`issue()` 送出重試時清除；`abandon()` 不需處理，因為它只會發生
  在 `issue()` 之後（該處已清除旗標）。
- **presence 返回是刻意的例外**：該路徑同時呼叫 `force_immediate()`，而後者
  不受退避保護，等於一次性洗掉剩餘退避。這是可接受的——presence 轉換本身已由
  duration debounce 限流（預設離席 180 秒／返回 30 秒），不會形成迴圈，而使用者
  剛回到裝置前正是最該立刻重畫的時刻。
- 本 ADR 原本的決定「welcome 不套用 60 秒 NTP／天氣等待、一律立即渲染」
  **維持不變**。這次新增的是顯示之後的重畫條件，不是顯示前的等待條件。

### Consequences

- 空圖庫裝置在取得區網 IP 後會多花一次 31 秒全刷。這是必要成本：沒有它
  使用者無法得知位址。
- 有圖片的裝置行為完全不變（`request_welcome_redraw()` 在該情況下回傳
  false）。
- 未來若要讓「位址消失」也觸發重畫，或把重畫擴大到其他狀態列欄位
  （天氣、時間），需要重新評估刷新頻率的成本。

### 已知遺留缺陷（本次未修，需獨立處理）

**`DisplayOutcome` 把「畫面已刷上去」與「面板已成功 sleep」混為一談。**

依 [ADR-0003](0003-fix-phase2-display-integration.md)，driver 只有完整送出
`DEEP_SLEEP (0x07, 0xA5)` 才標記 deep sleep；`DISPLAY_REFRESH` 之後的
power-off／sleep 序列若失敗，回報的是 `busy_timeout`／`transport_error`。
而 `src/app_main.cpp` 只把 `refreshed_and_slept` 視為成功。因此「畫面確實
刷新成功，但 sleep 那一步失敗」會被當成完全失敗：`welcome_frame_ip` 不提升、
`welcome_stale_` 不清除，於是排程器不斷重刷一張**已經正確的畫面**。

這是**既有行為**，不是本次變更引入的——變更前同樣會重刷，只是每 10–1440
分鐘一次。本次的短重試會放大這個循環，所以加了上述指數退避把它壓回原本的
節奏；但根因沒有解決。

正確的修法是拆開結果契約：「frame 已送達面板」決定 `welcome_frame_ip` 與
scheduler 的 current state，「panel 已成功 sleep」則是另一件事，其復原不應該
再做一次完整 framebuffer 刷新。這會動到 driver → DisplayTask → runtime result
→ app_main → health serializer，且 ADR-0003 已凍結 driver contract，**需要新的
superseding ADR**，因此不併入本次變更。

### Verification

- `pio test -e native`：`test_carousel_scheduler` 由 22 個 case 增為 33 個，
  新增涵蓋——重畫後重新停住、abandon 後仍待處理、面板上是真實圖片時拒絕、
  in-flight 時拒絕、新圖片出現時不被 welcome 蓋掉；兩條刷新失敗路徑
  （初次 welcome 失敗、重畫失敗）走短重試而圖片失敗仍走完整間隔；
  退避保護（呼叫端每 tick 持續請求時退避不被重設、退避到期後請求照常生效、
  一般間隔仍可被往前拉）；連續失敗的指數退避與上限，以及成功後歸零。
  並保留「圖庫持續為空時 welcome 只顯示一次」的回歸測試。全專案 349/349 通過。
- 已用 mutation 驗證新測試確實會變紅：移除 poll 的 `&& !welcome_stale_` 後
  3 個測試失敗；移除失敗短重試分支後 2 個測試失敗（`Expected 30100 Was
  1800100`）；移除退避保護後 2 個測試失敗（`Expected 30100 Was 101`）。
- **實機驗證通過（2026-08-23）**：空圖庫裝置開機後，welcome frame 在
  t≈0.8s 送出（此時尚無位址），IP 於 t≈3.0s 抵達，第一次刷新於 t≈31.9s
  完成，`carousel_welcome_redraw_for_ip` 於同一時刻觸發（刷新進行中依
  in-flight 保護被拒，下一個 tick 才成功），第二次刷新於 t≈63.9s 完成且
  `outcome=1`，之後 `next_due_ms` 回到正常輪播間隔——**一次位址變更只換
  一次刷新**。使用者目視確認面板上 IP、天氣與日期均正確顯示。完整 log 見
  [VALIDATION.md](../hardware/VALIDATION.md) 2026-08-23 段落。
- **仍未驗證**：presence 返回時的 welcome 重畫（需要光敏電阻）；DHCP 續約
  導致位址變更時的重畫；**welcome 刷新失敗後的 30 秒短重試**（需要刻意讓
  面板刷新失敗才能重現，只有 host test 覆蓋）。

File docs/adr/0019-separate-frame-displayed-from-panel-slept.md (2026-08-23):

# ADR-0019：把「畫面已上到面板」與「面板已進入 deep sleep」分開回報

- Status: accepted
- Date: 2026-08-23
- Supersedes: [ADR-0003](0003-fix-phase2-display-integration.md) Verification 段的
  「成功 result 只能在 driver 回報 deep sleep 後發布」——該條款是本問題的來源。
  ADR-0003 的 **driver 行為**（完整送出 `0x07, 0xA5` 才標記 deep sleep、
  BUSY timeout 後 panel state 設為 unknown、下一筆 command 從 hardware reset
  重來）**維持不變**，本 ADR 只改變 driver 結果如何被**回報**給上層。

## Context

`DisplayTask::process()` 把 driver 結果映射成 `DisplayOutcome` 時，只有
「refresh 完成**且** panel 確實進入 deep sleep」才回報 `refreshed_and_slept`；
其餘一律是錯誤值。問題在於刷新序列的後段：

```
3. DISPLAY_REFRESH (0x12), BUSY wait   ← 走完這步，畫面已經在面板上
4. POWER_OFF (0x02), BUSY wait
5. POWER_OFF (0x02), BUSY wait
6. DEEP_SLEEP (0x07), 0xA5
```

第 3 步之後**畫面就已經正確顯示**。若第 4–6 步任一失敗，上層收到的是
`panel_state_error`／`busy_timeout`，而這個結果讀起來像「這次刷新沒有成功」——
於是上層安排重刷。**重刷的是一張已經正確的畫面**，代價是又一次 31 秒全刷與
對應的面板壽命消耗。

`pf_carousel` 的 welcome 重試退避註解已經記錄了這個問題並用指數退避壓制它
（否則固定 30 秒重試會變成每天約 1,400 次刷新）。那是症狀處理：退避降低了
損害頻率，但每次退避結束仍會重刷一張正確的畫面，而且它只保護 welcome frame，
不保護一般輪播與離席白屏。

`docs/PROJECT_STATUS.md` 自 2026-08-23 起把這件事列為已知遺留缺陷，並記載
「正確修法需拆開結果契約並取代 ADR-0003 的 driver contract」。本 ADR 即為該文件。

## Decision

### 在 `RuntimeResult` 增加 `frame_on_panel`

```cpp
struct RuntimeResult {
    std::uint32_t request_id;
    ResultStatus status;
    RuntimeError error;
    DisplayOutcome display_outcome;
    std::uint8_t driver_stage;
    bool frame_on_panel;      // 新增
};
```

`frame_on_panel` 回答「這張畫面是否已經送上面板」，與 `display_outcome`
回答的「這次 command 發生了什麼」正交。

**不採用**「新增 `DisplayOutcome::refreshed_not_slept` 列舉值」的做法。理由：
那會讓一個列舉同時承載兩個維度，錯誤分類會被吃掉——例如 sleep 階段的
BUSY timeout 就無法同時表達「畫面已顯示」與「這是 timeout 而非 panel state
錯誤」。`display_outcome` 的字串詞彙也是 `GET /api/v1/status` 的公開介面，
維持不變可避免既有消費者需要跟著改。

### 判定門檻：`DriverStage` 走過 `refresh` 才算

```cpp
frame_on_panel = driver.stage >= DriverStage::refresh_power_off;
```

`DriverResult::stage` 在失敗時代表失敗發生的階段。門檻取
`refresh_power_off`（而非 `refresh`）是**刻意保守**：`refresh` 階段的
BUSY timeout 代表面板從未確認刷新完成，此時不能宣稱畫面已顯示。

### 上層規則：畫面已在面板上就不重刷

- `frame_on_panel == true` 且 `display_outcome != refreshed_and_slept`：
  **不重新提交這張畫面**。面板停留在 active 而非 deep sleep，代價是耗電，
  不是顯示錯誤。下一次刷新會從 hardware reset 重來（ADR-0003 既有行為），
  屆時面板狀態恢復——**但那次刷新不保證會發生**，見 Consequences。
  `RuntimeCoordinator` 對任何非 `refreshed_and_slept` 的結果都會記一筆
  display diagnostic event，所以這個狀態在 System 頁是可觀察的。
- `frame_on_panel == false`：維持既有的重試／退避行為。

## Consequences

- 刷新成功但 sleep 失敗時，不再浪費一次 31 秒全刷。這是本 ADR 的主要目的。
- **面板可能停留在 active 狀態直到下一次刷新**。空圖片庫時這段可能很長：
  welcome frame 成功後 `CarouselScheduler::complete()` 先設定正常的輪播
  interval，等該 deadline 到期、`poll()` 判定「welcome 已顯示且未過期」
  之後才停在 `UINT64_MAX`。之後仍有三條路徑會再刷新 welcome——IP 變更、
  presence 返回、以及使用者上傳第一張圖片——但都不保證會發生。
  這是**已知且未解的殘留風險**：觸發條件（空圖片庫 ＋ welcome sleep 失敗）
  罕見，且 `RuntimeCoordinator` 會記一筆 display diagnostic event，
  但確實是真實的功耗與面板壽命風險。
- provisioning AP 畫面**不受本 ADR 影響**：該路徑刻意維持以
  `refreshed_and_slept` 為準（PROVISIONING.md：「AP radio 只有在回報
  `refreshed_and_slept` 後才啟動」），sleep 失敗時會重試整次刷新。
  （該路徑另有一個與本 ADR 無關的既有缺陷：payload cache 一旦設立就不再重設，
  導致同一次開機的第二次 AP session 會跳過刷新。該缺陷已於 2026-08-23 一併修復，
  見 `pf_network::AccessPointScreenCache`。）
- 本 ADR **不**新增「只 sleep 不刷新」的 command：ADR-0003 的 driver 只暴露
  `refresh_and_sleep()`，新增 sleep-only 進入點會擴大 driver 契約與
  DisplayTask 的狀態機。那正是上一點殘留風險的正解，留待實機證據顯示這個
  代價顯著時再以新 ADR 處理。
- `pf_carousel` 的 welcome 指數退避**保留**。它現在保護的是真正沒上到面板的
  失敗（transport error、refresh 階段 timeout），退避理由仍然成立。
- `RuntimeResult` 由 8 bytes 增為 12 bytes（含 padding）。它是 static queue
  的元素，佇列深度小，記憶體影響可忽略；`std::is_trivially_copyable_v`
  仍然成立。
- `GET /api/v1/status` 的 `display.last_outcome` 字串集合不變。

## Verification

- Host test：driver 在 `refresh_power_off`、`sleep_power_off`、`deep_sleep`
  階段失敗時，`frame_on_panel` 為 true；在 `validate`、`reset`、`frame_write`、
  `refresh` 階段失敗時為 false。
- Host test：`frame_on_panel == true` 的非成功結果不觸發重新提交。
- 既有的 DisplayTask host/embedded test 對 result mapping 的斷言全數維持通過
  ——`display_outcome` 的映射沒有改變。

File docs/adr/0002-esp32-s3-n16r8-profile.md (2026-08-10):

# ADR-0002：固定 ESP32-S3-N16R8 開發 profile

- Status: accepted
- Date: 2026-07-29
- Supersedes: none

## Context

使用者確認模組標示為 `ESP32-S3-N16R8`。native USB
Serial/JTAG 可被 Windows 枚舉，但截至本 ADR 建立時，
esptool 的 default/no-reset/usb-reset 都尚未收到 ROM serial data，因此
Flash/PSRAM 仍需由韌體 self-test 交叉驗證。

## Decision

- PlatformIO board ID 使用官方 `esp32-s3-devkitc-1` 作為 ESP32-S3 原生
  ESP-IDF 基線。
- 明確覆寫 16 MB Flash、QIO 80 MHz，以及 8 MB octal PSRAM 的
  `sdkconfig.defaults`。
- 不把實際 USB port 寫入 `platformio.ini`；每次 upload 前重新辨識 port。
- Phase 1 不配置任何 e-Paper 或 sensor GPIO。
- 若 boot self-test 與 N16R8 不符，停止燒錄後續功能並修正 profile。

## Consequences

- PlatformIO 內建 board manifest 的預設 N8/no-PSRAM 值不能直接使用。
- generic board ID 不代表已確認實體 DevKit PCB 型號；它只固定 build target。
- ESP-IDF 6 的 QIO image 仍以 esptool `dio` mode 寫入 bootloader，再由
  bootloader 切換至 quad mode；因此以 `CONFIG_ESPTOOLPY_FLASHMODE_QIO=y`
  判斷 build profile，不以 flasher argument 的 `dio` 字串誤判。
- native USB 連線問題與 e-Paper pin map 分別保留為 G1/G2 驗證項。

## Verification

- clean `pio run` 必須使用 16 MB partition table 並啟用 octal PSRAM。
- boot log 必須顯示 16 MB physical Flash 與至少 8 MB SPIRAM capability heap。
- `esptool flash-id` 與 security info 仍需在 ROM download mode 可連線後補記。

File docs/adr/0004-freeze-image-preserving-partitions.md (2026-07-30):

# ADR-0004：凍結 imagefs-preserving partition layout

- Status: accepted
- Date: 2026-07-30
- Supersedes: none

## Context

Phase 5 會第一次把使用者提供的 PFR1 檔案寫入 `imagefs`。在此之後，
任何 app-only upload、WebUI 更新或 OTA 都不能因重新切割 partition 而清除
使用者圖片。開發板是 16 MB Flash，現有雙 OTA layout 已被實機掛載與
app-only upload 驗證；目前尚未有可移動圖片的正式版本，因此此刻是凍結
G5 layout 的最後安全點。

## Decision

以 `partitions/paperframe-dev.csv` 作為目前開發／第一個可保存圖片 build 的
唯一 partition table，維持以下不可移動的資料區：

| Name | Offset | Size | End (exclusive) | 用途 |
| --- | ---: | ---: | ---: | --- |
| `nvs` | `0x009000` | `0x004000` | `0x00D000` | 設定與管理認證 |
| `otadata` | `0x00D000` | `0x002000` | `0x00F000` | OTA metadata |
| `phy_init` | `0x00F000` | `0x001000` | `0x010000` | RF calibration |
| `ota_0` | `0x010000` | `0x280000` | `0x290000` | app slot A |
| `ota_1` | `0x290000` | `0x280000` | `0x510000` | app slot B |
| `webfs` | `0x510000` | `0x100000` | `0x610000` | immutable-at-runtime WebUI asset image |
| `coredump` | `0x610000` | `0x020000` | `0x630000` | bounded crash data |
| `imagefs` | `0x630000` | `0x9D0000` | `0x1000000` | user PFR1 files and catalog |

The exact UTF-8 bytes of the CSV currently have SHA-256:

```text
427FD4144CAF3D8A2F0F0622317F42D6236EA2D7997BAFC42AF13C9CA8565870
```

`imagefs` uses the existing LittleFS partition label and mount point; no factory
image or routine app upload may format or rewrite it. The catalog and image files
must include their own schema/version markers so future data migrations can be
performed in place without moving the partition.

## Consequences

- Phase 5 storage code may rely on the fixed `imagefs` capacity reported by
  `esp_littlefs_info`, but must still preflight free space before writes.
- Changing any offset, size, or partition subtype requires a new superseding ADR,
  an explicit migration/backup plan, and a release gate; it is not a routine build
  change.
- `webfs` updates remain separate from `imagefs`; a WebUI-only flash command must
  target only `0x510000` and never include `imagefs.bin`.
- Development and release partition tables must not silently diverge. A build
  check should compare the selected CSV with this frozen contract before the first
  image-preserving release.

## Verification

- `Get-FileHash -Algorithm SHA256 partitions/paperframe-dev.csv` matches the hash
  above.
- `pio run -e paperframe-s3` uses the same CSV and produces a 16 MB layout.
- Existing hardware validation recorded successful mounting of `webfs` and
  `imagefs`, and app-only upload did not rewrite either partition.
- Before Phase 5 image upload is enabled, add host coverage for non-overlap and
  the imagefs-preserving flash command; any mismatch must fail closed.

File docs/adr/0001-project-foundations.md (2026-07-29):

# ADR-0001：建立專案技術與授權基線

- Status: accepted
- Date: 2026-07-29
- Supersedes: none

## Context

PaperFrame 需在 ESP32-S3 的記憶體與 flash 限制內提供圖片輪播、離線 WebUI、
持久設定與後續 OTA。需求草案同時引用 Raspberry Pi、Pico W 與 ESP32
專案，不能直接把各自的 framework 或 host-only dependency 混入韌體。

## Decision

- 產品與 repository 名稱採 PaperFrame／`esp32-paper-frame`。
- 韌體由 PlatformIO 管理，但只使用原生 ESP-IDF API，不引入 Arduino
  framework。
- PlatformIO Core 固定為 6.1.19；Espressif 32 platform 由 Phase 1 的
  clean build 與實機 smoke 固定。
- WebUI 必須可離線運作，所有 runtime asset 存入 `webfs`。
- `webfs` 與使用者 `imagefs` 分離；從第一個版本保留雙 OTA slot。
- 感測器為可選功能。未接上的光敏與溫溼度感測器不得阻擋 boot 或圖片輪播。
- 專案採 MIT License；參考來源依 `docs/REFERENCES.md` 固定。

## Consequences

- 不能直接移植 FastAPI、Pillow、SQLite 或 MicroPython runtime。
- 純邏輯需保持可做 host test；硬體 owner 由 FreeRTOS task 與 queue 隔離。
- SDK、driver、字型與前端 dependency 必須逐一固定版本與授權。
- exact board、Flash/PSRAM 模式仍由 G1 實機驗證，不在本 ADR 猜測。

## Verification

- `requirements-dev.txt` 可重建 PlatformIO 6.1.19。
- Phase 1 clean build 顯示 framework 為 ESP-IDF，且不含 Arduino framework。
- Phase 1 boot log 記錄 chip、Flash 與 PSRAM 實測結果。

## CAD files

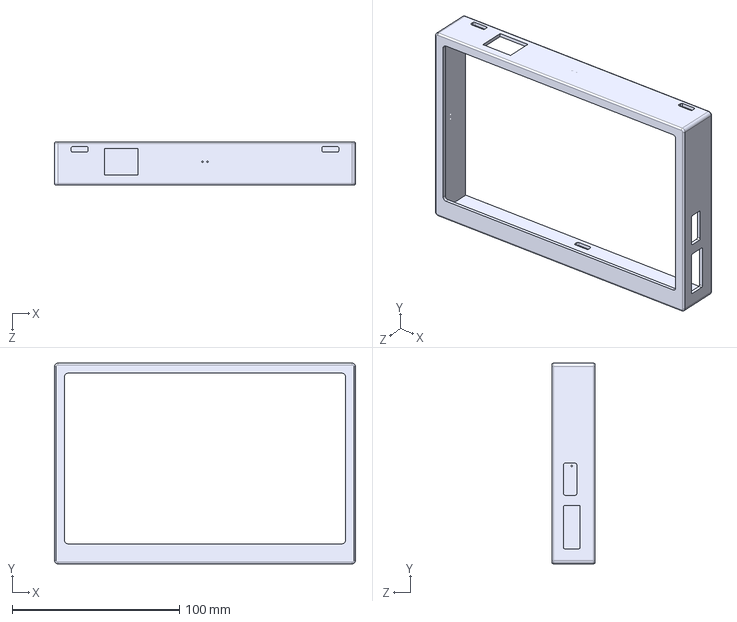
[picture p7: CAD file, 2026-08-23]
hardware/enclosure/02-outer-frame.step
180.0 x 120.0 x 26.0 mm

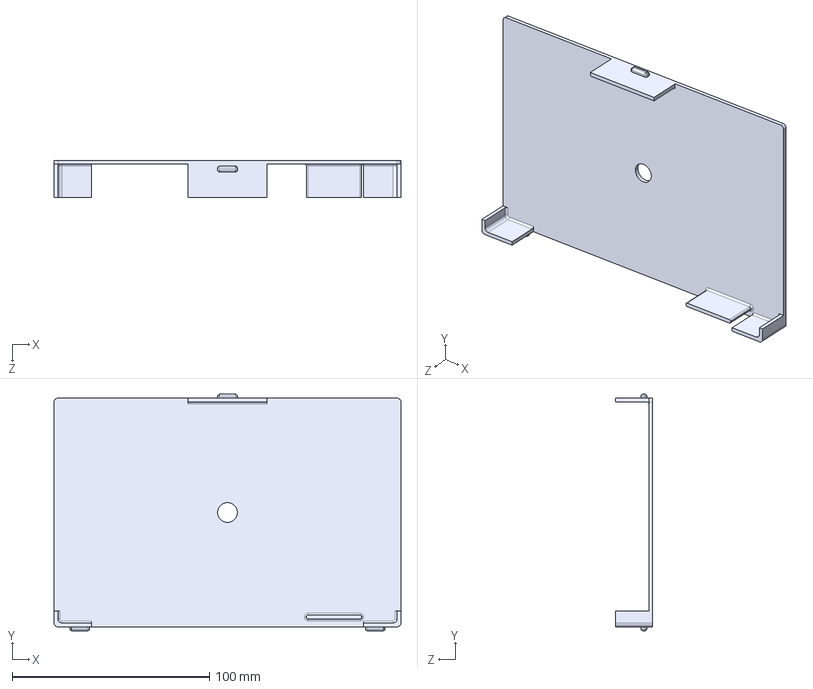
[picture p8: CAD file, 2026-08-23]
hardware/enclosure/05-frame-back-panel.step
176.0 x 120.0 x 19.0 mm

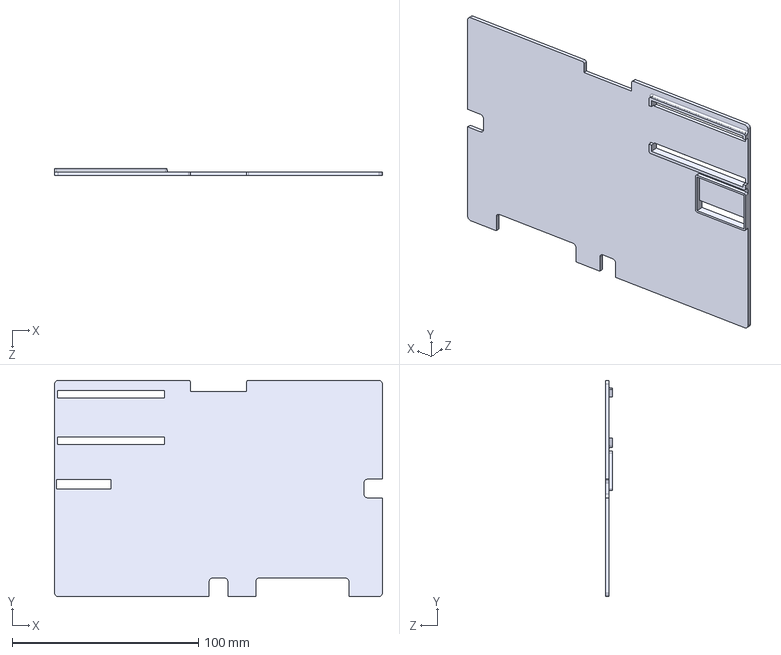
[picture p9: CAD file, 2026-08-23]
hardware/enclosure/03-electronics-back-panel.step
176.0 x 116.0 x 4.00 mm

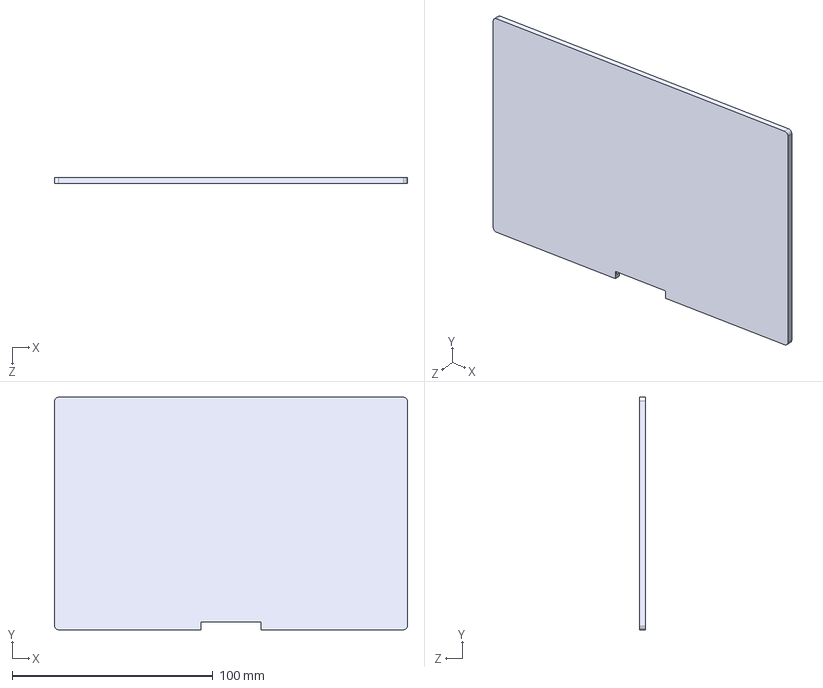
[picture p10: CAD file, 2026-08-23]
hardware/enclosure/01-screen-back-shell.step
176.0 x 116.0 x 3.00 mm

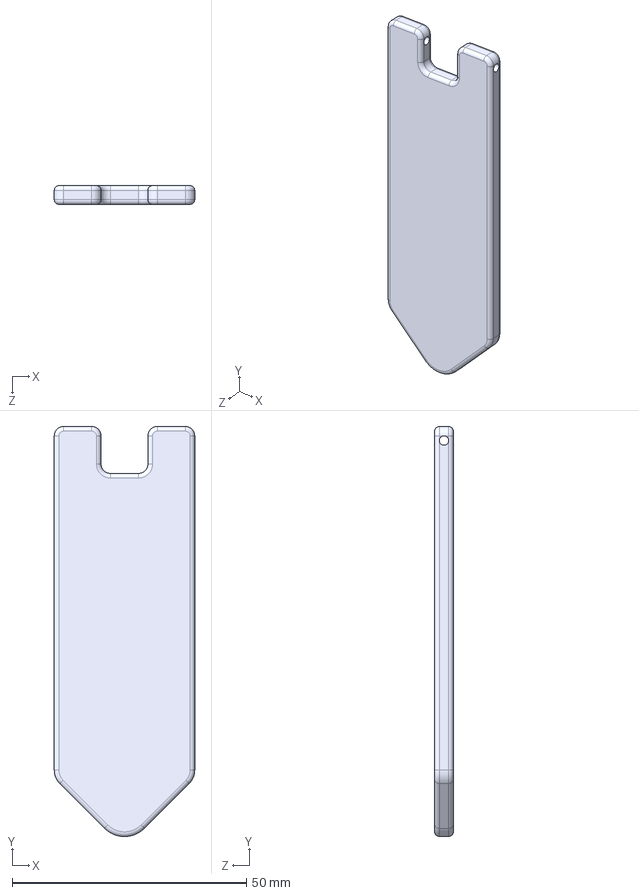
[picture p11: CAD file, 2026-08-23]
hardware/enclosure/06-stand.step
30.0 x 87.5 x 4.00 mm

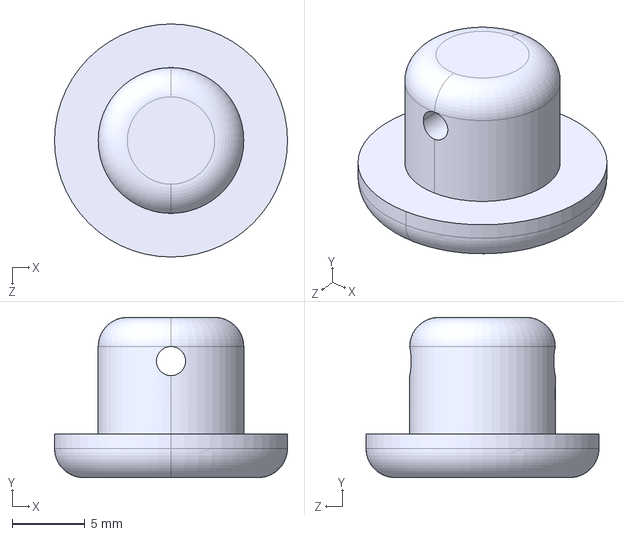
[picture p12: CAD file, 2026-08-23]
hardware/enclosure/04-stand-pivot.step
16.0 x 11.0 x 16.0 mm

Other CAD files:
hardware/enclosure/01-screen-back-shell.stl
hardware/enclosure/02-outer-frame.stl
hardware/enclosure/03-electronics-back-panel.stl
hardware/enclosure/04-stand-pivot.stl
hardware/enclosure/05-frame-back-panel.stl
hardware/enclosure/06-stand.stl

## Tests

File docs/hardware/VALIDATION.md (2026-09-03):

# 硬體驗證紀錄

本檔是可公開的驗證摘要；公開版已移除本機 COM port、USB PNP ID、私人網路
位址、個人工作站路徑與其他裝置識別細節。這些刪節不改變測試結論；需要重現
測試時，請以目前硬體 profile、命令與 acceptance 描述為準。歷史段落保留時間
順序與測試結論；後續新增紀錄仍採 append-only，頂端索引代表目前狀態。

## Current unresolved hardware evidence（2026-08-23）

本檔以下內容是 append-only 的歷史證據；本節只整理目前仍未閉環的項目，
避免把早期「尚未驗證」誤讀成目前狀態，也避免把 host/build 結果當成實機
證據。新紀錄若與本索引衝突，依最新日期的驗證結果更新本節。

| 領域 | 目前仍待驗證 | 主要歷史證據／對照段落 |
| --- | --- | --- |
| Phase 7 sensors | 感測器**行為**已於 2026-08-23 全部閉環（DHT22 讀值與兩條拔除降級路徑、雙通道 ADC 校正、AND 合併語意、AWAY/PRESENT 轉換含正式 180／30 計時、白屏與返回重繪）。仍待驗證：`SensorSettings` v1→v2 的實機 NVS 遷移；**啟用但實體未接線**的通道會讀到什麼（浮接 ADC，需實際拔線才能量）。只接一顆並**正確停用**另一通道的行為已於 2026-08-23 閉環 | 2026-08-23 Phase 7 感測器實機驗證 |
| Welcome／重繪生命週期 | presence 返回時的 welcome 重畫（需感測器實際觸發 AWAY→PRESENT 且圖庫為空）；DHCP 續約導致位址變更時的重畫；welcome 刷新失敗後的 30 秒短重試（需刻意讓面板刷新失敗）。開機取得位址後的重畫已於 2026-08-23 閉環 | [ADR-0015](../adr/0015-first-image-waits-for-ntp-and-weather.md)；2026-08-23 空圖庫 welcome 重畫 |
| AP grace policy | presence 例外（需感測器；5 分鐘切換、SSID 可讀性與 AP/Wi-Fi 併發刷新均已於 2026-08-20 處理） | 2026-08-20 AP 併發刷新；2026-08-20 破壞性測試 |
| 設定降級邊界 | NVS 滿導致 `pf_config` 開啟失敗（低風險；`409 config_read_only` 已閉環，`nvs_flash_init()` 失敗經實測為不可觸發的防禦性分支） | 2026-08-20 破壞性測試；2026-08-20 設定降級邊界修正 |

已自本索引移除的項目：`active OTA upload wrapper`（2026-08-20 以 `ota_0`／`ota_1`
兩種 otadata 狀態各驗一次，寫入位址隨 active slot 改變）、`嵌入式 WebUI`
（2026-08-20 完成 webfs heap 差值量化）、`Phase 6 weather`（2026-08-20 關閉四種
失敗分類，面板狀態列視覺由使用者確認）、`Phase 5 storage` 與 `Phase 8 OTA`
（2026-08-20 完成斷電故障注入與 rollback fault injection）、`Phase 3/4 WebUI`
（2026-08-20 完成 SNTP 失敗側，該領域全數閉環）、`Phase 2 display`
（2026-08-20 完成 forced-BUSY 與 sleep 電流量測）。
`mDNS` 從未實作，不列為待驗證項——詳見 2026-08-20 段落。

`低 DMA heap guard`（原列於 AP grace policy）已於 2026-08-25 從待驗證表格
移除：唯一曾經踩到這個 heap 壓力情境的路徑是「STA 已連線時手動強制進入配網
AP」（`POST /api/v1/system/recovery-ap` → `NetworkEvent::enter_recovery_ap`，
2026-08-01 用來重現／修這個 guard 的正是這條路徑），但該手動端點已經移除
（見 `docs/WEBUI.md`、`docs/archive/IMPLEMENTATION_PLAN.md` 581-583 行；
移除時間點未查到單一對應 commit，以這兩份文件記載為準）。現存的兩個
`start_ap` 進入點（開機空 NVS、STA 重試耗盡）都發生在 STA 連線**之前**，
不會產生同等的 heap 壓力——guard 的程式碼分支本身仍會在每次 `start_ap`
執行，只是低 heap 判斷式在現存路徑下不會為真，因此準確地說是「無現存路徑
可重現該 heap 壓力情境」，不是「分支不可達」；不再列為「待驗證」而是
「無現存路徑可測」。guard 本身的程式碼與 2026-08-01 的既有驗證證據保留
不動。

## 2026-07-29 — 初始 USB 盤點

### 使用者提供狀態

- 模組標示為 `ESP32-S3-N16R8`。
- ESP32-S3 與 7.3 吋 e-Paper HAT (E) 已接上。
- 光敏電阻未接。
- 溫溼度感測器未接。

未接感測器是預期測試條件，不是 boot failure。Phase 1 不初始化這兩種
感測器；Phase 7 才加入 null/absent contract 與實體 driver。

### Windows 偵測結果

| Port | PNP ID | 判定 |
| --- | --- | --- |
| `<NATIVE_USB_PORT>` | `<USB_PNP_ID_REDACTED>` | Espressif USB Serial/JTAG；不是固定 port |
| `<OTHER_PORT>` | `<USB_PNP_ID_REDACTED>` | 非本專案 target；用途未在本專案判定 |

USB VID/PID 只能確認該 port 是 Espressif native USB 介面，不能單獨證明
開發板型號、Flash 容量或 PSRAM 模式。

### G1 驗證結果

- [x] `esptool` 讀取 chip family、revision、features 與 crystal。
- [x] `esptool flash-id` 讀取 Flash manufacturer/device/capacity。
- [x] 固定 PlatformIO profile；upload/monitor port 每次依 USB hardware ID 辨識。
- [x] 最小韌體 boot 並記錄 ESP-IDF、reset reason、Flash 實測容量。
- [x] 最小韌體以 capability heap API 驗證 PSRAM 可用容量。
- [x] 確認 native USB 在 ROM／應用程式模式可能重新枚舉，不固定為單一 port。

### Board A：G1 連線診斷

`esptool 5.3.0 --port <PORT> chip-id` 可開啟該 port，但 default reset、手動
BOOT/RESET 後的 no-reset，以及 native USB 的 usb-reset 都沒有收到 ROM
serial data。此結果可能涉及 boot strapping、reset control、USB 接孔／driver、
外接周邊或連線時序；未執行任何 erase/write。停止重複 esptool 嘗試，先用
N16R8 profile 完成 clean build，後續以持續按住 BOOT 或改接板上 UART USB
介面建立新證據。

### G1 UART 與 boot strap 診斷

後續改接板上 USB-to-UART adapter；adapter identifier 與本機 port 已省略。
正常啟動時該 adapter 可穩定收到 ESP32-S3 ROM
與既有 factory demo 的 log：

```text
ESP-ROM:esp32s3-20210327
rst:0x1 (POWERON),boot:0x8 (SPI_FAST_FLASH_BOOT)
SHA-256 comparison failed:
Attempting to boot anyway...
RGB Demo
```

這證明 ESP32-S3 UART0 TX 到 CH343 RX 與 Windows 接收方向可用。boot log
回報 SHA-256 comparison failed，但未對 Flash 做 readback；該 image 仍能
進入 RGB Demo。此結果不是 PaperFrame 韌體 boot 證據。

排除 e-Paper HAT 後，以 BOOT 按鍵與實體 `GPIO0` 到 `GND` 跳線分別重做
manual download。GPIO0 接地後 RGB Demo 與正常 boot log 停止，但
`esptool 5.3.0` 經 `no-reset` 與 `default-reset` 仍未收到 ROM sync。
將已知可傳資料的 USB 線改接 native USB 後，Windows 未枚舉 Espressif 或
Unknown USB 裝置。未執行任何 erase、write 或 eFuse 操作。

依 Espressif 的 ESP32-S3 boot mode contract，reset 時 GPIO0 為低且 GPIO46
浮接或為低，才會進入 ROM serial bootloader。目前尚缺電氣量測，不能只由
RGB Demo 停止推定 GPIO0、EN 與 GPIO46 的實際 reset 電位。下一個不同證據
必須是以下其中之一：

1. 量測 reset 後 `GPIO0 ≈ 0 V`、`EN ≈ 3.3 V`，並確認 GPIO46 浮接或為低。
2. 使用獨立 3.3 V USB-to-TTL adapter 交叉驗證 UART0 RX/TX，不由板載
   CH343 傳送；板子與 adapter 必須共地、RX/TX 交叉，板子已供電時不得接
   adapter 的 5 V/VCC。
3. 改用另一塊已知可進 ROM bootloader 的同型板交叉驗證。

採用第 3 項後，另一塊同型板成功建立 ROM sync。Board A 的 transport
問題仍未歸因，不把另一塊板成功誤記為 Board A 已修復。

### Board B：G1 與 Phase 1 實機驗證

Board B `ESP32-S3-N16R8` 以板載 USB-to-UART adapter 進入 ROM bootloader；
PaperFrame 應用程式則使用 native USB Serial/JTAG。實際 port 編號已省略，
重新插拔後必須重新辨識。

唯讀探測結果：

- ESP32-S3 QFN56 revision v0.2，40 MHz crystal。
- physical Flash 16 MB、quad I/O、3.3 V。
- embedded PSRAM 8 MB；韌體以 octal 80 MHz 初始化並通過 memory test。
- Secure Boot disabled、Flash Encryption disabled；未寫入 eFuse。

一般韌體與 factory filesystem 的寫入順序如下：

1. PlatformIO upload 寫入 bootloader `0x0`、partition table `0x8000`、
   OTA data `0xd000` 與 application `0x10000`，各區段 hash 驗證成功。
2. 明確執行 factory provisioning，將 1,048,576-byte `webfs.bin` 寫入
   `0x510000`，將 10,289,152-byte 空白 `imagefs.bin` 寫入 `0x630000`，
   兩區段 hash 驗證成功。
3. 後續一般 firmware upload 未重寫 `webfs` 或 `imagefs`。

首次監看 PaperFrame console 時，Flash 與 PSRAM self-test 通過，未設定的
感測器被略過，NVS schema 1 以 `use_current` 載入；`webfs` 與 `imagefs`
分別掛載成功。啟動 health server 前未初始化 lwIP，觸發
`tcpip_send_msg_wait_sem` 的 `Invalid mbox` assert。backtrace 定位到
`httpd_start`，修正為先呼叫 `esp_netif_init()`，失敗時 health server
降級停用而不是呼叫 socket API。修正版重新 build、upload 並完成板上測試。

RuntimeCoordinator embedded test 以獨立 test firmware 驗證 command/result
queue capacity、non-blocking overflow 與 snapshot publish/read，結果 1/1
通過；測試後已恢復一般韌體，未重寫兩個 filesystem。

### Phase 1 仍保留的 fault-injection 項目

- NVS 空白初始化的實機 log 尚未留存；schema 相同的 `use_current` 已觀察，
  空白、遷移與不支援版本由 host tests 覆蓋。
- NVS 初始化失敗時，韌體維持 degraded boot 且不自動擦除 partition。
- 任一 filesystem 缺失或損壞時不自動格式化，另一個仍可掛載且系統繼續 boot。

Runtime on-device tests 使用獨立 environment，避免不同 test app 共用
ESP-IDF CMake scaffold。Windows 上先完成 build，再重用同一 build graph
做 upload/test：

```powershell
.\.venv\Scripts\pio.exe test `
  --project-conf platformio-embedded.ini `
  -e paperframe-s3-embedded-test `
  --without-uploading --without-testing

.\.venv\Scripts\pio.exe test `
  --project-conf platformio-embedded.ini `
  -e paperframe-s3-embedded-test `
  --without-building
```

DisplayTask 實機測試使用另一個 environment，流程相同：

```powershell
.\.venv\Scripts\pio.exe test `
  --project-conf platformio-embedded.ini `
  -e paperframe-s3-display-test `
  --without-uploading --without-testing

.\.venv\Scripts\pio.exe test `
  --project-conf platformio-embedded.ini `
  -e paperframe-s3-display-test `
  --without-building
```

先完成韌體 build，再以相同 CMake build graph 產生尺寸與 partition table
一致的 factory images：

```powershell
.\.pio\packages\tool-cmake\bin\cmake.exe --build `
  .\.pio\build\paperframe-s3 `
  --target littlefs_webfs_bin littlefs_imagefs_bin
```

成功後會產生 `.pio\build\paperframe-s3\webfs.bin` 與
`.pio\build\paperframe-s3\imagefs.bin`。只有新機 factory provisioning 或
明確要清空兩個 filesystem 時，才可執行：

```powershell
.\.venv\Scripts\python.exe -m esptool --chip esp32s3 --port <COM> write-flash `
  0x510000 .pio\build\paperframe-s3\webfs.bin `
  0x630000 .pio\build\paperframe-s3\imagefs.bin
```

此命令會覆寫 `webfs`，並以空 image 覆寫 `imagefs`、清除所有使用者圖片；
一般 firmware upload／OTA 不得包含這兩個 image。

### Phase 2 G2/G3 決策

G2/G3 已由 [ADR-0003](../adr/0003-fix-phase2-display-integration.md) 固定：

- e-Paper 使用 3.3 V；DIN/CLK/CS/DC/RST/BUSY 分別為
  GPIO11/12/10/13/14/4。
- GPIO5 保留給 ADC、GPIO6 保留給 DHT、GPIO8/9 保留給 I²C SDA/SCL。
- GPIO33–37 不配置給任何周邊。
- `epd7in3e` 固定到 Waveshare upstream commit `06e8344`、MIT permission
  notice、六色 native mapping、active-low BUSY 與 60 秒 hard timeout。

這些是接線與實作 gate，不是面板已刷新成功的證據。仍待 Phase 2 driver
完成後執行六色 pattern、刷新時間、deep sleep 與 forced-BUSY 實機驗證。

### 2026-07-30 — Phase 2 panel-driver 驗證

- `pio test -e native` 通過全部 25 個 host test，其中 7 個覆蓋
  `epd7in3e` command trace、active-low BUSY、timeout、錯誤中止與 deep
  sleep 狀態。
- `pio run -e paperframe-s3` 成功，ESP-IDF adapter 已編入正式韌體。
- 六色直條 pattern 的 embedded test firmware 可成功建置。
- 當次連線辨識為 USB-to-UART adapter 與 ESP32-S3 native USB；adapter identifier
  與本機 port 已省略。
- CH343 自動 reset、手動 BOOT/RST 後的 no-reset UART 連線，以及 native
  USB no-reset 連線都未收到 ROM download response；最後分別回報
  `No serial data received` 與 `Write timeout`。
- OTA metadata read 也在 ROM handshake 前失敗，因此沒有讀取或改寫 flash，
  測試韌體未上傳，既有 app、NVS、webfs 與 imagefs 均未變更。

本次不能宣稱六色 mapping、實際刷新時間或 refresh 後 panel sleep 已在實機
通過。下一次硬體驗證必須先恢復可重現的 ROM download path，再上傳既有
embedded pattern test；forced-BUSY 仍只允許 fake 或隔離治具測試。

### 2026-07-30 — native USB ROM 與六色 pattern 實機通過

前一節的 ROM blocker 已用以下不同方法解決：

1. `GPIO0` 與 `GPIO46` 同時固定接到 `GND` 後按 `RST`。
2. USB-to-UART adapter 仍未輸出 ROM 資料；ESP32-S3 native USB port
   則明確輸出：

   ```text
   boot:0x0 (DOWNLOAD(USB/UART0))
   waiting for download
   ```

3. 關閉占用 native USB port 的 monitor 後，`esptool --before no-reset` 經 native
   USB 成功連線並讀取 OTA metadata。

OTA metadata 第一份 entry 為 sequence 1、state `VALID`，第二份 entry
全為 erased bytes，因此本次 active app 是 `ota_0`（`0x10000`，
`0x280000` bytes）。操作先完整備份 `ota_0`，再只把 218,944-byte
embedded pattern-test app 寫到 `0x10000`；未改寫 bootloader、partition
table、OTA metadata、NVS、webfs 或 imagefs。`esptool` 寫入後 hash 驗證
通過。

拔除 GPIO0/GPIO46 接地線並按 RST 後，使用者確認面板依序正確顯示六條
垂直色帶：黑、黃、紅、藍、綠、白。這完成 palette/nibble/SPI/panel
command 的端到端視覺驗證。當次 console monitor 在 USB 交接時斷線，未保留
Unity 尾端輸出，因此不把視覺結果延伸宣稱為 deep-sleep 電流已量測。

測試 app 執行後，native USB `--before usb-reset` 已可免接 straps 自動進
ROM。最後將測試前的完整 `ota_0` 備份原樣寫回，written data hash 驗證
通過並 hard reset；裝置已恢復測試前 app。可重現步驟見
[ESP32-S3 燒錄操作](FLASHING.md)。

### 2026-07-30 — PlatformIO native USB 單命令燒錄通過

專案將 PlatformIO esptool reset 設為 `usb_reset`，並以 post extra script
把 routine upload 限制為 app image。`envdump` 確認最終 uploader flags
沒有 bootloader、partition table 或 `ota_data_initial.bin`。

在 GPIO0/GPIO46 都未接地、native USB 與 CH343 同時存在的情況下，執行：

```powershell
.\.venv\Scripts\pio.exe run -e paperframe-s3 -t upload
```

PlatformIO 自動選到 native USB port，esptool
確認 `USB mode: USB-Serial/JTAG`，只擦除 `0x10000`–`0x69fff` 並寫入
365,632-byte app image。寫入後 data hash 驗證成功並自動 hard reset；
裝置重新枚舉為同一 native USB hardware ID。未改寫 bootloader、partition
table、OTA metadata、NVS、`webfs` 或 `imagefs`。

仍待驗證：

- 一般刷新時間的實測數值；
- refresh 後 panel sleep 的電流量測；
- forced-BUSY 隔離治具測試。

### 2026-07-30 — DisplayTask lifecycle 實機通過

Phase 2 DisplayTask 已整合為正式 app 的唯一 panel/SPI owner。Frame data
使用兩個 192,000-byte PSRAM slot 與 generation token；producer 提交後不再
持有可寫 lease，FreeRTOS queue 不保存 framebuffer pointer 或內容。

驗證結果：

- `pio test -e native`：36/36 通過；新增測試涵蓋 lease transfer、stale
  token、queue rollback、pool reset、BUSY/transport result mapping，以及
  display worker 阻塞時 health serialization 仍可完成。
- `test_runtime_coordinator` embedded test：1/1 通過；驗證 command queue
  overflow、queued/refreshing/failed snapshot transition 與共享
  flash/display gate。
- `test_display_task` embedded test：1/1 通過，總耗時 36.792 秒。提交呼叫
  在 100 ms gate 內返回；DisplayTask 對實際面板送出六色 full frame，最後
  result 為 `completed/refreshed_and_slept`，runtime snapshot 為
  `deep_sleep`。
- 測試 app 完成後執行標準單命令 upload。PlatformIO 自動選到 native USB
  port，只擦除 `0x10000`–`0x75fff`、寫入 414,960-byte 正式 app，
  data hash 驗證成功並 hard reset。bootloader、partition、OTA metadata、
  NVS、`webfs` 與 `imagefs` 均未改寫。

本次 `deep_sleep` 證據來自完整 command/result contract 與 driver state；
尚未以電流表量測面板 sleep 功耗。forced-BUSY 仍只在 fake driver 通過，
實機測試仍需隔離治具。

### 2026-07-30 — Phase 2 carousel welcome lifecycle 實機通過

輪播核心固定 30 分鐘預設、10 分鐘至 24 小時設定範圍，支援順序／隨機、新圖片
`shown_once` 優先、手動選擇保持完整週期，以及 invalid/disabled 圖片排除。
空圖庫只排入一次內建 welcome/status frame；完成後不週期性重刷相同畫面。
實際 catalog 與 PFR1 frame source 依計畫在 Phase 4–5 接入。

驗證結果：

- `pio test -e native`：50/50 通過，其中 14 個 carousel tests 使用 fake
  monotonic clock 覆蓋 interval、空圖庫、順序／隨機、新圖、手動、失敗
  退避、未提交重試、每次開機 welcome 與 stale decision；welcome frame
  幾何與無效 buffer 亦有 golden checks。
- `test_runtime_coordinator` embedded test：1/1 通過；除 queue/snapshot 外，
  驗證全域 request ID、接受命令前保留 terminal-result slot、容量耗盡時
  拒絕新命令，以及按 ID 完成／消費與釋放後恢復；較新的完成結果不會使
  較早的 carousel request 永久卡在 in-flight。
- ESP-IDF 6 啟用 `MINIMAL_BUILD`，只編譯 `main` 與明確相依元件，排除
  未使用的 RGB LCD driver；`pio run -e paperframe-s3` 成功，RAM
  27,148 bytes（8.3%），Flash 414,277 bytes（15.8%）。
- 標準單命令 upload 自動選到 native USB port，只擦除
  `0x10000`–`0x75fff` 並寫入 414,688-byte app；data hash 驗證成功並
  hard reset，未改寫其他 partition。
- 實機 console 回報
  `carousel_request=1 outcome=1 next_due_ms=1832147`；`outcome=1` 對應
  `refreshed_and_slept`，deadline 約為實際完成時間後 30 分鐘。

內建畫面預期為藍色外框、六色狀態條與黑色 `PF` 標記。console 與
DisplayTask lifecycle 已端到端通過；本次沒有以電流表量測 sleep 功耗，
也未把未接入 catalog 的真實圖片輪播誤記為實機通過。

### 2026-07-30 — Phase 3 provisioning AP state machine 實機通過

本段加入 `NetworkServiceTask` 與可在 host 驗證的 AP／STA 狀態機。
ESP-IDF Wi-Fi event callback 只投遞事件，STA/AP mode 切換、連線 timeout
及有限次 retry 都由 owner task 執行。Wi-Fi 與 Internet 狀態分開保存在
runtime snapshot；Internet 不可用不會把已連線 STA 切回 provisioning AP。

驗證結果：

- `pio test -e native`：59/59 通過，其中 9 個 network-state tests 覆蓋
  空白 credential、STA 成功、Internet unreachable、錯誤密碼等價的
  timeout/disconnect retry、次數耗盡 fallback AP、Recovery AP、AP action
  failure 有限重試、Wi-Fi 初始化失敗的明確 failed 狀態與無效 policy。
- `test_runtime_coordinator` embedded test：1/1 通過，包含
  `wifi=provisioning`／`internet=unknown` 的原子 snapshot update。
- `pio run -e paperframe-s3` 成功；RAM 52,384 bytes（16.0%），Flash
  897,589 bytes（34.2%）。
- native USB 單命令 upload 自動選到 port，只擦除
  `0x10000`–`0xebfff` 並寫入 898,000-byte app；data hash 驗證成功。
- 空白 credential 實機啟動 `PaperFrame-Setup-[masked]`，固定 IP
  `192.168.4.1`，DHCP server 成功啟動；log 未輸出 AP password 或任何
  STA credential。

第一次實機整合在 Wi-Fi 射頻啟動與電子紙 welcome 同時刷新時觸發
brownout。這項歷史競態目前以 AP presenter／carousel／presence blank 的
submission gate 序列化處理；AP page 在空圖片庫時持續接管面板，有圖片則
在 AP ready 後保留 5 分鐘再恢復圖片。重新燒錄後連續監看 30 秒未再重啟的
舊結果不等同於本次 AP grace policy 的實機驗證。
AP 專用引導畫面、portal、credential 儲存與 STA 成功路徑仍屬後續 Phase 3
commit，不在本段宣稱完成。Windows WLAN 掃描因系統 Location 權限關閉而
無法從主機列舉 SSID；AP 啟動證據來自 ESP-IDF mode、DHCP 與 service log。

### 2026-07-30 — Offline provisioning portal 部署與 STA smoke 通過

本段對應 Phase 3 的第二個 commit 邊界，只包含 AP 引導畫面、離線 portal、
Wi-Fi scan/config pipeline、credential commit lifecycle 與 bootstrap route
policy；不把尚未實作的管理 session、CSRF 或 Recovery AP login 宣稱完成。

驗證結果：

- `pio test -e native`：88/88 通過；包含隨機 AP password formatter、AP
  golden payload／QR escaping、credential codec 與 secret guard、表單解析、
  HTTP receive deadline、request/status lifecycle、bootstrap access policy、
  scan 去重／排序／過濾及既有 Phase 1–2 regression tests。
- `pio run -e paperframe-s3` clean build 成功；RAM 56,560 bytes（17.3%），
  Flash 934,649 bytes（35.7%）。新增 component dependency 後第一次 incremental
  build 沿用舊 CMake graph 而缺 include path；依已驗證修法 clean 後成功，
  不是 source compile failure。
- `littlefs_webfs_bin` 產生 1,048,576-byte `webfs.bin`，SHA-256
  `050AC7BAA87E46606A9EC0DD30C33C1AC204E6917C62A1A19B9D7CC57D0D509F`。
  只寫入 `0x510000`–`0x60ffff`，esptool data hash 驗證通過；未改寫
  `imagefs`、NVS、app 或 OTA metadata。
- 標準 PlatformIO 單命令 upload 自動選到 native USB port，只擦除
  `0x10000`–`0xf4fff` 並寫入 935,056-byte app；data hash 驗證通過並
  hard reset。
- 裝置保留既有 Wi-Fi credential 並成功進 STA；以遮蔽後的晶片 hardware
  ID 對應私有 DHCP 位址。實機
  `GET /api/v1/health` 回 `200`、`status=ready`、五個 service 都為
  `ready`、`wifi=connected`。
- 實機 `/`、`style.css`、`ui.js`、`favicon.svg` 均回 `200`，回傳大小分別
  3,529、7,013、6,637、326 bytes，與本次 `data/web` 完全一致。STA
  未登入的 scan GET 與虛構 config POST 均回 `401`、`Cache-Control:
  no-store`，config request 在 access check 即被拒絕，未改動 NVS。

本次沒有清除使用者既有 NVS 來強迫進首次 AP，因此最新 artifact 的
blank-NVS scan／credential save／約 1 秒 reboot 尚未做板上端到端驗證；
先前版本已驗證 AP screen 在 radio 前完成、AP/DHCP 可啟動。待 Phase 3
auth commit 可安全操作 Recovery AP 後，再補最新 artifact 的 AP scan、
登入、CSRF、credential save 與 STA reconnect 全流程。

### 2026-07-30 — Phase 3 auth／WebUI shell build 與安全啟動 smoke

本段記錄管理 session、CSRF route policy、共用 responsive shell、Dashboard
初版 API 與安全日誌修正的部署結果。WebUI 以獨立 `webfs` image 部署；一般
PlatformIO app upload 沒有重寫 `webfs`、`imagefs`、NVS 或 OTA metadata。

驗證結果：

- `pio test -e native`：105/105 通過；新增 dashboard serializer 與既有
  auth／CSRF、network、portal 及 Phase 1–2 regression tests 均納入同一次
  完整執行。
- `node --check data/web/ui.js` 通過；`pio run -e paperframe-s3` 成功，
  RAM 61,616 / 327,680 bytes（18.8%），Flash 約 960,733 /
  2,621,440 bytes（36.6%）。
- `littlefs_webfs_bin` 產生 1,048,576-byte image，SHA-256
  `A1B8F3A6881390812E263D8366E7A0D2547E25867E281AAE22AF3305BD0F5803`；
  以 `esptool` 只寫入 `0x510000`–`0x60ffff`，data hash 驗證通過。
- 以 PlatformIO native USB app-only upload 部署正式韌體；USB-Serial/JTAG
  連線、app hash 驗證與 hard reset 均成功。
- 隨後使用 RTS-only reset 讀取啟動日誌，確認：

  ```text
  rst:0x15 (USB_UART_CHIP_RESET),boot:0x8 (SPI_FAST_FLASH_BOOT)
  flash_bytes=16777216 expected=16777216 status=ready
  psram_initialized=true psram_bytes=8388608 expected=8388608 status=ready
  filesystem=webfs mounted=true total=1048576 used=53248
  filesystem=imagefs mounted=true total=10289152 used=8192
  health_server_ready route=/api/v1/health
  ```

- 同一段啟動輸出未出現 `QRCODE`、`WIFI:T`、AP password、SSID 或其他
  credential。這驗證了 `QRCODE` logger 降級修正；但不等同於瀏覽器登入或
  blank-NVS provisioning 流程已完成。

仍待驗證：

- 最新 artifact 在 blank-NVS／Recovery AP 的 scan、首次建密碼、login、
  401／CSRF、masked config 與 credential save／STA reconnect 全流程；
- Dashboard 在實機瀏覽器的 responsive／dark-mode 互動；
- SNTP 與 mDNS 狀態（目前 API 明確回傳 `unknown`／尚未整合）。

### 2026-07-30 — STA 管理 WebUI 與桌面版寬度驗證

本段在保留既有 Wi-Fi、`webfs`、`imagefs` 與其他 NVS 設定的前提下，
只重設管理帳號 `admin` 的密碼雜湊，並以正常 STA 模式驗證登入後的管理
介面。測試使用暫時密碼，測試結束後由使用者自行更換；密碼本身不寫入
原始碼、文件、log 或 Git。

驗證結果：

- 啟動後 health endpoint 回 `200`、`status=ready`；Flash、PSRAM、
  `webfs`、`imagefs` 與 Wi-Fi service 均為 ready/connected。原有網路設定
  未被清除，也沒有重建任何 filesystem。
- 實機登入成功。ESP32-S3 console 記錄
  `authentication_result=authenticated`，本次 PBKDF2 驗證約 136 秒，
  全程沒有 watchdog reset；因此 server-side login result 與 WebUI polling
  deadline 延長至 180 秒。
- 登入後 Dashboard 可載入 runtime snapshot，重新整理按鈕可完成一次
  refresh；Wi-Fi 頁在已連線 STA 模式可完成掃描並回傳去重後的結果。修正前
  非 provisioning mode 的 scan request 會停在 `scanning`，現已改為允許
  normal STA scan，其他不合法 mode 明確回報失敗。
- 桌面瀏覽器 viewport `1280` 下，頁面寬度 `1040`、sidebar `190`、
  authenticated content `822`，文件根節點 `scrollWidth` 小於 viewport，
  沒有水平溢出。未登入時隱藏 sidebar 會讓 content 跨滿 workspace，
  管理員登入卡片維持置中且不再被錯誤限制在第二欄。
- `image_02_05.png` 在本機檔案檢查為可解碼的 311×199 RGB PNG，未加入任何
  commit。Host image pipeline、quantizer、PFR1 packer 與 WebUI contract
  測試均通過；但本次 in-app browser 的 file chooser 只填入檔名、實際
  `FileList` 為空，畫面回報「無法讀取圖片」，所以不能把這次操作宣稱為
  瀏覽器端圖片成功處理。這是測試工具的檔案注入限制，需在可正常選檔的
  瀏覽器工作階段重跑圖片頁驗證。

仍待驗證：

- 最新 artifact 在 blank-NVS／Recovery AP 的 scan、首次建密碼、401／CSRF、
  masked config、credential save 與 STA reconnect 全流程；
- SNTP、mDNS、dark-mode 與可正常選檔的瀏覽器端 `image_02_05.png` PFR1
  產出／下載。

上面「Phase 5 imagefs transactional upload、catalog、斷電復原與圖片輪播」
一項已在後續 commit（`519b6c0`…`7ad7cbe`）完成程式與 host test，並在
`docs/archive/IMPLEMENTATION_PLAN.md` checkpoint 標記完成；本檔先前未同步更新，
硬體長時間輪播與斷電後行為仍列為後續 acceptance 待驗證項，不是「完全
未實作」。

### 2026-07-31 — Phase 6 WeatherWorker／狀態列渲染：僅完成 host 驗證

本段（見 `docs/adr/0005-weather-worker-and-status-bar.md`）新增
NetworkServiceTask 最小 SNTP 啟動、`pf_weather_worker`（2026-08 已併入
`pf_weather`，component 名稱僅為當時撰寫時的名稱）
HTTPS fetch、`RuntimeSnapshot` 天氣欄位、Dashboard 天氣 JSON，以及
`pf_display` 的 bitmap font／weather icon／狀態列 renderer，並接線進
carousel 與 welcome frame。全部變更通過 `pio run`（韌體完整編譯，RAM
158,848 / 327,680 bytes 48.5%，Flash 1,193,713 / 2,621,440 bytes
45.5%）與 `pio test -e native`（192/192），`test_runtime_coordinator`／
`test_display_task` embedded test 以 `--without-uploading
--without-testing` 完成 build-only 驗證。**本段沒有任何實機（開機、
Wi-Fi、面板）驗證**，以下項目仍完全待補：

- SNTP 實機同步：`esp_netif_sntp_init` 是否真的在 STA 連線後於合理時間
  內取得有效牆鐘時間，`RuntimeSnapshot.time_sync` 是否正確轉為
  `synced`。
- WeatherWorker HTTPS 四種診斷狀態：API key invalid（401）、DNS 解析
  失敗、TLS handshake 失敗（含 `esp_crt_bundle_attach` 對
  `api.openweathermap.org` 憑證的實際驗證）、逾時；目前只有
  `classify_http_status` 的純邏輯分類有 host test，實際
  `esp_http_client` 行為完全未在硬體上跑過。
- `NetworkService::report_internet_state` 觸發後，`internet` 狀態是否
  真的從永遠 `unknown` 開始正確反映 WeatherWorker 的抓取結果。
- 狀態列在真實面板上的視覺結果：3x5 點陣字型、9 種天氣圖示、
  stale marker 在 800×40／480×40 status bar 上的實際可讀性——目前只有
  golden-vector 像素比對，沒有人眼在面板上看過。
- Dashboard `weather` JSON 區塊在瀏覽器實際顯示。
- welcome frame 疊加狀態列後，原本的邊框／`PF` 標記是否仍清楚可辨（新
  邏輯會覆寫最上方 40 列）。

開發過程中在 host test 階段抓到一個 `draw_line`（Bresenham 演算法）的
符號計算錯誤，會在向上方向畫線時造成無窮迴圈（太陽圖示的向上射線觸發），
已修正並加上步數上限防呆；記錄於此供未來類似 pure-geometry 程式碼審查
參考。（2026-08：`draw_line`／`draw_cloud`／`fill_circle` 等程序化繪製
機制已被 ADR-0013 移除，天氣圖示改為轉檔點陣圖 blit，本段落的
Bresenham 死角不再適用於目前程式碼，僅保留作歷史記錄。）

### 2026-07-31 — Phase 7 DHT22／光敏在場偵測：僅完成 host 驗證

本段（見 `docs/adr/0006-sensor-drivers-and-presence.md`）新增
`pf_sensors` 純邏輯 component（`EnvironmentCache`／`DailyStats`／
`MovingAverageFilter`／`PresenceTracker`）、移植自 `UncleRus/esp-idf-lib`
（commit `162af418d4702791fd3bf3e5d1577aea9ec5539c`，BSD-3-Clause）的
`pf_dht22` driver、新的 `pf_sensor_task`（DHT22 讀取＋ADC 光敏取樣＋
presence debounce）——`pf_dht22`／`pf_sensor_task` 2026-08 已併入
`pf_sensors`，component 名稱僅為當時撰寫時的名稱——、`RuntimeSnapshot`
感測器欄位、Dashboard `sensors`
JSON、`GET /api/v1/sensors` 與 `/api/v1/sensors/config` 路由，以及
WebUI 環境頁。全部變更通過 `pio run`（韌體完整編譯，RAM
167,920 / 327,680 bytes 51.2%，Flash 1,213,025 / 2,621,440 bytes
46.3%）與 `pio test -e native`（225/225），`node --check data/web/ui.js`
通過。**本段沒有任何實機（DHT22、光敏電阻、實際 presence 轉換）驗證**，
以下項目仍完全待補：

- DHT22 實際讀值正確性：GPIO6 bit-bang 時序在真實 ESP32-S3 上是否穩定
  讀到有效溫濕度，`Dht22EnvironmentSensor` 對 `dht_read_float_data`
  各種失敗回傳（timeout、checksum mismatch、感測器未接）轉換出的
  `SensorStatus` 是否符合預期；目前只有 fake adapter 的介面契約有
  host test。
- 光敏電阻 ADC 實測：GPIO5／`ADC1_CH4` 在真實環境光下的原始讀值範圍、
  `MovingAverageFilter` 平滑後的數值是否適合作為 threshold 校正基準；
  預設 `light_threshold=2000` 未經實機校正。
- AWAY／PRESENT 實機轉換：真的遮蔽／露出光敏電阻後，`PresenceTracker`
  是否在設定的 `away_duration_s`（預設 180）／`return_duration_s`
  （預設 30）後正確切換狀態；saturated／error 讀值是否確實不觸發離席。
- 離席全白刷新與 sleep：`render_blank_frame` 送到面板後的實際視覺結果、
  刷新後 panel sleep 的電流量測。
- 返回後重繪與 deadline 重設：`CarouselScheduler::force_immediate` 觸發
  的下一輪 `poll()` 是否真的在返回後立即重繪目前圖片，而不是延用離席前
  殘留的 30 分鐘 deadline。
### 2026-07-31 — Phase 7 開機不斷重複重開機：main task stack 二次調大

前一版修復（`49263cc`）已將 `CONFIG_ESP_MAIN_TASK_STACK_SIZE` 從 ESP-IDF
預設 3584 調到 8192，並在實機確認解決了 `pf_storage::mount_all()` 附近
的 `InstrFetchProhibited` guru meditation。但實機重新開機驗證時，8192
仍不足，改為在 STA Wi-Fi 初始化之後崩潰，backtrace 落在
`vfs_littlefs_unlink` 附近，同樣是 main task stack overflow 的訊號
（Phase 7 新增的 sensor task 設定路徑在 `app_main` 上又多用了一些
stack）。本次調整：

- `CONFIG_ESP_MAIN_TASK_STACK_SIZE` 8192 → 16384。
- 新增 `CONFIG_FREERTOS_WATCHPOINT_END_OF_STACK=y`，往後若再次逼近
  stack 上限會直接以 watchpoint 觸發明確的 stack overflow panic，而不是
  overflow 覆寫回傳位址後跳到隨機指令位置（更難判讀的
  `InstrFetchProhibited`）。

實機重新開機測試已確認：開機不再重複重開機，流程可正常跑完
config／filesystem／runtime／netif／health server 啟動序列。

未待驗證項：16384 是否對 Phase 8（OTA、diagnostics）之後可能新增的
task 仍有餘裕；後續每次大幅擴充 `app_main` 起始序列（新增 task、大型
stack-allocated 結構）應重新檢查 high-water mark，不要只靠「這次夠用」
延伸判斷。

- WebUI 環境頁在瀏覽器的實際顯示與表單保存流程（`environment-form`
  submit → `POST /api/v1/sensors/config` → 重新載入）。
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

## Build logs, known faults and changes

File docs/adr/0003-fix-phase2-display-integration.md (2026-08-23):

# ADR-0003：固定 Phase 2 顯示器接線與 driver contract

- Status: accepted（部分被取代）
- Date: 2026-07-29
- Superseded in part by: [ADR-0019](0019-separate-frame-displayed-from-panel-slept.md)——Verification 的「成功 result 只能在 driver 回報 deep sleep 後發布」
  已被取代：driver 現在同時回報「畫面是否已上到面板」，刷新完成但 sleep
  失敗不再讀作刷新失敗。本 ADR 的 driver 行為（sequence、BUSY timeout
  處理、`0x07, 0xA5` 才標記 deep sleep）維持有效。
- Supersedes: none
- Amended by: [ADR-0018](0018-dual-photoresistor-channels.md)（G2 感測器
  保留腳位表新增 GPIO7／`ADC1_CH6` 作為第二個光敏電阻通道；本 ADR 其餘
  內容不變，GPIO4 仍不得作為 light-sensor ADC）

## Context

目標硬體是 Waveshare 7.3 吋 e-Paper HAT (E)，解析度 800×480，以 SPI
傳送 E6 全彩資料。開發板使用 ESP32-S3-N16R8；其 octal PSRAM 會占用
GPIO33–37，native USB 使用 GPIO19–20，GPIO0、GPIO3、GPIO45、GPIO46
則是 strapping pins。

使用者已依實體接線確認 e-Paper 訊號。感測器尚未安裝，但 G2 要求在
Phase 2 開始前保留 ADC、DHT 與 I²C GPIO，避免後續改動顯示器接線。

G3 的行為基線取自 Waveshare 官方 `waveshare/e-Paper` repository。官方
來源檔 header 把產品描述寫成 7.3inch e-Paper (F)，但檔名、symbol 與
Waveshare HAT (E) manual 使用的 demo target 都是 `epd7in3e`；本專案把
該描述視為 upstream 文件 typo，不把它解讀為另一個 driver。

## Decision

### G2 pin map

HAT 與 ESP32-S3 全部使用 3.3 V logic：

| HAT 訊號 | ESP32-S3 | 方向／用途 |
| --- | --- | --- |
| VCC | 3V3 | 電源 |
| GND | GND | 共地 |
| DIN | GPIO11 | SPI2 MOSI |
| CLK | GPIO12 | SPI2 SCK |
| CS | GPIO10 | SPI chip select，低有效 |
| DC | GPIO13 | data／command |
| RST | GPIO14 | panel reset，低有效 |
| BUSY | GPIO4 | panel status input，低電位為 busy |

感測器保留腳位如下；在 Phase 7 前不初始化，也不因浮動輸入改變 runtime
狀態：

| 用途 | ESP32-S3 |
| --- | --- |
| 光敏電阻 ADC | GPIO5 (`ADC1_CH4`) |
| DHT data | GPIO6 |
| I²C SDA | GPIO8 |
| I²C SCL | GPIO9 |

GPIO0、GPIO3、GPIO19、GPIO20、GPIO26–37、GPIO43–46 不分配給上述周邊。
GPIO4 已分配給 BUSY，不得再作為 light-sensor ADC。

### G3 driver contract

- Upstream：`https://github.com/waveshare/e-Paper`
- 固定 repository commit：`06e834491bf62023a1b86a481b4530978883d2c4`
- 行為來源：
  - `RaspberryPi_JetsonNano/c/lib/e-Paper/EPD_7in3e.c`
    (`SHA-256 010E08A7053219076E707EBE2210BEF7C38ABB11EB8F975418F451EA8D9D895C`)
  - `RaspberryPi_JetsonNano/c/lib/e-Paper/EPD_7in3e.h`
    (`SHA-256 D454685677EAC06CEEA24F9E64BE05782491E41491050C7A7B78186AEF73BD66`)
  - `RaspberryPi_JetsonNano/python/lib/waveshare_epd/epd7in3e.py`
    (`SHA-256 7E12ECECFF0A75C84EEB32B2A324B3CECA49D08E1A108175A467C8417BD64572`)
- Upstream driver 使用 MIT permission notice。ESP-IDF port 若複製或大幅改作
  command sequence，必須保留 Waveshare attribution 與 permission notice。
- Palette v1 只接受六個 native nibble：

| 色彩 | nibble |
| --- | --- |
| black | `0x0` |
| white | `0x1` |
| yellow | `0x2` |
| red | `0x3` |
| blue | `0x5` |
| green | `0x6` |

`0x4` 不屬於 palette v1，不得沿用 upstream quantizer 把它默默映射為黑色。
每個 byte 的高 nibble 是偶數 x pixel，低 nibble 是下一個奇數 x pixel。

ESP-IDF transport 固定使用 SPI2、mode 0、MSB-first 與 2 MHz 起始 clock。
2 MHz 是在 upstream 各平台設定不一致時採取的保守初始值；只有實機波形與
刷新驗證通過後才能另行提高。GPIO10 由 SPI master hardware CS 控制，每個
command 是一筆 1-byte transaction；同一 register 的 data bytes 合併為一筆
transaction。192,000-byte framebuffer 分成 4,096-byte transactions，最後
一筆 3,584 bytes，共 47 筆；各筆之間 CS 會 deassert。

Driver 只接受非 null、恰好 192,000 bytes 的 native full frame，且必須在
任何 reset、SPI 或 panel command 前拒絕錯誤大小。呼叫為同步借用：return
前 caller 不得修改 buffer，也不得進行會關閉 flash cache 的寫入；return
後 driver 不保留 pointer。ESP-IDF adapter 先把每個 chunk 複製到 4 KiB
internal DMA-capable bounce buffer，再啟動 polling transaction，因此不要求
PSRAM source 本身具備 DMA alignment。後續 DisplayTask／StorageWorker 仍須
序列化 framebuffer 讀取與 flash 寫入。

DisplayTask 使用兩個 192,000-byte PSRAM slot。Producer 只能在
`FrameWriteLease` 有效時取得 mutable pointer；提交後 queue 僅攜帶
`{slot, generation}` token，write lease 立即失效。DisplayTask 驗證 token
並把 slot 從 queued 轉為 displaying 後，才取得 read lease 傳給 driver；
driver return 後 slot 才能回到 free 並遞增 generation。queue 滿時提交立即
失敗並恢復原 write lease，不等待、不觸碰面板，也不隱式合併或覆蓋 request。
因此舊 token、double submit 與 producer 在 refresh 期間重用同一 slot 都會
被拒絕。

DisplayTask 是 ESP-IDF transport 與 driver 的唯一建構者。它在 driver
lifecycle 外層取得 RuntimeCoordinator 的單一 flash/display gate，return
後釋放；未來 StorageWorker 的 imagefs、catalog 與 OTA flash write 必須使用
同一 gate。frame-pool state transition 不在持有 gate 時等待，避免形成反向
lock order。HTTP handler 不取得此 gate，只讀 immutable runtime snapshot。
Snapshot 分開記錄目前 active request 與 queued count；刷新中再排入下一張
不得把 `refreshing` 回退成 `queued`，目前 command 完成且 queue 仍有資料時
才轉為 `queued`。

BUSY 低電位表示 busy，高電位表示 idle。每個單獨 BUSY wait 的 hard
timeout 為 60 秒；整筆 display command 會包含多次 wait，end-to-end
上限不宣稱為 60 秒。逾時後不在同一 command 內重試或繼續送 panel
command；driver deassert CS、釋放 SPI transaction，回報 `busy_timeout`，
並把 panel sleep 狀態標為 unknown。下一個 display command 必須從
hardware reset 與完整 initialization 重新開始。

每次 `refresh_and_sleep()` 不論前一狀態是 cold、成功 deep sleep 或
unknown，都從 reset high 20 ms、low 2 ms、high 20 ms、BUSY wait 與
30 ms delay 開始，再送完整 upstream register initialization：
`AA/01/00/03/05/06/08/30/50/60/61/84/E3`，接著 `POWER_ON (0x04)` 與
BUSY wait。之後送 `DATA_START (0x10)` 與 47 筆 framebuffer transaction，
再依 C driver 的 refresh sequence 送：

1. `POWER_ON (0x04)`，BUSY wait。
2. 第二組 `0x06` 參數 `6F 1F 17 49`。
3. `DISPLAY_REFRESH (0x12), 0x00`，BUSY wait。
4. `POWER_OFF (0x02), 0x00`，BUSY wait。
5. sleep sequence 再送一次 `POWER_OFF (0x02), 0x00`，BUSY wait。
6. `DEEP_SLEEP (0x07), 0xA5`。

第二次 power-off 暫不省略，除非後續另有實機證據與 ADR 取代本決策；
單獨的 `POWER_OFF` 不視為已進入 deep sleep。任一 transport error 或
BUSY timeout 都立即停止後續 sequence、把 state 設為 unknown；只有完整
送出 `0x07, 0xA5` 才標記 deep sleep。

## Consequences

- Phase 2 可在感測器未安裝時開始，且不會占用其保留 GPIO。
- Packed framebuffer primitive 不配置 PSRAM；它只操作 caller 提供的
  buffer；DisplayTask 的兩個 lease-managed full-frame slot 配置於 PSRAM。
- Driver adapter 固定使用 4 KiB internal DMA bounce buffer；不直接把
  caller 的 PSRAM pointer 交給 SPI DMA。
- slot `0x4` 或其他保留 nibble 必須在 encoder／upload 驗證時被拒絕。
- 單一 stuck BUSY wait 最長會阻塞 DisplayTask 60 秒；整筆 command 可能
  包含多次成功 wait，不在本 ADR 保證 end-to-end 60 秒上限。HTTP handler
  不得因此阻塞；command/result queue、獨立 worker 與 runtime snapshot
  已由 DisplayTask host/embedded tests 驗證。
- 沒有 PWR control pin；BUSY timeout 時無法宣稱 panel 已 sleep。

## Verification

- Host golden tests 驗證 palette、nibble 順序、buffer 尺寸、邊界 pixel 與
  非法輸入不改寫 buffer。
- Driver fake test 必須驗證 active-low BUSY、60 秒 timeout、成功 deep sleep
  與 timeout 後不再送 command。
- DisplayTask host tests 驗證 lease transfer、stale generation、queue
  rollback、result mapping，以及 blocked worker 不阻塞 health serialization。
- Embedded tests 驗證 queue/snapshot/gate 狀態與實際面板 lifecycle；成功
  result 只能在 driver 回報 deep sleep 後發布。
- 實機 pattern test 依六色區塊確認 mapping，再量測一般刷新時間。
- forced-BUSY 預設只在 fake driver 執行。實機測試僅能使用隔離治具，或
  先斷開 HAT BUSY output 並驗證不會發生 output contention；HAT 仍連接時
  不得把 ESP32 GPIO4 改為 output 強拉。未完成前保留為 Phase 2 hardware
  risk。

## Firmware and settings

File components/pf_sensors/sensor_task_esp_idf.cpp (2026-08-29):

#include "pf_sensors/sensor_task.hpp"

#include <ctime>

#include "driver/gpio.h"
#include "esp_log.h"
#include "esp_timer.h"
#include "pf_config/config_manager.hpp"
#include "pf_runtime/runtime_coordinator.hpp"

namespace pf_sensors {
namespace {

constexpr char kTag[] = "pf_sensors";
// ADR-0003: DHT22 data = GPIO6, photoresistor channel 1 = GPIO5
// (ADC1_CH4). ADR-0018 adds channel 2 = GPIO7 (ADC1_CH6). Both channels
// are on ADC1 because ADC2 is claimed by the Wi-Fi driver and reads back
// ESP_ERR_TIMEOUT while the radio is up.
//
// Must stay in step with pf_sensors::kLightChannelGpios (light_sensor.hpp),
// which is what the API reports: these are two views of the same pins
// (GPIO5 = ADC1_CH4, GPIO7 = ADC1_CH6). Moving a channel means changing both.
constexpr adc_channel_t kLightAdcChannels[kLightChannelCount] = {
    ADC_CHANNEL_4,
    ADC_CHANNEL_6,
};
constexpr gpio_num_t kDhtPin = GPIO_NUM_6;

}  // namespace

SensorTask::SensorTask() : environment_sensor_(kDhtPin)
{
}

esp_err_t SensorTask::start(pf_runtime::RuntimeCoordinator& runtime)
{
    if (task_handle_ != nullptr) {
        return ESP_ERR_INVALID_STATE;
    }
    runtime_ = &runtime;

    const adc_oneshot_unit_init_cfg_t init_config{
        .unit_id = ADC_UNIT_1,
        .clk_src = static_cast<adc_oneshot_clk_src_t>(0),
        .ulp_mode = ADC_ULP_MODE_DISABLE,
    };
    esp_err_t result = adc_oneshot_new_unit(&init_config, &adc_handle_);
    if (result != ESP_OK) {
        ESP_LOGE(
            kTag,
            "adc_unit_init_failed=%s; light sensing disabled",
            esp_err_to_name(result));
        adc_handle_ = nullptr;
    } else {
        const adc_oneshot_chan_cfg_t channel_config{
            .atten = ADC_ATTEN_DB_12,
            .bitwidth = ADC_BITWIDTH_DEFAULT,
        };
        // A channel that fails to configure is left not-ready on its own;
        // the other one keeps working, matching the rule that sensors are
        // optional and degrade individually.
        for (std::size_t index = 0U; index < kLightChannelCount; ++index) {
            const esp_err_t channel_result = adc_oneshot_config_channel(
                adc_handle_, kLightAdcChannels[index], &channel_config);
            light_channel_ready_[index] = channel_result == ESP_OK;
            if (channel_result != ESP_OK) {
                ESP_LOGE(
                    kTag,
                    "adc_channel_config_failed=%s channel=%u; "
                    "light channel disabled",
                    esp_err_to_name(channel_result),
                    static_cast<unsigned>(index + 1U));
            }
        }
    }

    task_handle_ = xTaskCreateStatic(
        &SensorTask::task_entry,
        "SensorTask",
        kTaskStackWords,
        this,
        kTaskPriority,
        task_stack_,
        &task_control_);
    if (task_handle_ == nullptr) {
        if (adc_handle_ != nullptr) {
            adc_oneshot_del_unit(adc_handle_);
            adc_handle_ = nullptr;
        }
        runtime_ = nullptr;
        return ESP_ERR_NO_MEM;
    }
    return ESP_OK;
}

void SensorTask::task_entry(void* const context)
{
    static_cast<SensorTask*>(context)->task_main();
}

std::uint64_t SensorTask::now_ms_since_boot()
{
    return static_cast<std::uint64_t>(esp_timer_get_time() / 1000);
}

void SensorTask::task_main()
{
    while (true) {
        const pf_config::SensorSettingsLoadResult settings_result =
            pf_config::load_sensor_settings();
        const pf_config::SensorSettings settings =
            settings_result.error == ESP_OK ? settings_result.settings
                                             : pf_config::SensorSettings{};

        sample_light(settings);
        sample_environment(settings);

        vTaskDelay(kLoopIntervalTicks);
    }
}

void SensorTask::sample_light(const pf_config::SensorSettings& settings)
{
    const bool channel_enabled[kLightChannelCount] = {
        settings.light1_enabled,
        settings.light2_enabled,
    };
    const std::uint16_t channel_threshold[kLightChannelCount] = {
        settings.light1_threshold,
        settings.light2_threshold,
    };
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

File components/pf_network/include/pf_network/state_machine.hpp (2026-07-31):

#pragma once

#include <cstdint>

namespace pf_network {

enum class NetworkMode : std::uint8_t {
    boot,
    connecting_wifi,
    normal,
    provisioning_ap,
    offline_retry,
};

constexpr bool scan_allowed_in_mode(const NetworkMode mode)
{
    return mode == NetworkMode::normal ||
           mode == NetworkMode::provisioning_ap;
}

enum class WifiState : std::uint8_t {
    unknown,
    connecting,
    connected,
    starting_ap,
    provisioning,
    failed,
};

enum class InternetState : std::uint8_t {
    unknown,
    reachable,
    unreachable,
};

enum class NetworkEvent : std::uint8_t {
    sta_got_ip,
    sta_disconnected,
    sta_connect_timeout,
    internet_reachable,
    internet_unreachable,
    enter_recovery_ap,
    ap_started,
    ap_start_failed,
    wifi_initialize_failed,
    scan_requested,
    sntp_time_synced,
};

enum class NetworkAction : std::uint8_t {
    none,
    start_sta,
    retry_sta,
    start_ap,
};

struct NetworkPolicy {
    std::uint8_t maximum_sta_attempts = 3U;
    std::uint8_t maximum_ap_attempts = 3U;
};

class NetworkStateMachine {
public:
    NetworkStateMachine() = default;

    explicit NetworkStateMachine(const NetworkPolicy policy)
        : maximum_sta_attempts_(
              policy.maximum_sta_attempts == 0U
                  ? 1U
                  : policy.maximum_sta_attempts),
          maximum_ap_attempts_(
              policy.maximum_ap_attempts == 0U
                  ? 1U
                  : policy.maximum_ap_attempts)
    {
    }

    NetworkAction start(const bool credentials_configured)
    {
        internet_state_ = InternetState::unknown;
        if (!credentials_configured) {
            prepare_ap();
            return NetworkAction::start_ap;
        }

        mode_ = NetworkMode::connecting_wifi;
        wifi_state_ = WifiState::connecting;
        sta_attempt_ = 1U;
        return NetworkAction::start_sta;
    }

    NetworkAction handle(const NetworkEvent event)
    {
        if (event == NetworkEvent::wifi_initialize_failed) {
            enter_failed();
            return NetworkAction::none;
        }
        if (event == NetworkEvent::enter_recovery_ap) {
            prepare_ap();
            return NetworkAction::start_ap;
        }
        if (event == NetworkEvent::ap_started &&
            mode_ == NetworkMode::provisioning_ap &&
            wifi_state_ == WifiState::starting_ap) {
            wifi_state_ = WifiState::provisioning;
            ap_attempt_ = 0U;
            return NetworkAction::none;
        }
        if (event == NetworkEvent::ap_start_failed &&
            mode_ == NetworkMode::provisioning_ap &&
            wifi_state_ == WifiState::starting_ap) {
            if (ap_attempt_ < maximum_ap_attempts_) {
                ++ap_attempt_;
                return NetworkAction::start_ap;
            }
            enter_failed();
            return NetworkAction::none;
        }

        if (event == NetworkEvent::internet_reachable) {
            if (wifi_state_ == WifiState::connected) {
                internet_state_ = InternetState::reachable;
            }
            return NetworkAction::none;
        }
        if (event == NetworkEvent::internet_unreachable) {
            if (wifi_state_ == WifiState::connected) {
                internet_state_ = InternetState::unreachable;
            }
            return NetworkAction::none;
        }

        if (event == NetworkEvent::sta_got_ip &&
            (mode_ == NetworkMode::connecting_wifi ||
             mode_ == NetworkMode::offline_retry)) {
            mode_ = NetworkMode::normal;
            wifi_state_ = WifiState::connected;
            internet_state_ = InternetState::unknown;
            sta_attempt_ = 0U;
            return NetworkAction::none;
        }

        if ((event == NetworkEvent::sta_disconnected ||
             event == NetworkEvent::sta_connect_timeout) &&
            (mode_ == NetworkMode::connecting_wifi ||
             mode_ == NetworkMode::normal ||
             mode_ == NetworkMode::offline_retry)) {
            internet_state_ = InternetState::unknown;
            wifi_state_ = WifiState::connecting;
            mode_ = NetworkMode::offline_retry;
            if (sta_attempt_ == 0U) {
                sta_attempt_ = 1U;
            }
            if (sta_attempt_ < maximum_sta_attempts_) {
                ++sta_attempt_;
                return NetworkAction::retry_sta;
            }
            prepare_ap();
            return NetworkAction::start_ap;
        }

        return NetworkAction::none;
    }

    NetworkMode mode() const
    {
        return mode_;
    }

    WifiState wifi_state() const
    {
        return wifi_state_;
    }

    InternetState internet_state() const
    {
        return internet_state_;
    }

    std::uint8_t sta_attempt() const
    {
        return sta_attempt_;
    }

    std::uint8_t maximum_sta_attempts() const
    {
        return maximum_sta_attempts_;
    }

    std::uint8_t ap_attempt() const
    {
        return ap_attempt_;
    }

    std::uint8_t maximum_ap_attempts() const
    {
        return maximum_ap_attempts_;
    }

private:
    void prepare_ap()
    {
        mode_ = NetworkMode::provisioning_ap;
        wifi_state_ = WifiState::starting_ap;
        internet_state_ = InternetState::unknown;
        sta_attempt_ = 0U;
        ap_attempt_ = 1U;
    }

    void enter_failed()
    {
        mode_ = NetworkMode::boot;
        wifi_state_ = WifiState::failed;
        internet_state_ = InternetState::unknown;
        sta_attempt_ = 0U;
        ap_attempt_ = 0U;
    }

    NetworkMode mode_ = NetworkMode::boot;
    WifiState wifi_state_ = WifiState::unknown;
    InternetState internet_state_ = InternetState::unknown;
    std::uint8_t sta_attempt_ = 0U;
    std::uint8_t maximum_sta_attempts_ = 3U;
    std::uint8_t ap_attempt_ = 0U;
    std::uint8_t maximum_ap_attempts_ = 3U;
};

}  // namespace pf_network

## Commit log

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2026-07-30 fix(network): complete authenticated wifi scans
    [state_machine.hpp]
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2026-07-30 fix(web): guard weather config access and bound masked text fields
    Serialize weather_settings reads/writes in config_handler and
    process_weather_config behind a static mutex to close a race between
    concurrent config requests, and make serialize_masked_config's safe_text
    check honor each field's declared capacity so an unterminated buffer
    cannot be read past its bound.
2026-07-31 feat(weather): fetch OpenWeatherMap over HTTPS and render it in the status bar
    Bring up the rest of Phase 6 per ADR 0005: NetworkServiceTask starts SNTP
    after STA connects and tracks sync state; the new pf_weather_worker
    component fetches current weather over HTTPS (esp_http_client +
    esp_crt_bundle_attach), classifies failures, and reports internet
    reachability back to NetworkService; RuntimeSnapshot/RuntimeCoordinator
    carry the resulting cache and time-sync state; the dashboard exposes a
    three-state (available/stale/unavailable) weather block; and pf_display
    gains a self-authored bitmap font, procedural weather icons, and a
    status-bar renderer wired into both the image carousel and the welc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
2026-07-31 docs: sync Phase 6 progress and hardware validation gaps
    Record the WeatherWorker/status-bar implementation in the checkpoint,
    correct a stale note that had left Phase 5 marked unfinished after it
    actually shipped, and list the Phase 6 items that still need on-device
    verification (SNTP sync, the four HTTPS failure diagnostics, TLS cert
    validation, and how the status bar actually looks on the panel).
2026-07-31 docs(adr): record sensor driver provenance and presence decisions for phase 7
    Fixes the DHT22 driver source (UncleRus/esp-idf-lib, BSD-3-Clause),
    read frequency/backoff, light-filter choice, presence debounce
    mechanism, CarouselScheduler gap resolution, and the GET
    /api/v1/sensors schema before implementation begins.
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2026-07-31 fix(build): increase main task stack to fix Phase 7 boot crash
    app_main() is one flat function carrying substantial local state; the
    3584-byte ESP-IDF default overflowed once Phase 7 added a few more
    locals, corrupting the return address into pf_storage::mount_all()
    (Guru Meditation InstrFetchProhibited). Confirmed on real hardware
    2026-07-31: the device crashed on every boot before this fix, and
    boots cleanly through filesystem mount, display task, and health
    server startup after it.
2026-07-31 fix(build): increase main task stack again to stop boot-loop crash
    8192 (from 49263cc) still overflowed once STA Wi-Fi init and Phase 7
    sensor task setup ran, crashing near vfs_littlefs_unlink and causing a
    repeated reboot loop on real hardware. Bump to 16384 and enable
    CONFIG_FREERTOS_WATCHPOINT_END_OF_STACK so future overflows panic with
    a clear message instead of corrupting the return address. Confirmed on
    real hardware: device boots cleanly through the full startup sequence
    without looping.
2026-07-31 fix(auth): simplify login to synchronous and consolidate pf_network
    PBKDF2 at 600,000 iterations took ~136s on real ESP32-S3 hardware,
    which forced an entire async job-queue architecture (AuthTask, two
    mutexes, a request-token bearer protocol, a status-poll endpoint, and
    a 180s client poll loop) just to keep the HTTP handler from blocking.
    That machinery also caused a real bug: a 409 (busy, another login/
    setup in flight) and a 401 (wrong password) rendered as the identical
    "login failed" message, making first-time admin setup impossible to
    diagnose.
    For this device's home-LAN threat model (see docs/adr/0007), lower
    the default to 10,000 iterations (~2-3s, within the existing schema
    bound,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
2026-07-31 fix(auth): stop first-time password creation blocking on the display lock
    Real hardware test of first-time admin password setup (the very path
    that had never been exercised on device before) hung for well over a
    minute before failing. perform_login()'s password-creation branch
    calls runtime_->lock_flash_display(...), which DisplayTask holds for
    the entire duration of an e-paper panel refresh. That call used to run
    on the dedicated AuthTask, where blocking was harmless; now that
    login() runs synchronously on the HTTP handler's own task, it blocked
    the request for as long as a refresh was in flight, violating the
    project's rule that HTTP handlers must never wait on panel refresh.
    Fix it non-b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
2026-07-31 fix(auth): size the HTTP server task stack for synchronous PBKDF2
    Real hardware retest after the flash_display-lock fix hit a second,
    separate crash: Guru Meditation "Stack canary watchpoint triggered".
    start_health_server() left esp_http_server's stack_size at the
    ESP-IDF default (4096 bytes). PBKDF2/PSA crypto in perform_login()
    used to run on a dedicated AuthTask sized at 4096 words (16384 bytes)
    for exactly this workload; now that login() runs synchronously on the
    httpd worker task, the default stack overflows during password
    hashing. Size it to 24576 bytes -- above the old AuthTask budget,
    since this task also carries esp_http_server's own request-parsing
    and routing frames on top (per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
2026-07-31 fix(storage): move Catalog off task stack and avoid abort on OOM
    The image download/upload/mutation HTTP tasks were copying Catalog
    (~6.2 KB, kCatalogMaxEntries=48 entries) directly onto their own
    task stack, which overflowed the original 4096/8192-byte stacks.
    Allocate it on the heap instead via a nothrow new + explicit null
    check: C++ exceptions are disabled for this target
    (CONFIG_COMPILER_CXX_EXCEPTIONS=n), so a plain std::make_unique
    would abort() the whole device on allocation failure rather than
    returning ImageStoreError::not_ready.
    With Catalog off the stack, right-size the three task stacks to
    8192 bytes (down from a since-abandoned 32768 bytes tried during
    development) to give WiF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
2026-07-31 fix(web): drain upload bodies and fix keep-alive session lifecycle
    Give image uploads their own generous receive/idle budget (60 s / 12
    timeouts) separate from the other small-body handlers, since a
    ~182 KB upload in 1024-byte chunks can stall for multiple seconds per
    chunk during LittleFS garbage collection. When store_image() stops
    early with bytes still unread, drain them before deciding whether to
    close the session, instead of always closing.
    Also stop leaving the connection open when image_upload_handler
    rejects a request before any of its body has been read (auth/CSRF
    failure, oversized/invalid content length, storage not ready or
    busy, upload queue full): leaving those sessions open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
2026-07-31 feat(web): lazy-load image processing scripts on demand
    Split image_pipeline.js, image_quantizer.js, image_pfr1.js, and
    image_quantize_worker.js out as separate static assets served from
    new /image_*.js routes, and only fetch each one from ui.js the first
    time a decode/process step actually needs it, instead of shipping
    all of it inline with the base page. Widen max_uri_handlers (26->32)
    and the socket/handler-list capacity to fit the new routes.
    Also add a three-tier decode fallback (createImageBitmap without
    orientation, createImageBitmap with default handling, then a plain
    Image element) and surface specific, actionable error messages for
    each known failure mode instead of one generic "u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
2026-07-31 fix(web): restore upload/mutation task stacks after on-device overflow
    8192 bytes was not enough for the image upload task after all:
    real hardware hit a clean FreeRTOS stack-canary panic
    ("Stack canary watchpoint triggered (pf_image_up)") during an
    upload, since store_image_transactionally/persist_catalog_
    transactionally run PFR1 validation and a CRC32 pass over the
    serialized catalog on top of whatever esp_http_server/LittleFS
    already put on that stack. Restore upload and mutation (which shares
    the same catalog-CRC call path) to the known-working 32768 bytes;
    leave download at 8192 since it doesn't touch catalog serialization.
    Log uxTaskGetStackHighWaterMark() after each request on all t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
2026-07-31 fix(web): use 16384-byte upload/mutation stacks as an interim value
    32768 bytes each stopped the stack-canary overflow but reserves so
    much internal SRAM for the lifetime of these xTaskCreateStatic tasks
    that it starved ordinary WebUI connections instead: httpd send()
    started failing with EAGAIN on a plain page load, no upload in
    progress. 16384 is a middle ground (2x the 8192 value confirmed to
    overflow) pending real numbers from the uxTaskGetStackHighWaterMark()
    logging added in the previous commit.
2026-07-31 fix(web): right-size upload/mutation stacks from measured high-water marks
    On-device uxTaskGetStackHighWaterMark() logging at 16384 bytes each
    showed upload using ~9520 bytes (6864 free, healthy) but mutation
    using ~14288 bytes (only 2096 free) -- as tight as the 8192-byte
    configuration that previously overflowed. Keep upload at 16384 and
    raise mutation to 24576 for comparable headroom (~10 KB free).
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2026-08-01 feat(runtime): add diagnostics ring buffer and Phase 8 snapshot fields
    Add a bounded diagnostics ring buffer (queue/lock failure counters,
    reboot reason, OTA and carousel status) to RuntimeCoordinator so
    Phase 8's admin surfaces have something real to read instead of
    placeholder nulls. Counter increments and their diagnostic event are
    published under a single critical section so they can never be
    observed as two separate snapshot changes.
    schedule_reboot() creates its one-shot timer once, during
    RuntimeCoordinator::initialize() (single-threaded, before any other
    task exists), specifically to avoid a first-use creation race between
    tasks that both want to trigger a reboot.
2026-08-01 feat(ota): update firmware from GitHub Releases without touching images
    Add pf_ota, an admin-triggered (no background polling) worker that
    checks a GitHub Release's tag_name against the running firmware
    version and, when told to, downloads and flashes the release asset
    into the inactive OTA partition via esp_https_ota's stepwise API.
    webfs/imagefs are never touched -- OTA only ever writes to whichever
    partition esp_ota_get_next_update_partition() selects, and the
    partition table itself (frozen by ADR-0004) is untouched by this
    commit.
    Enables CONFIG_BOOTLOADER_APP_ROLLBACK_ENABLE so the bootloader can
    automatically revert to the previous slot if a new build crash-loops
    before the app confir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
2026-08-01 feat(web): expose diagnostics, reboot, OTA and live dashboard fields
    Add GET /api/v1/events (paginated via ?since=<sequence_id>, rejects
    truncated/overflowing values with 400 instead of silently defaulting
    to "no since given"), POST /api/v1/system/reboot (arms the reboot
    before replying so the response reflects whether it actually
    succeeded), and GET/POST /api/v1/system/ota/* wired to pf_ota.
    serialize_status's carousel.current_image/next_refresh_ms move from a
    hardcoded null literal to real values sourced from RuntimeSnapshot,
    and gain reboot_reason/diagnostics counters alongside the existing
    runtime fields -- all still null-safe when the carousel has never
    successfully completed a refresh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
2026-08-01 fix(network): refuse to start AP when DMA heap is critically low
    On real hardware, starting the AP radio while free DMA-capable heap
    was critically low crashed inside Espressif's closed-source WiFi blob
    (LoadProhibited in ieee80211_hostap_attach, reached via
    wifi_softap_start), preceded by a failed 752-byte beacon-buffer
    allocation the blob does not handle gracefully. That path cannot be
    patched from application code.
    start_access_point() now checks heap_caps_get_largest_free_block(
    MALLOC_CAP_DMA) before touching any Wi-Fi mode/config, ahead of the
    existing esp_wifi_start() call for all of its callers (blank-NVS first
    boot, STA-retry-exhausted fallback). Below the safety margin, it
    reports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
2026-08-01 feat(app): wire reboot reason, OTA worker and carousel status into boot
    app_main.cpp now captures esp_reset_reason() into the initial
    snapshot, starts the OTA worker alongside the other background
    services, confirms the running image valid (cancelling any pending
    bootloader rollback) once every core service has attempted to start,
    and publishes the carousel's current image id / next due time after
    each successful refresh (left unchanged on a failed refresh, since the
    panel's actual displayed content didn't change).
2026-08-01 feat(webui): add system page and complete dashboard fields
    Enables the previously-disabled "系統" nav entry and adds its view:
    panel/network/reboot-reason status, capacity and firmware version,
    OTA check/update controls with progress and error display, a reboot
    button, and a recent-diagnostics-events list. Reboot and OTA-update
    have a confirmation dialog; OTA-update polls system status every 3s
    while in flight so the page reflects completion/failure on its own
    instead of requiring a manual refresh.
    Also fixes a pre-existing Dashboard bug in passing: weather/sensor
    state rendering only ever distinguished "unavailable" from "unknown",
    silently ignoring the "available"/"stale" states the API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
2026-08-01 docs: sync Phase 8 progress and hardware validation gaps
    Updates IMPLEMENTATION_PLAN.md's checkpoint and acceptance-tracking
    table, WEBUI.md's route table and view list, and appends the
    2026-08-01 on-device findings to VALIDATION.md: the AP-start crash
    discovery/fix/confirmation, the resulting removal of the manual
    "force recovery AP" control (it couldn't succeed at the hardware's
    actual free-heap level and didn't correspond to a real need -- the
    existing automatic STA-unreachable fallback already covers it), and
    the still-open on-device validation list (real GitHub OTA/rollback,
    reboot-reason after a real panic, OTA worker stack high-water-mark,
    weather+OTA concurrent heap). Adds RELEASE_CH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
2026-08-01 fix(storage): refresh imagefs capacity instead of using boot-time snapshot
    imagefs_used_bytes/webfs_used_bytes were sampled once at boot in
    mount_all() and baked into the initial RuntimeSnapshot, but never
    refreshed afterward, so the WebUI's capacity display stayed frozen at
    whatever the partition held at boot regardless of later uploads or
    deletes.
    Sample imagefs usage inside StorageWorker::store_image()/remove_image()
    while their OperationGuard is still held (so the sample can never
    straddle a concurrent mutation's in-progress write), tag it with the
    catalog's own monotonic generation counter, and republish it through a
    new RuntimeCoordinator::update_imagefs_used_bytes() setter that drops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
2026-08-01 docs: add ADR for PFR1 payload compression and catalog cap
    Records the decision to add an optional deflate-raw compressed
    payload flag to PFR1 (browser-side compression only, ROM miniz
    inflate on-device) and raise kCatalogMaxEntries from 48 to 96, since
    the 48-entry cap is the current binding constraint on imagefs
    capacity, not raw flash bytes.
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2026-08-01 feat(pf_carousel,app): decode compressed PFR1 on the display path
    Fix an existing bug in Pfr1FrameDecoder::finish_and_compose: it passed
    header.payload_length as the decoded-payload length to
    compose_landscape/compose_portrait. That field becomes the compressed
    byte count once Pfr1Flags::kCompressed is set (commit 2), while
    payload_ always holds the decoded (decompressed, if applicable)
    nibble bytes -- use pf_image::expected_payload_length(width, height)
    instead, which is unaffected by compression.
    Thread an optional Pfr1InflateBuffers through Pfr1FrameDecoder and
    render_carousel_image so the carousel can display compressed images.
    app_main.cpp allocates two PSRAM scratch buffers once at st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
2026-08-01 feat(pf_storage,pf_web): raise catalog cap to 96 entries
    kCatalogMaxEntries is a pure policy constant (count is a 2-byte wire
    field, no format ceiling), and imagefs free-space precheck -- not
    this constant -- is the actual guard against overflow, so raising it
    just gives compressed-heavy libraries (see docs/adr/0009) more room
    without bypassing that safety net.
    Fix a bare 512-byte literal in health_server.cpp's image-reorder body
    handling that was independent of kCatalogMaxEntries: derive
    kImageOrderBodyCapacity from the constant instead, so a full 96-entry
    catalog can still be reordered (the old fixed 512 would silently
    reject a reorder request once the catalog grew past roughly 46
    entries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
2026-08-02 fix(pf_storage): revert catalog cap to 48 after on-device RAM failure
    On-device testing on real ESP32-S3-N16R8 hardware found that raising
    kCatalogMaxEntries to 96 (ADR-0009) breaks image upload and mutation
    (activate/reorder/delete): both operations allocate their FreeRTOS
    task stack on demand from internal SRAM (heap_caps_calloc with
    MALLOC_CAP_INTERNAL), a design that was already tuned to a thin
    margin at 48 entries (per existing comments in health_server.cpp).
    The ~46 KB of static BSS growth from raising the cap left too little
    contiguous internal RAM for the 24 KB mutation task stack to
    allocate at all, regardless of what pio run's static RAM percentage
    suggested (62.6% used, 37% "free"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
2026-08-02 fix(pf_web): defer weather/sensor config task-stack allocation
    weather_config_task_stack/sensor_config_task_stack (4,096 bytes
    each) were permanently-resident static arrays, unconditionally
    xTaskCreateStatic'd at httpd_start() time -- unlike image
    upload/mutation/download, which already use start_deferred_task to
    allocate their (larger, 8-24 KB) stacks on demand only when the
    first request actually arrives. These two config endpoints are hit
    far less often than image upload, so the asymmetry was pure waste.
    Convert both to the same two-phase pattern: httpd_start() only
    creates the queue (start_worker=false); the POST handlers call
    start_weather_config_task(true)/start_sensor_config_task(tru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
2026-08-02 docs(adr): add ADR-0011 for PSRAM/flash cache-disable safety
    Investigates whether the already-shipped PFR1 compression feature's
    PSRAM scratch buffers (inflate_compressed_scratch_/
    inflate_output_scratch_, carousel_payload/carousel_status/
    carousel_inflate_*) are safe against ESP32-S3's flash/PSRAM shared
    cache-arbitration -- the same class of risk that forced a full revert
    of an OTA buffer previously (see ADR-0010's RAM refactor context).
    Traced all three PFR1-related I/O paths (upload/mutation write path,
    carousel display read path, boot-recovery read path) down to
    esp_flash_write()/esp_flash_read(): none of them ever pass a PSRAM
    pointer directly to filesystem.write()/read() -- data is a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
2026-08-02 docs(validation): record first-round hardware verification for Phase 1
    Real ESP32-S3-N16R8 log after flashing the Phase 1a/1b/1c RAM-reclaim
    commits: image_upload_stack_free_bytes/image_mutation_stack_free_bytes
    match ADR-0010's original 48-entry baseline almost exactly, confirming
    the 57.8KB reclaimed by Phase 1 didn't come out of those tasks'
    margins. Carousel display (exercising Phase 1c's carousel_status)
    queued and refreshed successfully twice. User confirmed upload/
    activate/delete over WiFi works via WebUI.
    Explicitly flags what this round did NOT cover: post-reboot recovery
    correctness (Phase 1a) and cold-boot first weather/sensor config form
    submission (Phase 1b) still need a follo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
2026-08-03 fix(display): move weather into empty sensor slot
    [status_bar_renderer.hpp]
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2026-08-22 fix(sensors): stop serving a dead sensor's last reading as current
    Unplugging a DHT22 that had just read successfully left the API reporting
    `"status":"online"` with the pre-unplug 26.8C/64.2% attached, on every tick
    that did not happen to be a retry tick, for the full five-minute cache
    window. The status flapped between stale and online depending on which tick
    a caller happened to poll.
    The non-retry branch of sample_environment derived the status from cache
    age alone and ignored consecutive_failures entirely. One failed read is
    already proof the sensor is not answering; from that moment the cached
    value is history, and reporting it as online is the "沿用歷史值" the
    optional-sensor co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
    [sensor_task_esp_idf.cpp]
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2026-08-23 docs(enclosure): name the parts as designed and number them by assembly order
    My names were inferred from bounding boxes and got four of six wrong: the
    flat 176x116x3 plate is the screen's back shell, not a front window; the
    176x116x4 plate with rails is the electronics back panel, not a tray; and
    the stand and its pivot were swapped.
    Renamed to the designer's identification, with the numeric prefix now
    carrying the stack order rather than an arbitrary sequence, so someone
    printing the set can assemble in filename order:
    01 screen back shell / panel / 02 outer frame /
    03 electronics back panel / electronics / 04 stand /
    05 frame back panel / 06 stand pivot
    The original epaper-screen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
    [01-screen-back-shell.step, 01-screen-back-shell.stl, 02-outer-frame.step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]
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2026-08-23 docs(enclosure): swap the stand and its pivot
    Confirmed by the designer: epaper-screen-5, the 16x11x16 domed piece, is
    the stand's pivot, and epaper-screen-6, the 30x88x4 tongue, is the stand
    itself -- which is what the geometry suggested. The stacking order is
    unchanged; only the two names were transposed, so the sequence now reads
    pivot, frame back panel, stand.
    [04-stand-pivot.step, 04-stand-pivot.stl, 06-stand.step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]
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2026-08-29 fix(sensors): stop light ADC saturation from collapsing presence to unknown
    An ADC pinned at its rail (raw <= 10 or >= 4085) was reported as
    saturated and excluded from away/present detection entirely. When both
    photoresistors clipped dark at once (reproduced on hardware
    2026-08-27), presence collapsed to unknown mid-debounce and reset the
    away countdown, leaving the panel refreshing instead of blanking in a
    dark room.
    Split saturated into low_clipped/high_clipped: both now participate in
    presence normally, deciding direction from status rather than
    comparing the clipped raw against threshold (threshold is a
    user-editable 0-4095 field with no guarantee it avoids the rails,
    which would other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
    [sensor_task_esp_idf.cpp]
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2026-09-03 fix(sensors): stop indoor stale window from blanking the status bar
    A single DHT22 read failure flipped environment_status to stale until
    the next successful retry, and build_status_bar_content() hid the whole
    indoor block whenever status wasn't online. With the old 300s staleness
    window and the default 30-minute carousel refresh, a transient hiccup
    could make indoor temp/humidity disappear for a full refresh cycle even
    though the sensor typically recovers within a minute or two.
    Widens the staleness window to 3600s (matching pf_weather's) and slows
    routine polling to 120s (reduces DHT22 self-heating error; independent
    of the staleness fix). Adds an indoor_stale flag mirroring the existing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
    [status_bar_renderer.hpp]
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

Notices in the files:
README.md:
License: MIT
